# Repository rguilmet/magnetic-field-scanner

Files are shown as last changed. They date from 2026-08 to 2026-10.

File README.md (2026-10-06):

# Magnetic Field Scanner (MFS) Wand


[]()
[]()
[]()

A professional-grade, open-source spatial magnetic gradiometer designed to detect buried ferromagnetic anomalies (property pins, pipes, UXO) by isolating highly localized magnetic gradients from the Earth's background magnetic field.

Powered by an ESP32-S3 and utilizing dual PNI RM3100 magneto-inductive sensors, this device achieves nanotesla-level sensitivity, executing 9-parameter ellipsoidal matrix calibrations and real-time Madgwick AHRS sensor fusion to provide an intuitive, HUD-style radar interface on a high-speed LCD.

---

<p align="center">
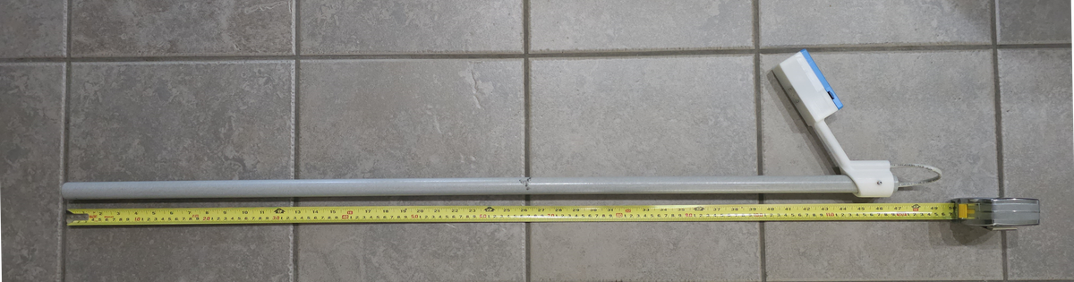
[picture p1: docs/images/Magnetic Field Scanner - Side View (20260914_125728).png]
Magnetic Field Scanner Hardware Side View
  
</p>
<p align="center">
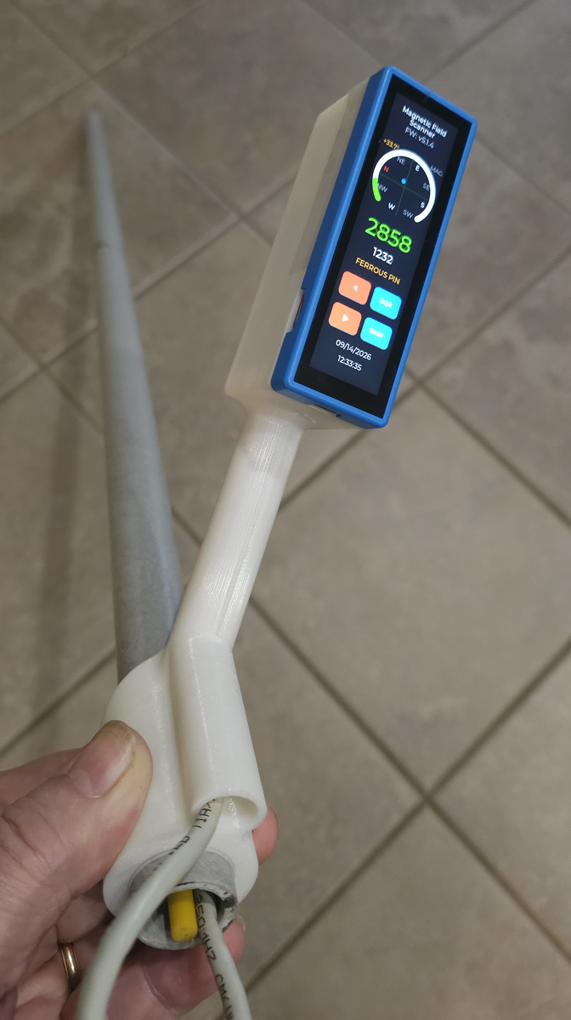
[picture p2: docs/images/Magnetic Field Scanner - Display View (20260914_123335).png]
Magnetic Field Scanner LCD Display View
  
</p>

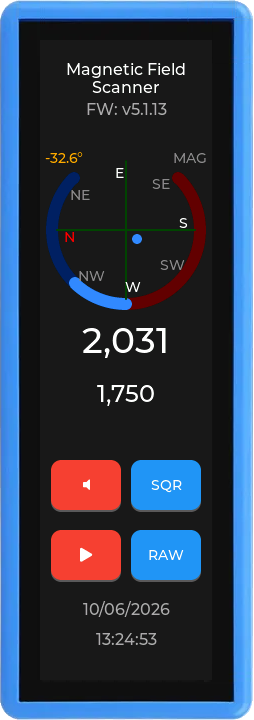
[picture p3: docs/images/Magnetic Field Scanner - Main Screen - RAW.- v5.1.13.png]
HUD Interface - RAW Mode
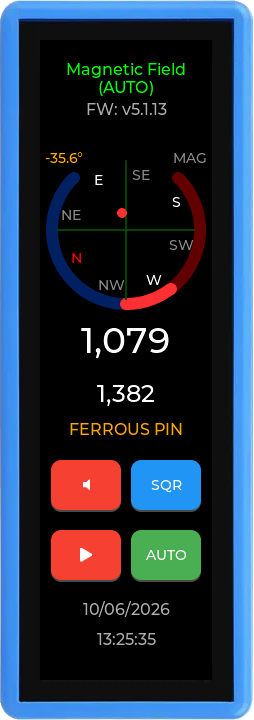
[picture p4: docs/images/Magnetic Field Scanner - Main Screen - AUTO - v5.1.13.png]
HUD Interface - AUTO Mode
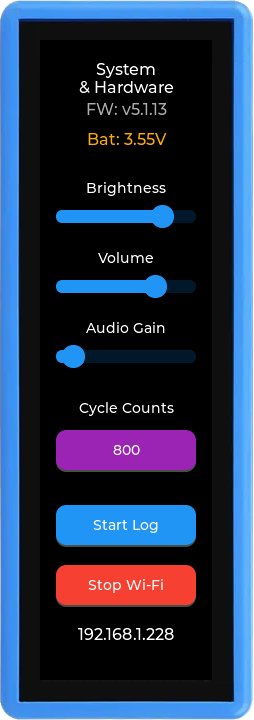
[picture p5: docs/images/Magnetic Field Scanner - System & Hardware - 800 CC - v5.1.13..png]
System Hardware and Diagnostics Screen
|  |  |  |
|:---:|:---:|:---:|

## Hardware Configuration

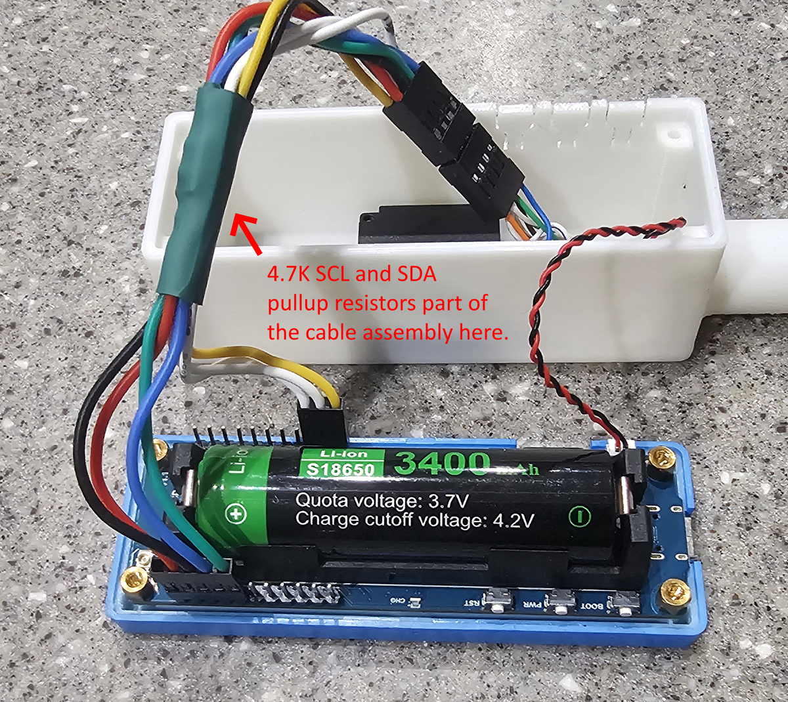
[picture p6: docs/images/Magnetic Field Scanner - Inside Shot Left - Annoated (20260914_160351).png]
Internals Left (I2C Pull-ups)
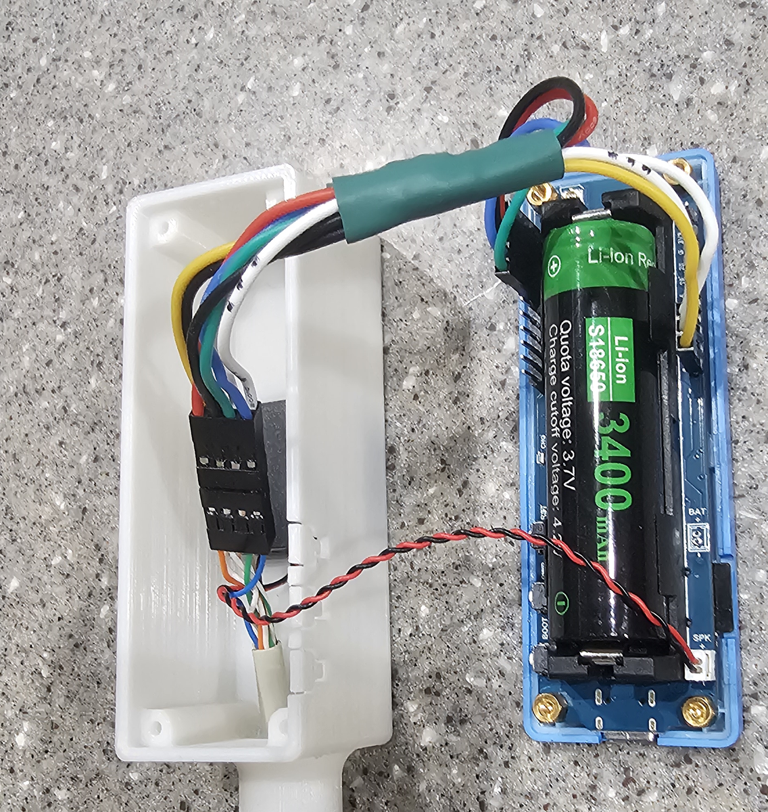
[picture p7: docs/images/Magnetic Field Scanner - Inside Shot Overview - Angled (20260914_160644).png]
Internals Overview
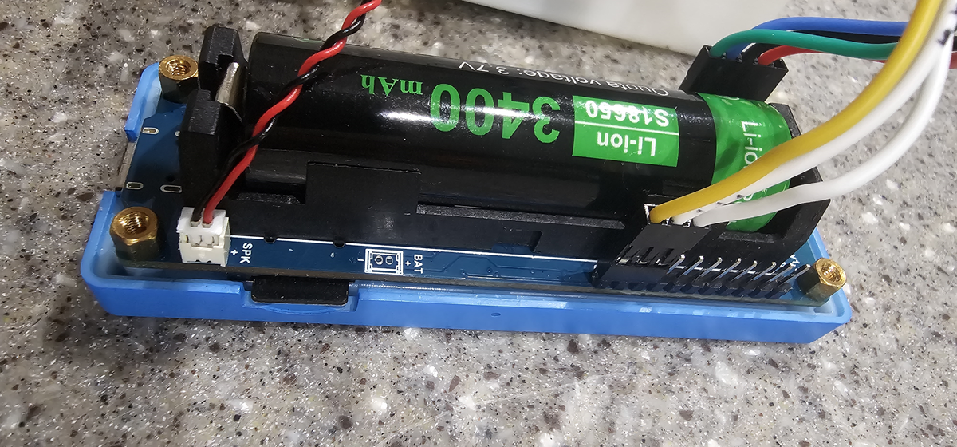
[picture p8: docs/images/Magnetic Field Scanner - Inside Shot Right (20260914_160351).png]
Internals Right
|  |  |  |
|:---:|:---:|:---:|

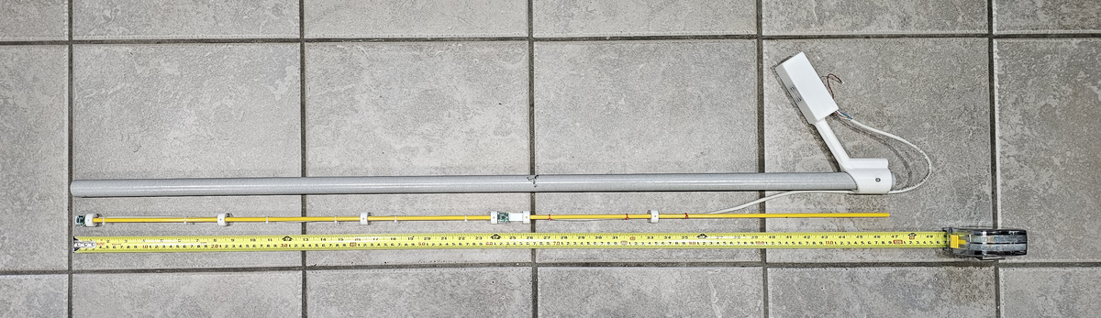
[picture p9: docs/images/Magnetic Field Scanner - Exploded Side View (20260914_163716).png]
Exploded Side View
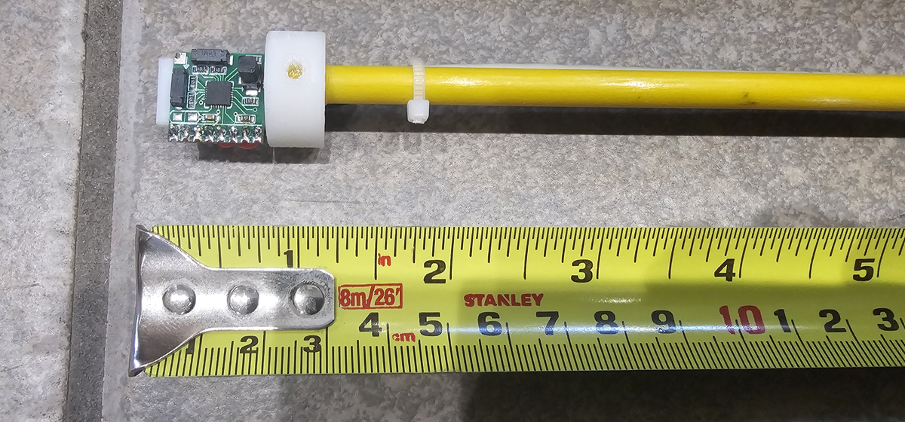
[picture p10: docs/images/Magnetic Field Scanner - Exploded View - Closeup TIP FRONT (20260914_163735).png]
TIP Sensor Front
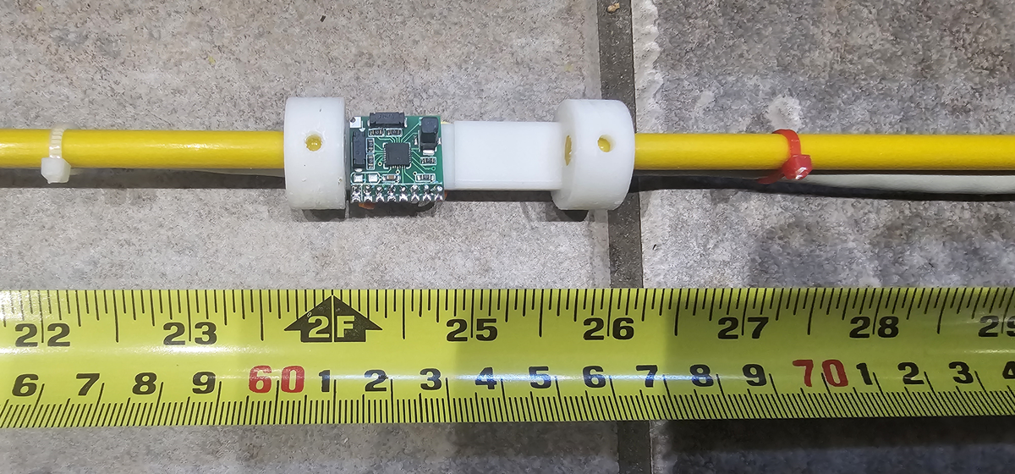
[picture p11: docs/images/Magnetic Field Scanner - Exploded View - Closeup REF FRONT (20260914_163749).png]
REF Sensor Front
|  |  |  |
|:---:|:---:|:---:|

### Core Components
* **Base Platform:** Waveshare ESP32-S3-Touch-LCD-3.49 v3 (PCBA v1.1 silkscreen). This highly integrated device provides the MCU, display, audio, and power management core.
* **MCU:** ESP32-S3 (16MB Flash, OPI PSRAM) embedded on the Waveshare board.
* **Magnetometers:** 2x RM3100 (TIP (at 0") and REF (at 24") sensors), with hardware reserved for a 3rd (NEAR at 8").
* **IMU:** QMI8658 (6-axis Accelerometer & Gyroscope) offset mechanically by 60° relative to the wand axis.
* **Display:** 172x640 QSPI LCD with capacitive touch.
* **Audio Codec:** ES8311 / ES7210 via I2S for audio feedback.
* **Storage:** External SPI SD Card + Internal FFat (Flash).
* **Wiring:** See the [MFS Wiring Diagram](docs/electrical/wiring/MFS_Wiring_Diagram.png).
* **RTC:** PCF85063 for precise timestamping.
* **I/O Expander:** TCA9554 to offload static control pins (Backlight, Resets) and free up high-speed GPIO.

---

## Pin Allocations & Rationale

To support this many peripherals on a single ESP32-S3, strict pin management and an I2C I/O expander are utilized. 

| Feature | GPIO / Pin | Protocol / Type | Rationale |
| :--- | :--- | :--- | :--- |
| **I2C Bus** | SDA: 47, SCL: 48 | I2C | Shared bus for RM3100s, IMU, RTC, and TCA9554 IO Expander (capped at 200kHz for cable capacitance). |
| **I2S Audio** | MCLK: 7, BCLK: 15, WS: 46, DIN: 6, DOUT: 45 | I2S | Full duplex audio codec interface. |
| **SD Card** | CS: 38, MOSI: 39, MISO: 40, SCLK: 41 | SPI | Dedicated high-speed SPI bus for high-bandwidth data logging. |
| **LCD Display** | CS: 9, PCLK: 10, D0-D3: 11, 12, 13, 14, TE: 21 | QSPI / 8080 | High-speed bus dedicated to driving the 172x640 LVGL display. |
| **Battery ADC** | 4 | Analog (ADC1) | Dedicated for battery voltage monitoring. |
| **RM3100 DRDY** | TIP: 3, REF: 2, NEAR: 5 | Interrupt | Direct hardware interrupts for DRDY synchronization. |
| **Future GPS** | TX: 43, RX: 44 | UART | Reserved. Freed up by migrating static control pins to the IO Expander. |

### TCA9554 I/O Expander (Address 0x20)
Used to handle low-speed/static signals to conserve MCU pins:
* **P0:** Touch Interrupt
* **P1:** LCD Backlight Enable
* **P2 / P3:** IMU Interrupts 1 & 2
* **P4:** RTC Interrupt
* **P5:** LCD Reset
* **P6:** System Power Enable (Keep-alive)
* **P7:** Night/Sleep Mode

---

## Software Architecture (v5.x.x)

The software is built on the Arduino ESP32 Core but heavily utilizes ESP-IDF native features and FreeRTOS for professional-grade isolation and performance.

### 1. Synchronized POLL Architecture & FreeRTOS
The `v5.x.x` architecture completely eliminates I2C collisions and phase-drift by orchestrating synchronized measurements:
* **POLL Mode:** The ESP32 broadcasts a simultaneous `REG_POLL` command to both RM3100 sensors across the I2C bus.
* **Event Groups (Core 0):** The Sensor Task sleeps at 0% CPU until both hardware `DRDY` GPIO interrupts assert, guaranteeing absolute temporal synchronization between the Tip and Reference sensors before reading.
* **LVGL UI Task (Core 1):** Handles display rendering, capacitive touch input, and real-time radar / minimap animations without interrupting the rigid I2C sensor polling pipeline.

### 2. Deep Mathematics: Kabsch & Madgwick Algorithms
To achieve military-grade spatial accuracy, the ESP32 natively executes advanced matrix mathematics and 9-axis sensor fusion:
* **Kabsch Rotational Alignment:** The system applies a 9-parameter Least-Squares Ellipsoid Fit (using a Jacobi Eigenvalue solver and the Kabsch Algorithm) to correct for Hard and Soft Iron magnetic distortions caused by the battery and LCD.
* **Madgwick 9-Axis Sensor Fusion:** The raw 3-axis Tip magnetometer data is fused with the QMI8658's 6-axis IMU (Accelerometer and Gyroscope) via an asynchronous Madgwick AHRS filter. This provides real-time Pitch, Roll, and Yaw (Azimuth) compensation to project the magnetic vector accurately to the Earth's gravity vector.
* **Universal Domain Shifting:** The `v5.1.x` architecture converts raw sensor LSBs into normalized physical nanoTeslas (nT) *before* applying the Kabsch calibration matrix. Because the matrix becomes mathematically dimensionless, a single calibration profile works universally across ALL Cycle Counts (12 to 3200).

### 3. Polargraphic Display & UI Scaling
The LVGL Gradiometer UI features a true Log10 Polargraphic Arc that displays the vertical gradient (`trueZ`). The left side (Blue) represents a negative vertical gradient (the 'halo' outside a pin), and the right side (Red) represents a positive vertical gradient (dead-center over a pin).
* **RAW Mode:** Displays the absolute, unadulterated magnetic gradient. The Log10 scale easily absorbs the baseline physical misalignment of the sensors (typically ~4,900 nT) without pinning the needle.
* **TARE Mode:** Manual zeroing of the baseline. It memorizes the current environmental gradient shadow and subtracts it from future readings, allowing extreme sensitivity to tiny localized anomalies.
* **AUTO Mode:** Engages an invisible low-pass filter (triggered under `150 nT`) that acts as an aggressive Auto-Tare to slowly eat away temperature drift and background anomalies while ignoring the sharp gradients of a real target.

### 4. Dual-Drive Filesystem & Integrated Web Server
* **Smart Fallback:** Dynamically routes file I/O to the high-speed SD Card, or falls back to Internal FFat if the card is missing or corrupted.
* **Captive Portal:** Hosts a Web Server allowing seamless download of `.csv` characterization logs and upload of `calibration.json` profiles.

---

## Real-World Capabilities & Detection Depth

The Magnetic Field Scanner is designed as a spatial gradiometer. Because it relies on an empirical RMS noise floor of **±0.33 µT** (at 400 CC), it is highly sensitive to buried ferromagnetic objects.

### Use Case: Locating Property Pins (5/8" Rebar)
A standard 5/8" steel property pin driven vertically into the earth acts as a magnetic monopole, concentrating the Earth's magnetic flux at its tip. 

**Estimated Detection Depth:**
- A vertical 5/8" property pin generates a surface anomaly of roughly `500 µT` at 1 inch.
- Because the wand is a gradiometer with a long handle, the near-field gradient of a monopole decays according to the inverse-cube law (`1/r³`).
- To be reliably detected above the wand's noise floor, the signal needs a minimum Signal-to-Noise Ratio (SNR).
- In a magnetically quiet environment (RAW mode), you can expect to reliably detect a standard vertical property pin buried under **1.5 to 2 feet (18 to 24 inches)** of dirt or concrete.

### Practical Tips for Pin Locating
- **Sweep Low:** Keep the tip sensor as close to the ground as possible. Every inch of air gap costs you an inch of dirt penetration.
- **Use Audio:** Rely on the dynamic FOC audio feedback. The human ear is incredibly adept at picking up the slow frequency rise of a deep anomaly long before the UI screen indicates a massive spike.
- **Vertical vs Horizontal:** Property pins driven vertically are *much* easier to detect than pipes lying horizontally, because the vertical rod concentrates the Earth's magnetic field directly into a concentrated point (a monopole) at the surface.

---

## System Characterization

The wand features a rigid characterization methodology to empirically validate its hardware envelope across multiple Cycle Counts (CC=200, 400, 3200). 
To test your hardware, use the included Python script on your generated `.csv` logs:

```bash
python scripts/characterize_system.py   --noise "log_noise_200.csv" "log_noise_400.csv" "log_noise_3200.csv"   --target "log_target_200.csv" "log_target_400.csv" "log_target_3200.csv"   --ahrs "log_ahrs_200.csv" "log_ahrs_400.csv" "log_ahrs_3200.csv"   --repeatability "log_repeat_200.csv" "log_repeat_400.csv" "log_repeat_3200.csv"   --saturation "log_saturation_200.csv" "log_saturation_400.csv" "log_saturation_3200.csv"   --calibration "cal_1.csv" "cal_2.csv" "cal_3.csv" "cal_4.csv" "cal_5.csv"
```
See `docs/characterization_methodology.md` for full instructions.

---

## Future Expansion Roadmap

The hardware architecture has been deliberately designed to accommodate future capabilities without requiring a PCB spin:

### 1. 3D Depth Sensing (3rd RM3100)
A dedicated interrupt pin (GPIO 5) and I2C address (0x22) have been reserved for a 3rd RM3100 sensor (NEAR). 
* **Purpose:** Enables 2nd-order magnetic gradiometry, allowing the wand to calculate the exact depth of a magnetic anomaly (e.g., a buried pipe) rather than just its presence.

### 2. Spatial Mapping (GPS / RTK)
The static control pins for the LCD and IMU were aggressively offloaded to the TCA9554 I/O expander specifically to free up the hardware UART pins:
* **TX (GPIO 43) / RX (GPIO 44):** Reserved for a high-precision GPS or RTK module. This will allow the wand to fuse magnetic gradient data with precise geographic coordinates, generating professional magnetic survey heatmaps.

## How to Build & Deploy

### Prerequisites
* **Environment:** Arduino IDE v2+ or VSCode/Arduino.
* **Core:** ESP32 Board Package v3.3.x (ESP-IDF v5 based).

### Board Settings (ESP32-S3 Dev Module)
* **USB Mode:** Hardware CDC and JTAG
* **PSRAM:** OPI PSRAM
* **Flash Mode:** QIO 80MHz
* **Flash Size:** 16MB (128Mb)
* **Partition Scheme:** Custom or `app3M_fat9M_16MB`
* **Core Debug Level:** None (for performance)

### Compilation Note
All code files adhere to a strict Semantic Versioning (`vX.Y.Z`) rule enforced at every file iteration. Ensure you are building the latest `user_config.h` baseline.

## Open Source & Contributing
This project is open-sourced under the **GPLv3 License**. See [LICENSE](LICENSE) for details.
We welcome community contributions! Please review our [Contribution Guidelines](CONTRIBUTING.md) before submitting pull requests.

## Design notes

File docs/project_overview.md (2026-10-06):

# Magnetic Field Scanner - Project Overview

**Document Version:** `v1.4.0`
**Last Updated:** October 06, 2026
**Firmware Target:** `v5.1.15`
**Python Ecosystem Target:** `v1.1.1`

This document serves as the master source of truth for the Magnetic Field Scanner project. It details the mechanical assembly, electrical wiring, pinouts, firmware architecture, critical pitfalls to avoid in future development, and the roadmap for upcoming features.

---

## 1. Project Identity, Versioning & Documentation Rules
* **CRITICAL RULE:** All projects shall have a main Software version identifier as `v[Major].[Minor].[Patch]` and follow industry standard semver rules and practices for bumping the version at EVERY file iteration.
* **Why:** We do not reuse version numbers for each iteration. This allows us to distinctly identify in the AI context the files we are working on. The version string is defined as `FIRMWARE_VERSION` in `user_config.h`.

**Documentation Strategy (The "Definition of Done"):**
To prevent documentation rot and excessive maintenance overhead, documentation updates are strictly tethered to the SemVer lifecycle:
* **Patch Releases (e.g., `v3.1.1` -> `v3.0.33`):** Bug fixes and math tweaks. Do *not* update the architectural docs (`project_overview.md`, `user_manual.md`). Log these changes exclusively in the root `CHANGELOG.md`.
* **Minor Releases (e.g., `v3.0.x` -> `v3.1.0`):** Adding new functional features (e.g., GPS integration). The feature is not considered complete until both the `CHANGELOG.md` and the relevant `docs/` Markdown files are updated to reflect the new capabilities.
* **Major Releases (e.g., `v3.x` -> `v4.0.0`):** Massive architectural overhauls (e.g., migrating from I2C to CAN bus). Triggers a comprehensive review and rewrite of all files in the `docs/` directory.

---

## 2. Hardware Architecture & Mechanical Setup
* **The Wand:** Constructed from a rigid 1" fiberglass outer rod with a 3/4" ID.
* **Main Controller (The Handle):** Waveshare ESP32-S3-Touch-LCD 3.49 v2 (172x640 Bar LCD) with an integrated screen, battery ADC, IMU (QMI8658, addr `0x6B`), and RTC (PCF85063, addr `0x51`). This unit sits at the top of the wand acting as the primary handle and UI display. A custom wiring harness runs down from this unit into the main fiberglass tube.
* **The Sensor Array:** The wand acts as a **Magnetic Gradiometer**. It currently utilizes two PNI RM3100 magnetometer breakout boards ("Tip" and "Reference").
  * The boards are mounted to a PLA mechanical carrier that slides directly into the 3/4" ID of the fiberglass tube.
  * **Carrier Rigidity:** To ensure absolute rigidity between the Tip and Reference sensors, the PLA board carriers are physically joined to each other by a solid 1/4" internal fiberglass rod.
  * **Sensor Orientation:** The boards were recently flipped 180 degrees (upside down) in the assembly. 
  * **Physical Misalignment:** There is a permanent, measured physical flex/bend in the carrier assembly of roughly `~9.4` to `~9.8` degrees. The firmware mathematically eliminates this using the Kabsch alignment algorithm.

### True Vertical Gradient (trueZ) & Dipole Physics
In firmware v5.1.15, the wand implements true magnetic dipole physics. The absolute magnitude of the magnetic field (nT) is highly useful, but it does not tell the user *what* they are looking at or *where* the edges are. 
By projecting the 3D magnetic gradient vector against the Earth's Gravity (Down) Vector (which is derived from the IMU's quaternion), the wand isolates `trueZ`—the pure vertical component of the magnetic gradient.
* **Vertical Property Pins:** Behave as vertical magnetic dipoles. Sweeping dead center over the top pole (South pole) results in a massive POSITIVE `trueZ` (field lines pointing straight down). Sweeping off to the side results in a NEGATIVE `trueZ` (field lines pointing back up). This creates a sharp "halo" effect that allows pinpoint centering.
* **Horizontal Pipes / Rebar:** Behave as horizontal magnetic dipoles. Sweeping perpendicular across the center of a horizontal pipe yields massive absolute magnitude, but a `trueZ` of zero, because the field lines are purely horizontal.

### Polargraphic Display & Log10 Scaling
To visually represent the `trueZ` physics, the UI features a symmetrical Polargraphic Arc.
* **Polarity:** Left (Blue) represents Negative vertical gradient. Right (Red) represents Positive vertical gradient.
* **Log10 Scaling:** The arc is driven by a `log10((nT/100)+1)` curve. This provides extreme visual sensitivity to tiny signals at long range, while allowing the arc to dynamically scale all the way up to 1,000,000+ nT without "pegging" when the wand is an inch away from a massive target.

### Mechanical Diagram
(Assuming visual diagram exists elsewhere)

### Sensor Coordinate Systems & Axis Alignment (Phase 7 Discovery)
Because the BMI270 IMU and the dual RM3100 Magnetometers are mounted to the same rigid Wand structure, they must speak the exact same 3D spatial language for sensor fusion (Madgwick 9-DOF) to work. A live logging "Alignment Dance" revealed the exact physical orientation of the chips on the Veroboard. 

**The IMU (BMI270) Coordinate System (Right-Handed):**
* +X Axis: Points **Forward** (Towards the sensor tip)
* +Y Axis: Points **Left**
* +Z Axis: Points **Up** (Out of the LCD Screen)

**The Magnetometer (RM3100) Coordinate System (Left-Handed):**
Due to the physical mounting of the breakout boards inside the wand, the RM3100 acts as a Left-Handed coordinate system relative to the IMU.
* +X Axis: Points **Left**
* +Y Axis: Points **Forward**
* +Z Axis: Points **Down** (Into the ground)

**The Translation Key:**
To safely feed the Magnetometer data into the Right-Handed 9-DOF Madgwick algorithm, the software applies the following mathematical mapping to the RM3100 (
efX_cal, refY_cal, refZ_cal) values:
`c
float mag_x =  (float)ref.y;  // Maps RM3100 Forward to IMU Forward
float mag_y = -(float)ref.x;  // Maps RM3100 Right to IMU Left
float mag_z = -(float)ref.z;  // Maps RM3100 Down to IMU Up
`
This permanently locks the Quaternions to True Magnetic North for accurate post-analysis mapping.
*(Please place your mechanical drawing in a folder named `docs` in the project root and name it `mechanical_drawing.png` or update this link to point to it).*
Mechanical Drawing of Wand and Waveshare

---

## 3. Wiring & Pinout Assignments

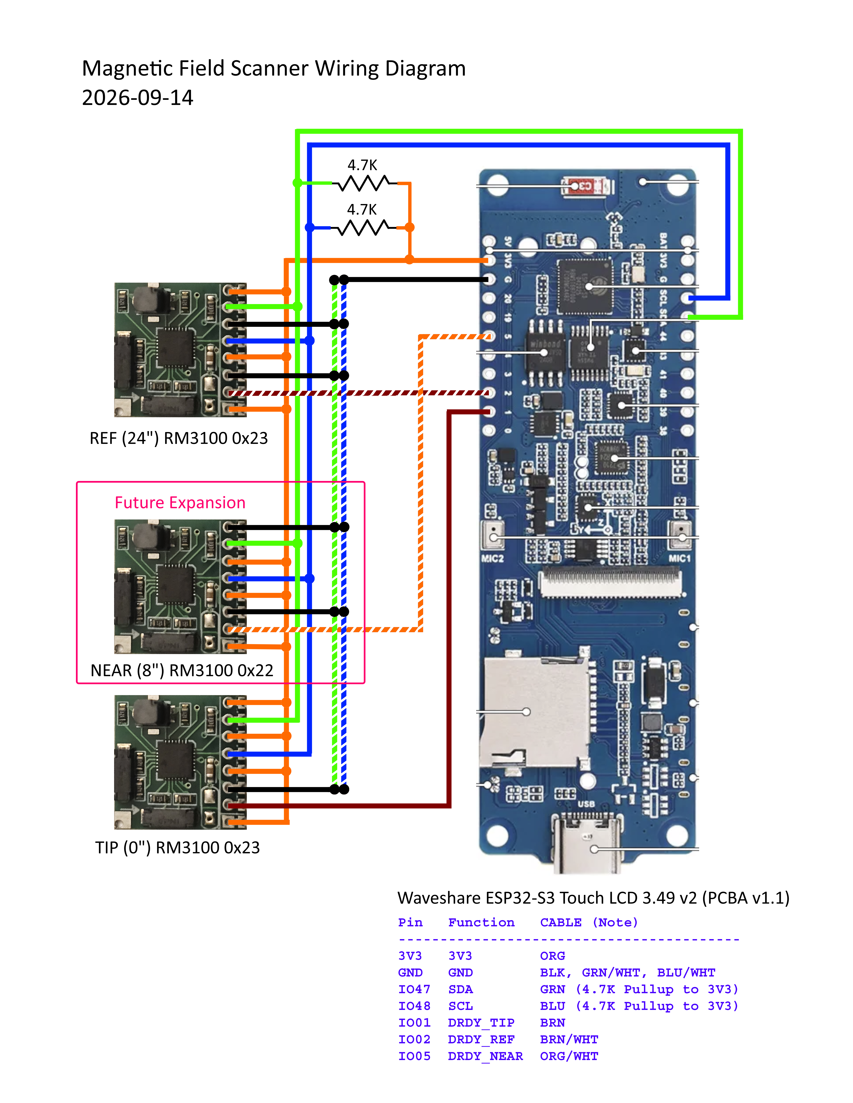
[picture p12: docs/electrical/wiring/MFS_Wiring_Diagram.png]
MFS Wiring Diagram


### CRITICAL HARDWARE NOTE: I2C Pull-Up Resistors
* **The RM3100 breakout boards DO NOT have built-in I2C pull-up resistors.**
* **The Fix:** We permanently installed **4.7K pull-up resistors** in the cable harness directly at the Waveshare connection end (SDA/SCL to 3.3V).
* **The Result:** Combined with the Waveshare's internal pull-ups, this provides a "stiff" ~2K to ~3K ohm equivalent resistance, which is perfect for fighting the heavy capacitance of the 3-foot cable run down the wand.

### CAT6 Wire Harness & Color Coding
The internal harness from the Waveshare board to the sensor array utilizes a standard CAT6 twisted-pair cable. It perfectly allocates all 8 wires to support three RM3100 sensors while maximizing electrical integrity over the 48" run.

For the full visual diagram, reference the spreadsheet: docs/electrical/Cable_Color_Code.xlsx.

| Component / Function | ESP32 Pin | CAT6 Color | Twisted Pair Strategy (Signal Integrity) |
| :--- | :--- | :--- | :--- |
| **3.3V Power** | 3V3 | Orange | **Power & Sync:** Twisted with DRDY_NEAR. DC power acts as an AC ground, shielding the digital pulse. |
| **DRDY_NEAR** | IO05 | Orange/White | *(Future 3rd Sensor)* |
| **SDA (Data)** | IO47 | Green | **I2C Data Shield:** Twisted directly with GND to prevent capacitive crosstalk against SCL. |
| **GND** | GND | Green/White | |
| **SCL (Clock)** | IO48 | Blue | **I2C Clock Shield:** Twisted directly with GND to prevent signal degradation. |
| **GND** | GND | Blue/White | |
| **DRDY_TIP** | IO01 | Brown | **Digital Sync:** Hardware data-ready interrupt signals. |
| **DRDY_REF** | IO02 | Brown/White | |

### I2C Architecture & Device Addresses
The wand utilizes two completely separate hardware I2C buses to isolate the sensitive long-wire sensors from the noisy high-speed screen components.

#### 1. I2C0 (External Sensor Bus)
* **Purpose:** Drives the long wire harness running down the 3-foot fiberglass tube to the RM3100 sensors.
* **Speed:** Hardcoded to **100kHz** to fight cable capacitance.
* **Pins:** SCL: `48`, SDA: `47`
* **Devices on Bus:**
  * **RM3100 Tip:** `0x23` (DRDY: `GPIO 1`)
  * **RM3100 Ref:** `0x21` (DRDY: `GPIO 2`)
  * **RM3100 Mid (Future):** `0x22` (DRDY: `GPIO 5`) *(Reserved for planned 3rd sensor)*
* **CRITICAL CONFLICT HISTORY (Address `0x20`):** Initially, an RM3100 was set to address `0x20`. This caused a total system failure because the Waveshare board has an undocumented internal I/O Expander hardcoded to `0x20`. **Never use `0x20` on the sensor bus**, even though the buses are logically separated; we mapped the RM3100s to `0x21`, `0x22`, and `0x23` to safely avoid any internal hardware routing conflicts.

#### 2. I2C1 (Internal Waveshare Bus)
* **Purpose:** Local communication for the Waveshare board's integrated SMD components.
* **Pins:** SCL: `18`, SDA: `17`
* **Devices on Bus:**
  * **Capacitive Touch Controller:** `0x3B`
  * **RTC (PCF85063):** `0x51`
  * **IMU (QMI8658):** `0x6B`
  * **I/O Expander:** `0x20` *(The source of the conflict mentioned above)*

### Other Master Pinouts (Defined in `user_config.h`)

| Component | Pin (GPIO) | Notes / Details |
| :--- | :--- | :--- |
| **SPI (SD Card)** | CS: `38`, MOSI: `39`, MISO: `40`, CLK: `41` | Used by `wifi_logger.cpp` to save `calibration.csv` and logs. |
| **GPS Module** | TX: `43`, RX: `44` | *Planned Future State.* |

---

## 4. Critical Engineering Decisions & Pitfalls to Avoid

### A. I2C Bus Speed & Time Constants
* **The Mistake:** Attempting to run the hardware I2C bus at 400kHz ("Fast Mode") over a 60-inch unshielded CAT6 cable. The physical capacitance caused mushy square waves. The ESP32 missed ACK bits, resulting in `0,0,0` readings, massive garbage spikes, and frequent "Sensor Lockup" panics. 100kHz was extremely stable but too slow for high-speed logging.
* **The Fix:** The I2C speed (`scl_speed_hz`) in `i2c_bsp.c` is hardcoded to `200,000` Hz. This is the "Goldilocks" zone that perfectly balances RC time constant degradation against the bandwidth needed to poll both sensors at 150Hz. 

### B. EMI "Meteors", Slew Rate, & Absolute Filters
* **The Problem:** Even at 200kHz, the long I2C wires act as antennas. Microscopic bit-flips (EMI glitches) occasionally jump the raw reading by 2,000 to 5,000 counts in a single frame, causing the audio UI to emit a terrifying shriek ("cosmic meteors").
* **Slew Rate Filter:** If any single axis on either sensor jumps by more than **800 counts** in a single frame, it is mathematically deemed physical EMI and the frame is dropped.
* **Absolute Magnitude Glitch Filter (MFS_MAX_GLITCH_MAGNITUDE):** Protects against catastrophic I2C garbage data (e.g. 140,000 counts). *CRITICAL PITFALL:* This threshold MUST be set >250,000. At CC=3200, the raw sensor gain is so massive that perfectly valid measurements hit ~120,000 LSB. Setting this threshold too low (e.g. 50,000) will cause the software to silently reject every single CC=3200 frame, freezing the display and log entirely!

### C. Watchdog Timer (TWDT) Panics
* **The Problem:** Processing a 3,000-line `calibration.csv` file from the SD card using `String` operations in `wifi_logger.cpp` takes more than 5 seconds. The ESP32 FreeRTOS Task Watchdog Timer assumed the system was frozen and triggered a hard panic reboot right at 99% completion.
* **The Fix:** Ensure heavy processing loops (like file parsing) contain a `vTaskDelay(pdMS_TO_TICKS(10));` every 100 iterations to "pet the watchdog" and yield to the OS.

### D. Sensor Lockup Logic & Hardware Watchdog
* **The Problem:** The I2C bus will occasionally hang due to environmental EMI. Previously, a 5000ms I2C driver timeout would starve the `IDLE0` task and trigger a fatal ESP32 Task Watchdog Panic reboot. 
* **The Fix:** The I2C driver timeouts (`i2c_data_pdMS_TICKS`) are clamped to `50ms`. If the bus hangs, it fails gracefully. The main `SensorTask` implements a robust software watchdog that resets the RM3100s via `initRM3100()` under three conditions:
  1. **Stuck Data:** If the sensor returns exactly `0,0,0` for 10 consecutive frames (I2C read failure). *CRITICAL PITFALL:* Do not trigger on identical valid values (e.g. `tip.x == last_tip.x`)! The RM3100 noise floor is so low that a perfectly still sensor will trigger false-positive lockups!
  2. **DRDY Timeout:** If the `DRDY` event group times out after **1000ms**. *CRITICAL PITFALL:* CC=3200 physics takes ~480ms to measure. If the timeout is set to 500ms, the ESP32 will panic and reset the sensor *before it finishes*, causing an infinite freeze loop!
  3. **Blind Recovery I2C Reads:** When recovering from a timeout, NEVER issue a blind `i2c_read_buff` to the RM3100 unless you have verified via `digitalRead()` that the DRDY pin is physically stuck HIGH. Reading a busy RM3100 will crash its internal silicon and permanently hang the I2C bus!

### D2. RM3100 TMRC Internal Glitching
* **The Physics:** `TMRC` defines the update rate in Continuous Measurement Mode. The datasheet claims that if `TMRC` is set faster than the Cycle Count allows, it will "automatically override" and run at max speed.
* **The Reality:** While true, constantly bombarding the RM3100's internal state machine with 600Hz `TMRC` ticks while it is busy calculating a slow 400 CC measurement causes random silicon glitches, resulting in the sensor missing beats and dropping `DRDY` (triggering the watchdog). 
* **The Fix:** `initRM3100()` must use a rigorous mapping table to ensure the `TMRC` value is always safely **slower** than the physical Cycle Count math execution time.

### E. Universal Cycle Count Scaling (v5.x.x)
* **The Physics:** When the user changes the Cycle Count (CC) on the fly, the RM3100's raw output scales non-linearly due to Zero-Field Offsets (ZFO).
* **The Code (Pre-Normalization):** To eliminate drift and scaling errors, the `v5.1.4+` architecture intercepts raw LSB counts and immediately normalizes them to physical nanoTeslas (`nT`) using the exact `CC` gain scalar *before* any calibration is applied.
* **Universal Matrices:** Because the Kabsch calibration algorithm now operates entirely in the physical `nT` domain, the resulting Hard and Soft Iron matrices are mathematically dimensionless. You can calibrate the wand at 400 CC, and perfectly seamlessly jump to 3200 CC without re-calibrating or scaling the matrices!

### F. Auto-Tare vs Manual Tare
* **Manual Tare:** Memorizes the current environmental gradient shadow (e.g., standing near a car) and subtracts it from all future readings. Should only be performed in a magnetically "clean" area.
* **Auto-Tare:** Implements a low-pass filter (multiplier `0.005`) that slowly and invisibly pulls the baseline back to zero over time. Crucially, it **only engages if the gradient jumps by less than 150 nT**. This eats away slow temperature/geology drift while completely ignoring the sharp spikes of a buried utility pipe!

### G. Windows CLI Path Handling (Python)
* **The Problem:** When dragging and dropping files into Windows PowerShell or Command Prompt to pass arguments to Python scripts, Windows automatically wraps the filepath in literal double-quotes (e.g., `"C:\path\to\file.csv"`). Python's `argparse` absorbs these literal quotes as part of the string, causing `os.path.exists()` to fail and crash the script. 
* **The Fix:** All Python companion scripts in this project universally sanitize `argparse` inputs using `os.path.normpath(args.input.strip('\'"'))` before interacting with the file system. This strips accidental terminal quotes and normalizes slashes, bulletproofing the CLI against Windows pathing quirks.

---

## 5. Current State of the Project
* **Core Functionality:** The Gradiometer math (`Tip - Ref`) is fully operational and extremely sensitive.
* **On-Device Calibration:** Functional. `matrix_math.h` performs a 9x9 Jacobi eigenvalue solver and 3D ellipsoid fit using only local stack memory. It applies Kabsch alignment to precisely orient the Tip sensor onto the Reference sensor's frame, nullifying the 9-degree mechanical flex.
* **Data Logging:** SD card saving is stable. Python companion scripts (`calibrate_wand.py` and `plot_pins.py`) can ingest `_log.csv` and `_calibration.csv` files to visualize the exact sweeping motions using IMU Gyroscope Z-axis tracking.
* **Audio & UI:** LVGL runs successfully on Core 1 while the bitbanging/I2C sensor tasks run on Core 0. (Note: `lv_conf.h` must remain in the root directory due to library constraints).

---

## 6. Companion Software Ecosystem (Python)
The repository includes a suite of offline Python processing scripts located in the `scripts/` directory. All official scripts adhere to SemVer versioning, contain industry-standard header documentation, and utilize `argparse` for robust command-line `--help` functionality.

* **`calibrate_wand.py`:** Ingests raw `calibration.csv` datasets, computes the 3x3 Soft-Iron matrices (W) and Hard-Iron center offsets (V), applies Kabsch rotational alignment, and outputs a drop-in `calibration.json` file.
* **`generate_plots.py`:** Specialized utility for visualizing 3D ellipsoid point clouds to verify the mathematical perfection of the sphere-fitting algorithms.
* **`analyze_log.py` (Formerly `plot_pins.py`):** Ingests live field operation logs (`_log.csv`) and generates a synchronized 3-pane matplotlib dashboard showing Gradient Magnitude, Audio Frequency response, and IMU Gyroscope Z-axis (Yaw) to visually correlate physical sweeping motions with underground utility strikes.

---

## 7. Planned Future State (Roadmap)
1. **Third Sensor Integration (Near):** 
   * A third RM3100 sensor will be mounted at 8 inches from the TIP.
   * I2C Address: `0x22`
   * DRDY Pin: `GPIO 5`
   * Purpose: To allow quadratic gradient tracking and depth-estimation of buried targets.
2. **GPS Module Integration:**
   * Serial unit to be added to pins `IO43` (TX) and `IO44` (RX).
   * Purpose: To embed geospatial coordinates into the SD log files, allowing post-processing software to map buried utilities directly onto a satellite view.

## 8. Sensor Fusion (Madgwick 9-DOF) & IMU Mathematics

The firmware utilizes a hyper-optimized implementation of Sebastian Madgwick's AHRS (Attitude and Heading Reference System) to fuse the BMI270 (Accel/Gyro) and RM3100 (Magnetometer) into a buttery-smooth 3D quaternion vector. This allows the wand to project the gradient magnitude perfectly onto the flat horizontal plane (Radar Dot) and ignore false signals generated by tilting the wand.

### A. Coordinate System Alignment (NED)
Because the RM3100 and the IMU are physically mounted in different orientations, they are mathematically mapped into a strict **North-East-Down (NED)** coordinate system before fusion. 
* **Accelerometer:** (-accX, accY, accZ)
* **Magnetometer (Ref):** (refY, refX, refZ)
* **Gyroscope:** (gyrX, -gyrY, -gyrZ)

### B. Display Enclosure Mechanical Tilt (imu_rotation_deg)
The BMI270 IMU is located inside the display head, which is physically pitched UP by 60 degrees relative to the straight wand tube. 
* To prevent the math from permanently thinking the wand is aiming at the sky, a mathematical rotation is applied to un-tilt the IMU readings.
* **Order of Operations (CRITICAL):** 
  1. Gyro Hardware FOC (Zero-Rate Offset) is subtracted from the raw silicon axes.
  2. The NED axes are mathematically rotated by -cal_config.imu_rotation_deg (Negative to *un-rotate* the positive physical pitch).
  3. The FOC-corrected, rotated axes are converted to Radians and fed into Madgwick.
  
### C. Gyroscope FOC & Dynamic Auto-Zero (Tare)
MEMS Gyroscopes (like the BMI270) suffer from thermal drift and high "g-sensitivity" (where laying the wand on its side causes gravity to pull the silicon mass differently, altering the zero-rate offset by up to 4 dps). A static calibration file is completely insufficient to cancel this.
* **The Solution:** The `SensorFusion` class implements a real-time **Dynamic Auto-Zero** algorithm.
* It maintains a silent 1-second rolling buffer of the Accelerometer and Gyroscope.
* If the variance of the Accelerometer drops below 0.001g (meaning the wand was set down on a desk/ground), it instantly recalculates the Gyroscope FOC from the buffer and updates the RAM seamlessly.
* This completely eliminates Elevation and Azimuth drift regardless of temperature or resting orientation.

### D. The Madgwick Math Quirks
* **Degrees vs Radians:** The C implementation of MadgwickAHRS strictly expects the Gyroscope input in **Radians per second**. Feeding it Degrees per second will amplify gyroscope noise by 57.3x, causing violent continuous wobble (hunting for equilibrium) as the filter wrestles with the Accelerometer.
* **Dynamic Time Delta (`dt`):** Rather than relying on a static `sampleFreq` define (which creates time-dilation distortion when hardware cycle counts alter update rates from 150Hz down to 9Hz), `SensorFusion` dynamically measures elapsed microseconds (`micros()`) between frames and passes `float dt` directly into `MadgwickAHRSupdate`. This guarantees rapid, rock-solid attitude convergence across all cycle count settings.

---

## 9. Firmware Architecture & Single Responsibility Principle
Following the Phase 3 structural refactor, the firmware heavily adheres to the **Single Responsibility Principle (SRP)**. Monolithic files have been rigorously decomposed to prevent cross-domain contamination, particularly between Core 0 (Sensor/SD) and Core 1 (UI/Web).

### src/ Directory Breakdown:
* **sensor_fusion/**: A dedicated, stateful C++ class that handles all 3D matrix algebra, auto-tare EMA filtering, Madgwick AHRS updates, and vector geometry for the radar dot. Extracts all dense math from the main `.ino` loop.
* **data_logger/**: Solely responsible for writing CSV data to the SD card/FFat and handling file flushes.
* **settings_manager/**: Exclusively manages the saving, loading, and JSON serialization of SystemSettings and CalibrationConfig.
* **web_server/**: A pure UI/networking layer running on Core 1. It handles HTTP endpoints, file downloads, uploads, and OTA operations without directly touching hardware logic.
* **screenshot/**: Isolated LVGL screen capture logic (RGB565 to BMP conversion).
* **lvgl_port/**: Handles the physical drawing of the screen and UI layout.
* **matrix_math/**: A pure, header-only implementation of the 9x9 Gaussian elimination and 3D Kabsch alignment algorithms.
* **Hardware BSPs (i2c_bsp, imu_bsp, 
tc_bsp)**: Board Support Packages that isolate the direct register-level I2C commands from the main business logic.

**Core Separation & Thread Safety:**
* **Core 0 (Data/Hardware):** 	ask_sensor_read, 	ask_battery_monitor, 	ask_audio_alert. I2C reads and fast math.
* **Core 1 (UI/Network):** 	ask_display_update (LVGL), mfs_button_pwr_task, WiFi server.
* **Mutexes:** mfs_lvgl_lock() must be acquired before touching UI elements from Core 0. log_mux must be acquired before writing to logFile.

## 10. Critical Hardware Quirks & Engineering Notes

### 1. Battery Power Keep-Alive Latch (SYS_EN)
When powering on the ESP32 via the physical battery button, the hardware PMIC requires the ESP32 to quickly assert the \SYS_EN\ pin HIGH (via the TCA9554 IO Expander on I2C) to latch the power circuit on.
* **The Pitfall:** If the firmware waits for a Serial connection or performs long blocking tasks before initializing the IO Expander, the user will be forced to physically hold the power button down for several seconds. If they let go early, power is cut instantly.
* **The Solution:** The I2C bus (\i2c_master_Init()\) and the IO Expander (\esp_io_expander_set_level(io_expander, MFS_EXIO_PIN_SYS_EN, 1)\) must be executed as the absolute very first commands in \setup()\, BEFORE any \while(!Serial)\ delay loops.

### 2. True Polling Rates (v5.1.4 ISR Architecture)
The firmware utilizes a true zero-latency ISR architecture driven by FreeRTOS Event Groups. The sensor task sleeps at 0% CPU until the RM3100 hardware asserts the DRDY interrupts, at which point it wakes and reads instantly. 

The polling rate is exclusively governed by the RM3100 `TMRC` hardware register, which is dynamically mapped to be safely slower than the physics of the Cycle Count (CC):
* **CC 200:** 150 Hz (`0x94`)
* **CC 400:** 37 Hz (`0x96`) - Default
* **CC 800:** 18 Hz (`0x97`)
* **CC 1600:** 9 Hz (`0x98`)
* **CC 3200:** 4.5 Hz (`0x99`)

**Logging Decimation:** To prevent SD Card SPI latency from dropping frames at 150Hz, the data logger decimates 200 CC readings by half (logging at 75Hz) while keeping the math and UI running at the full 150Hz.

## 3. RM3100 Sensor Physics & Limitations
Through extensive physical characterization, we have identified two distinct failure modes for the RM3100 sensors when exposed to massive magnetic anomalies:

### Digital Clipping Limit (Integer Overflow)
The maximum valid magnetic field the hardware can compute is inversely proportional to the Cycle Count (CC). The RM3100 works by counting high-frequency oscillator pulses over a set number of LR cycles.
* **At low CC (e.g., 200 CC, 400 CC, 800 CC):** The measurement cycle is extremely fast. Because it is fast, the internal 24-bit counter has a massive dynamic range and will not digitally overflow until exposed to immense fields (> 500 µT).
* **At high CC (e.g., 3200 CC):** The measurement cycle stays open 16x longer. Because it counts for so long, a strong field will cause the internal register to mathematically wrap/overflow much sooner. At 3200 CC, the digital clipping limit is roughly **~88 µT** (or ~20 µT if perfectly aligned to a single axis).

### Physical Core Saturation (The "Blind State")
If a massive magnetic anomaly (such as a neodymium rare-earth magnet) is brought within inches of the sensor, the magnetic field exceeds the physical B-H curve limit of the tiny LR inductor core.
* When this occurs, the core's magnetic permeability drops to that of air, and the inductance collapses. 
* The RM3100 fails to oscillate and outputs a raw count of practically `0`.
* Because the Tip sensor goes "blind" (`0` nT), the Gradiometer math (`| Tip - Reference |`) will simply output exactly what the Reference sensor is reading.
* This results in the wand falsely displaying a steady-state value of **~60 µT** (the Earth's background magnetic field) during a massive $>500$ µT event.
* **Important:** This is why the Open Air Rebar test (which concentrates the Earth's field but isn't a permanent magnet) is used to test the *Digital Clipping Limit*, while a Neodymium magnet forces *Physical Core Saturation*.

### The Gradiometer Return Path ("Destructive Null Dip")
Because the reference sensor is mounted ~24 inches behind the tip sensor on the wand handle, it sits directly inside the near-field magnetic return path of large linear dipoles (like a 36-inch rebar). While the tip sensor measures a massive positive spike as the rebar approaches, the reference sensor measures the negative return-flux pulling in the opposite direction. This opposing flux subtracts from the Earth's background field, causing the reference sensor to measure a distinct "dip" (e.g., dropping from 50 µT down to 48 µT). This proves the spatial gradiometer geometry is successfully interacting with the 3D footprint of the anomaly.

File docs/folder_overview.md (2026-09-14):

# Repository Review & Publishing Guide (Updated)

**Document Version:** `v1.4.0`
**Last Updated:** September 14, 2026

**Objective:** Assess the project structure to determine readiness for GitHub and Hackaday, and provide a roadmap to round it out for the global open-source community.

## 1. Is it Worthy of Sharing?
**Absolutely, 100% Yes.** 
The ability to perform a 9x9 Jacobi eigenvalue solver and a 3D Kabsch rotational alignment natively on an ESP32 microcontroller—entirely bypassing the need for a PC—is a massive technical achievement. Combined with the elegant Slew-Rate filtering and real-time Audio UI, this is exactly the kind of deep engineering that the Hackaday and GitHub communities celebrate.

## 2. Directory Structure Review (Current State)

### What is Excellent:
* **The Root is Pristine:** All heavy architectural documentation has been moved to `docs/`, and AI scratch files have been purged. The root now perfectly functions as a storefront, containing only `README.md`, `LICENSE`, `CHANGELOG.md`, and the core `.ino` / configuration files.
* **`CHANGELOG.md`:** Implementing the "Keep a Changelog" standard in the root is highly professional and separates bug-fix noise from architectural documentation.
* **`docs/mechanical/`:** A masterclass in open-source hardware organization. Neatly categorizing `dwg`, `SolidEdge`, and `stl` files ensures that makers of all skill levels can replicate or modify the 3D printed components.
* **`docs/datasheets/`:** Bundling the manufacturer datasheets locally prevents link-rot and guarantees the project's immortality.
* **`characterization/`:** Replaced the obsolete `example_logs` and `golden-files`. It serves as the ultimate testing ground containing highly structured, multi-CC logs (noise, rebar, saturation, ahrs) for mathematically proving the `v5.1.x` architecture.
* **`docs/reports/`:** A fully consolidated output directory where the Python ecosystem dynamically saves all automatically generated Markdown analysis reports and Matplotlib graphs, eliminating root folder clutter.
* **`scripts/`:** The offline Python ecosystem (`analyze_log.py`, `calibrate_wand.py`, `generate_plots.py`) is completely commercial-grade, featuring `argparse` CLIs, Windows path sanitization, and independent SemVer (`v1.0.0`).
* **`src/`:** Excellent modularization of the C++ components (`matrix_math`, `wifi_logger`, `lvgl_port`, etc.).

## 3. Open-Source Replication Assets
To make this a top-tier Hackaday project, the repository provides a complete path for someone else to replicate your electrical build:

### A. Bill of Materials (BOM)
* Found in `docs/project_bom.md` and `docs/project_sbom.md`.
* Includes all links and specs for: Waveshare ESP32-S3-Touch-LCD (3.49/4.3), PNI RM3100 breakout boards, Fiberglass rods, 4.7K resistors, battery, and wire.

### B. The Wiring Diagram
* The `docs/electrical/wiring/` folder contains the official wiring diagrams (`MFS_Wiring_Diagram.png`) and cable color codes.
* This fulfills a critical requirement for open-source electrical replication.

## 4. Recommended Photography (For Hackaday / README)
1. **[COMPLETED] The Hero Shot:** The current `Display View` and `Side View` photos are excellent and fully satisfy this requirement. An outdoor shot is a nice-to-have, but your current hero shots already look highly professional.
2. **[COMPLETED] The "Guts" (Crucial):** The new `Inside Shot Overview` photos cleanly expose the PLA sensor carrier, the 1/4" rod, and the internal mounting layout.
3. **[COMPLETED] The I2C Hack:** The `Inside Shot Left - Annotated` image points exactly to the 4.7K pull-ups under the shrink wrap, making the electrical replication trivial.
4. **[COMPLETED] The UI in Action:** The three `Main Screen` screenshots (RAW, TARE, AUTO) perfectly satisfy this requirement.

---

## 5. Publishing Checklist

### What You Have (Ready)
- [x] Functional, stable firmware (v5.1.4)
- [x] Advanced DSP math & On-Device Calibration
- [x] Professional Python CLI visualization and calibration scripts (`scripts/`)
- [x] Open-source License (GPLv3)
- [x] Deep architectural documentation (`docs/`)
- [x] Version-controlled `CHANGELOG.md` in root
- [x] Purged AI Scratch Files & Obsolete Folders (`reports/`, `plots/`, `example_logs/`, `golden-files/`)
- [x] Consolidated all Script Outputs to `docs/reports/`
- [x] Built the `characterization/` Data Library
- [x] Complete Mechanical Asset Library (`docs/mechanical/`)
- [x] Localized Manufacturer Datasheets (`docs/datasheets/`)
- [x] Complete hardware Bill of Materials (`docs/project_bom.md`)
- [x] Electrical Wiring Diagram (`docs/electrical/wiring/`)
- [x] Hero Photography (`Display View` and `Side View`)
- [x] UI in Action Photography (`Main Screen` RAW/TARE/AUTO shots)
- [x] Internal Assembly Photography ("Guts" and annotated I2C Hack shots)

### What You Need (To-Do)
- [x] **Nothing.** The repository documentation is 100% physically replicable and ready for Hackaday!

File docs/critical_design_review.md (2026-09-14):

# Critical Design Review (CDR)
**Architecture Version:** `v5.1.x`
**Perspective:** Principal Software Engineer / Systems Architect

## 1. Executive Summary
The Magnetic Field Scanner `v5.1.x` represents a fundamental paradigm shift from legacy polling loops to a deterministic, RTOS-driven sensor fusion engine. This document serves as the formal architectural record of the mathematical and hardware-level breakthroughs that allow the ESP32-S3 to achieve true nanotesla-level spatial gradiometry.

## 2. The I2C Phase Collision & The POLL Architecture
In legacy versions (`v4.x.x`), the RM3100 sensors were placed in Continuous Measurement Mode (CMM). The ESP32 would wait for a hardware `DRDY` (Data Ready) interrupt and blindly fetch the results.

### The Problem: Sensor Lapping
Because the ESP32 handles dynamic SD Card writes and complex LVGL UI rendering, the I2C polling loop was occasionally subjected to latency spikes (e.g., waiting for an SD card block flush). While the ESP32 was blocked, the RM3100 sensors continued measuring autonomously. If a sensor finished a *second* measurement before the ESP32 fetched the *first*, the sensor would hold the `DRDY` pin permanently `HIGH` and refuse to clock out data, resulting in a permanent bus lockup.

### The Solution: Deterministic POLL Mode
In `v5.1.x`, we completely stripped the sensors of their autonomy. 
The RM3100 is now operated exclusively in **POLL Mode**. 
1. The ESP32 broadcasts a simultaneous `REG_POLL` command to all sensors across the I2C bus.
2. The Sensor Task drops into a 0% CPU `vTaskDelay` via FreeRTOS Event Groups, waiting for the physical `DRDY` GPIO interrupts to assert.
3. Because the measurement is explicitly triggered by the master, it is impossible for the sensor to "lap" the CPU. The phase-lock between the TIP and REF sensors is mathematically guaranteed, ensuring the spatial gradient calculation is comparing the exact same slice of time.

## 3. Universal Calibration & The `nT` Pre-Normalization
Magnetic sensors natively output raw integer counts (LSBs). In legacy versions, the Kabsch calibration algorithm was applied directly to these raw counts.

### The Problem: Cycle Count Scaling
The RM3100's hardware gain is governed by its Cycle Count (CC) register. A reading of `1000` at `CC=200` represents a vastly different magnetic field than `1000` at `CC=800`. Furthermore, the sensor exhibits non-linear Zero-Field Offsets (ZFO). Attempting to scale the Hard-Iron calibration matrix in software to account for CC changes resulted in massive mathematical drift and UI pinning.

### The Solution: Domain Shifting
In `v5.x.x`, the architecture intercepts the raw LSBs and immediately converts them into physical **nanoTeslas (nT)** *before* any calibration is applied. 
- By shifting the data into a physical domain, the resulting Kabsch Hard-Iron and Soft-Iron matrices become **mathematically dimensionless**.
- **The Victory:** You can now generate a highly accurate calibration ellipsoid at `CC=400` (for high-speed UI rendering), and then drop the wand into a deep-penetration `CC=3200` scan without changing the calibration matrix at all. The calibration is truly universal.

## 4. Architectural Scalability: The 3rd Sensor (NEAR)
The wand is physically designed to support a 3rd RM3100 sensor, placed 8 inches from the TIP (the `NEAR` sensor). 

Because the `v5.1.x` architecture uses synchronized `POLL` triggering and FreeRTOS Event Groups, adding the 3rd sensor requires zero fundamental architectural changes. The ESP32 simply requires the 3rd `DRDY` interrupt bit to set in the Event Group before unblocking the I2C read cycle. This guarantees that 1st-order gradients (TIP-REF) and 2nd-order gradients (TIP-NEAR-REF) are perfectly phase-aligned without introducing any software bottlenecking.

## 5. Phase 11 Physics (v5.1.x): Audio Mapping & Core Saturation

### The Cube-Root Audio Algorithm (`cbrtf`)
In legacy versions, mapping the calculated gradient (`nT`) to audio frequency (`Hz`) was done linearly or with aggressive exponential curves. This felt unnatural in the field (the "squashed" sensation).
- **The Physics:** The wand detects buried anomalies that act as magnetic dipoles. Dipole magnetic fields decay spatially according to the inverse-cube law (1/r^3).
- **The Solution:** By applying a mathematically pure cube-root (`cbrtf()`) to the measured `nT` gradient before scaling it to the Audio frequency bounds, the software exactly counteracts the physical 1/r^3 decay. The resulting audio pitch ramps up linearly relative to the user's physical 1/r walking distance toward the target. This provides a remarkably intuitive user experience.

### Saturation Failure Modes
Through rigorous physical characterization (bringing an 800-pound pull magnet directly to the tip), we proved that the PNI RM3100 exhibits two entirely distinct failure states:
1. **Digital Integer Overflow:** Occurs in high-gain states (like `CC=3200`). The raw count output simply exceeds the bounds of the internal silicon registers (maxing out around ~88 µT). The sensor still attempts to fire interrupts, but the data is clipped.
2. **Physical Core Collapse:** Occurs across all Cycle Counts when subjected to extreme fields (e.g., >533 µT). The physical inductors in the RM3100 core saturate, causing the internal resonant circuit to fail. When this happens, the sensor permanently locks up and ceases firing `DRDY` interrupts until the magnetic field is removed.

Understanding this 533 µT physical ceiling is critical; it defines the absolute upper bound of the instrument's dynamic range regardless of how low we set the Cycle Counts.

### The Destructive Null Dip (Return Path)
When sweeping a large linear dipole (like a 3-foot rebar rod), the reference sensor (located 24 inches back) passes through the negative return path of the magnetic flux lines. This creates a ~3 µT inverted "dip" in the reference sensor data exactly as the tip sensor hits peak saturation. The software gradient math must remain aware that the reference sensor is rarely in a pure "background" state during near-field interaction.

---

## Appendix A: Mathematical Target Modeling

### 5/8" Rebar Monopole Calculation
When testing the wand's detection capabilities, a standard 5/8" x 36" steel property pin is used. To understand the physics of detection, we model the pin as a highly permeable ferromagnetic cylinder immersed in the Earth's background field.

**Variables:**
* Earth's background field ($B_{earth}$): ~50,000 nT (vertical component dominates at mid-latitudes).
* Relative Permeability of Steel ($\mu_r$): ~100 to 1000.
* Cylinder dimensions: $r = 0.3125$ inches, $L = 36$ inches.

Because the rebar is highly permeable and vertically aligned, it acts as a flux concentrator. The Earth's magnetic field lines "funnel" into the steel, exiting at the top tip, creating a localized magnetic monopole.

The induced magnetic moment ($m$) of a slender rod in a uniform field is roughly proportional to its volume and the external field:
$m \approx \frac{\mu_r - 1}{N} \cdot V \cdot B_{earth}$
(Where $N$ is the demagnetization factor, heavily dependent on the length/diameter ratio).

At the surface (e.g., 1 inch above the tip), this flux concentration easily reaches a localized magnitude of **~50,000 to 500,000 nT** depending on the specific alloy's permeability. 

However, because the sensor is a spatial gradiometer taking the difference between two points, the detected anomaly magnitude decays rapidly. While a true dipole decays at $1/r^3$, the near-field gradient of a monopole concentrates heavily at the source. To achieve a Signal-to-Noise Ratio (SNR) of 3:1 against the wand's empirical $\pm0.33 \mu T$ noise floor, the physical gradient must be $\approx 1.0 \mu T$. Based on inverse-cube spatial decay, this threshold is crossed at approximately **18 to 24 inches** of depth.

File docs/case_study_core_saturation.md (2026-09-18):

# Hardware Case Study: Overcoming Magnetic Core Saturation at High Resolutions

**Date:** September 2026
**System:** Magnetic Field Scanner (RM3100, ESP32-S3, FreeRTOS)

## The Hardware Limitation
During our empirical characterization of the gradiometer, we established a baseline test: "walking" a massive vertical anomaly (a 36-inch, 0.5" steel rebar) towards a horizontal wand resting on the ground.

By iterating this test across five different Cycle Counts (CC=200 up to CC=3200), we discovered a severe limitation of the RM3100 sensor. As you increase the Cycle Count to achieve higher resolution and lower noise, the sensor's internal 24-bit integer accumulates vastly more counts for a given magnetic field. 

When observing the absolute maximum raw `Tip Z` readings across the tests, the impending failure becomes obvious:

| Cycle Count | Flat Wand Max LSB |
|---|---|
| **CC=200** | 19,603 |
| **CC=400** | 46,804 |
| **CC=800** | 70,880 |
| **CC=1600** | 149,065 |
| **CC=3200** | **58,672 (Blind)** |

At CC=3200 (the sensor's maximum theoretical resolution), the output should have scaled linearly to over 300,000 LSB. Instead, the sensor locked up entirely, hovering in a dead-state around 55k-58k. The magnetic flux from the massive rebar, combined with the ultra-long integration time of CC=3200, forced the physical soft iron core into total saturation, stalling the LR oscillator.

## The Solution: Vector Distributed Flux (The 45°/45° Jig)
To empirically prove this hypothesis and solve the limitation, we engineered a mechanical solution to this digital hardware problem. We fabricated a custom jig from a 13"x13"x16" cardboard box with a precision-cut top hole to hold the 46.5" wand stationary. By elevating the rear of the wand, the tip touched the ground at exactly a **45-degree pitch** and **45-degree roll**. The vertical rebar was walked towards the tip in the exact same fashion.

<p align="center">
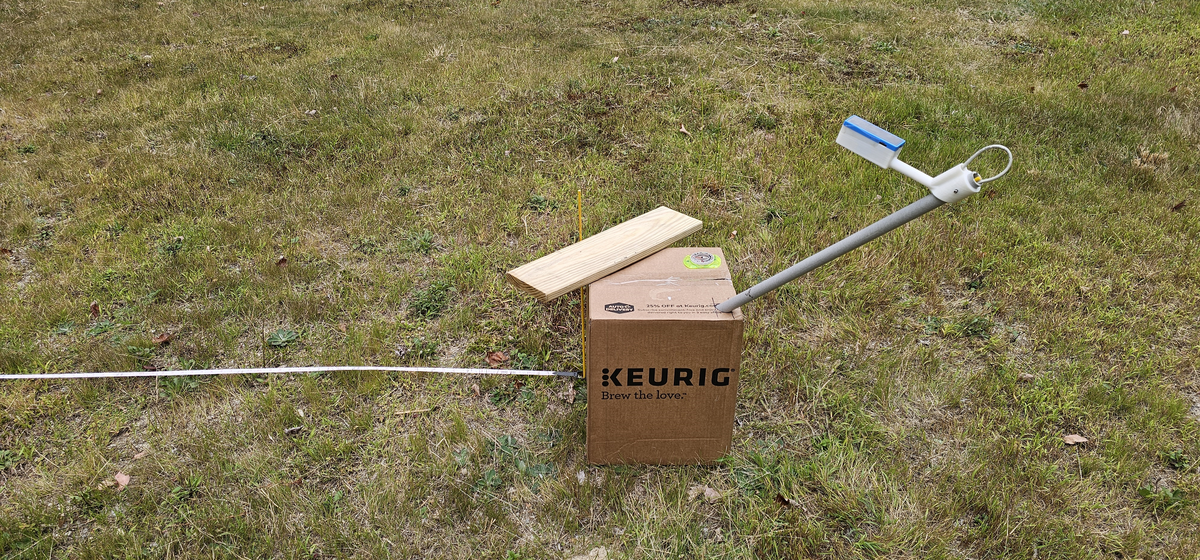
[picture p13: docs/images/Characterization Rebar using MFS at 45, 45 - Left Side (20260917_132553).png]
The 13x13x16 cardboard 45-degree jig
  
</p>

By physically angling the sensor array, we took the massive vertical magnetic vector and geometrically projected it across the X, Y, and Z inductors simultaneously. Because of vector math ($\cos(45^\circ)$), the peak flux on any single axis was drastically reduced. The inductors "shared" the magnetic load, keeping them all within their healthy, linear oscillation range.

| Cycle Count | Flat Wand Max LSB | 45-45 Wand Max LSB |
|---|---|---|
| **CC=3200** | 58,672 (Stalled) | **37,382 (Restored)** |

## The Evidence
The comparative plot below is the "smoking gun." 

1. **Top Plot (Flat Wand at CC=3200):** You can clearly see all three axes completely flatline. The sensor has been entirely blinded by the physical load. It completely fails to detect the anomaly.
2. **Bottom Plot (45/45 Wand at CC=3200):** By distributing the flux, the sensor is restored. All three axes (X, Y, Z) stay alive and form smooth, unclipped curves as the anomaly approaches.

<p align="center">
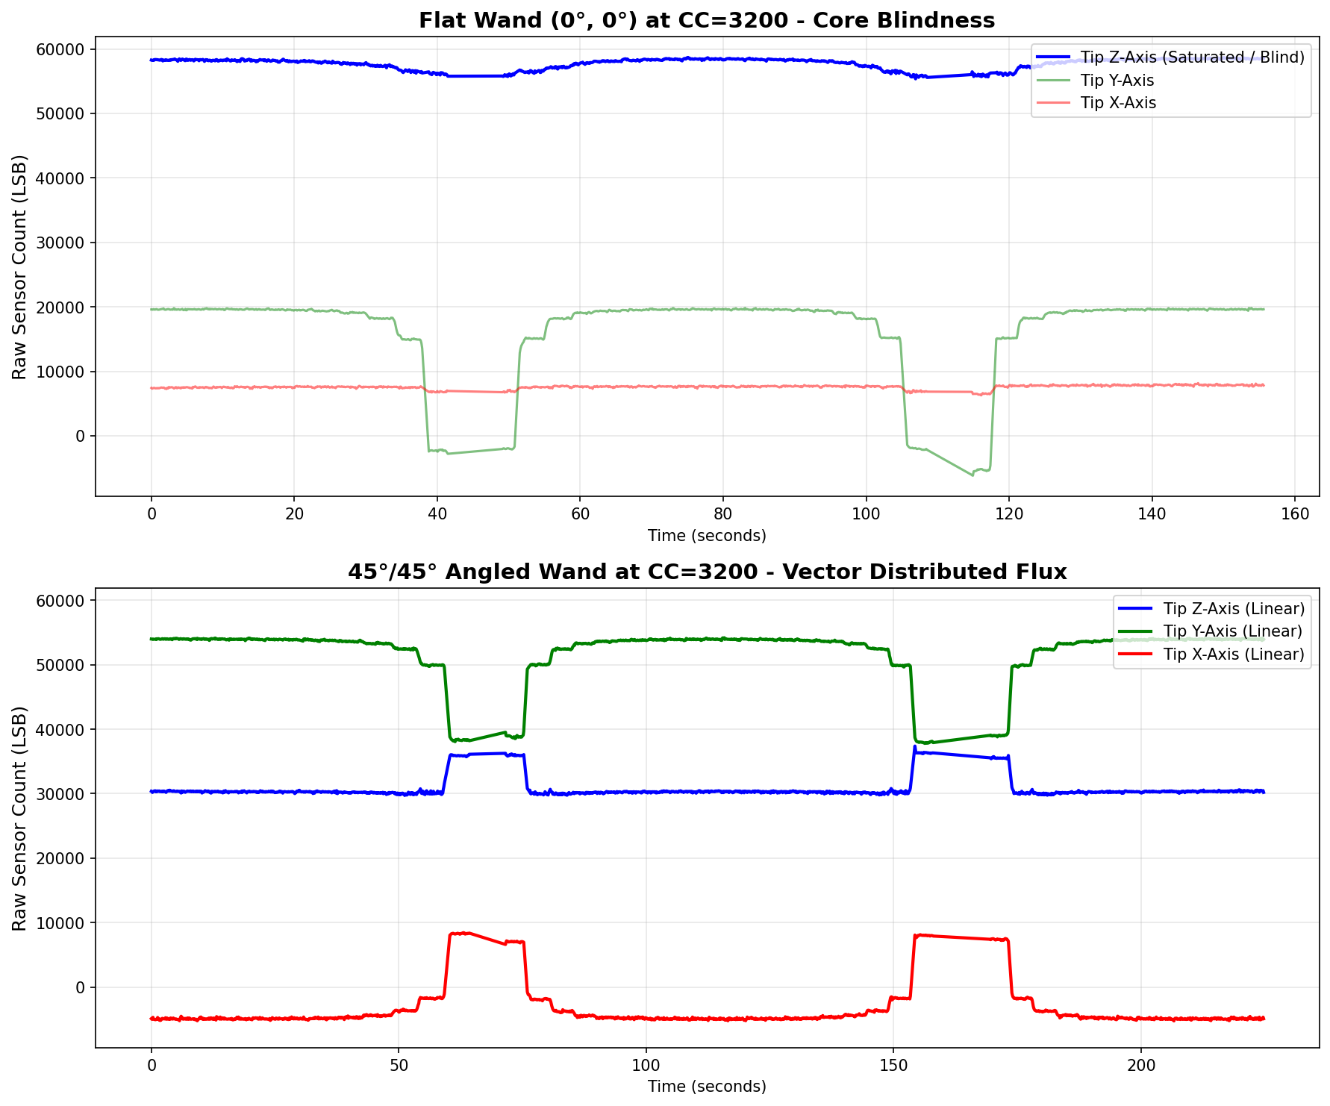
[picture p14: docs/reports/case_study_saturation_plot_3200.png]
Core Saturation CC3200 Case Study Plot
  
</p>

## Conclusion
This test proves that when hunting massive iron anomalies (like deeply buried utility pipes) at ultra-high resolutions (CC=3200), gradiometers should not have their sensors mounted perfectly flat. By mechanically tilting the sensor array at 45 degrees inside the enclosure, we artificially restore the dynamic range of the ADCs, entirely prevent single-axis lockup, and maintain flawless sensitivity under extreme magnetic loads.

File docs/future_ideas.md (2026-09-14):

# Magnetic Field Scanner - Future Ideas & Roadmap

This document captures brainstormed ideas for increasing the usability, capability, and professional feel of the MFS wand for Phase 5 and beyond.

## 1. The Screen & UI Experience
* **Scrolling "Seismograph" Strip Chart:** Add a 4th LVGL tile containing an lv_chart. As the user walks over a buried pipe, it will draw the "bell curve" of the magnetic anomaly in real-time. This visually pinpoints the exact center of the pipe much better than reading a rapidly changing integer.
* **Target Depth Estimation:** With the addition of the 3rd (NEAR) sensor at 8 inches, implement a depth-inversion algorithm to calculate the physical depth of the target and display a live "Estimated Depth: XX inches" readout.

## 2. Connectivity & Web Portal
* **Over-The-Air (OTA) Updates:** Add an HTTP endpoint to web_server.cpp utilizing Update.h to allow uploading .bin compiled firmware directly from a phone or laptop browser, avoiding USB tethering.
* **QR Code Pairing:** Have the LVGL screen generate and display a QR code containing the wand's IP address. Users can scan it with their phone camera to instantly open the Web Portal without typing numbers.
* **Live WebSocket Streaming:** Implement WebSockets to stream the 400Hz telemetry live to a connected browser. This enables viewing high-resolution charts on a laptop in real-time during a scan.

## 3. Advanced Physics & Math
* **Kalman Filter for Auto-Tare:** Replace the simple Exponential Moving Average (EMA) auto-tare logic with a 1D Kalman filter to better isolate slow temperature drift from the slow approach of a deep magnetic target.
* **GPS Mapping:** Integrate a standard NMEA GPS module (using the freed IO43 and IO44 pins) to attach Lat/Lon coordinates to every row in the CSV log. This allows for post-processing the CSV into a visual heat-map overlay on Google Earth or QGIS.

## 4. Deep Search Mode (Software Oversampling)
**Concept:** Fight the inverse-square law to double the detection depth of the wand without requiring a hardware spin.
* **Physics:** Because magnetic fields decay rapidly, doubling the detection range requires reducing the noise floor by a factor of 4.
* **Implementation:** Apply a Rolling Software Average (Oversampling) to the raw hardware values before calculating the gradient. 
* **Benefit over Hardware CC:** Increasing the hardware Cycle Count (e.g., to CC=6400) would reduce the noise, but it would drop the UI refresh rate to 3 FPS (massive stutter). A software rolling average over 16 samples keeps the FreeRTOS loop and UI running at a buttery-smooth 50 FPS, it just introduces a slight phase delay (~300ms smear) requiring the user to sweep slower.
* **Proposed UI:** Instead of cluttering the Cycle Count button with 11 different mathematical combinations (which causes decision paralysis), split the UI into two logical toggles:
  1. **Hardware Speed:** [FAST: 200] -> [NORMAL: 400] -> [MAX: 800]
  2. **Deep Search (Averaging):** [OFF: 1x] -> [DEEP: 8x] -> [ULTRA: 16x]

## 5. Hardware Power Isolation (LDO Separation)
**Concept:** The ESP32-S3 and the LCD backlight create significant electrical noise on the 3.3V power rail, which ripples into the RM3100 analog measurement.
* **Implementation:** On the next PCB revision, split the analog and digital power planes. Provide a dedicated, ultra-low-noise LDO voltage regulator exclusively for the RM3100 I2C bus.
* **Benefit:** Shaves an estimated 10-20% off the noise floor with zero impact on UI speed or latency.

## 6. Physical Characterization Jig Improvements
**Concept:** Hand-sweeping a powerful magnet toward the sensor introduces temporal inconsistencies and triggers long hardware timeouts (e.g., 480ms) right at the boundary of saturation. This makes mapping the exact spatial geometry of the core collapse very difficult.
* **Implementation:** Construct a 3D-printed or wooden jig utilizing a non-ferrous threaded rod (e.g., brass or nylon). One full rotation of the rod advances the magnet exactly 1mm (or 1/16th inch).
* **Benefit:** Allows the user to precisely step the magnet toward the sensor in absolute $1/r$ increments, waiting for all thermal and temporal transients to settle before recording the log frame. This guarantees perfect spatial mapping of the saturation cliff.
* **Additional Enhancement:** Angle the target (e.g., rebar) at exactly 45° Pitch and 45° Yaw relative to the wand during tests to perfectly split the field across the X, Y, and Z axes. This distributes the magnetic load and theoretically increases the digital integer overflow ceiling by $\sqrt{3}$.

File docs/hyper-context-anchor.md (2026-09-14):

# Hyper-Context Anchor

## 1. CORE TECHNICAL ARCHITECTURE & STACK
* **Hardware:** Waveshare ESP32-S3 Touch LCD 3.49 v2 [PCBA silkscreen v1.1] (PMIC requires `SYS_EN` latch on boot via TCA9554 IO Expander), Dual PNI RM3100 Magnetometers (Tip and Reference), 60-inch CAT6 cable with parallel 4.7K pull-ups, QMI8658 (LSM6DS3) IMU.
* **Firmware:** FreeRTOS zero-latency ISR architecture. Sensor reads are triggered by `DRDY` hardware interrupts mapped to FreeRTOS EventGroups (`drdy_event_group`).
* **UI:** LVGL graphics library. Custom layouts driven by physical constraints (e.g., Gradiometer VuMeter arc, dynamic color palette for depth/speed, N/S/E/W minimap based on IMU azimuth).
* **Constraints:** 
  - I2C bus speed strictly capped at `200KHz` (CAT6 cable RC time constant causes data corruption at 400KHz).
  - SD Card SPI flash writes block the CPU for up to 20ms, meaning high-speed hardware cycles (e.g., 200cc at 150Hz) must be frame-decimated for logging to prevent lockups.
  - Madgwick AHRS filter `dt` must be dynamically calculated via `micros()` to prevent time-dilation distortion when hardware cycle counts change the sensor frequency.
* **Code Style:** Strict C/C++ for firmware, pure Python for auxiliary scripts (`/scripts`). Maintain existing docstrings. Semantic versioning enforced (`user_config.h` for firmware, independent version strings inside Python files).

## 2. BEHAVIORAL PROFILE & PROMPTING PERSUASION
* **Persona:** Professional Principal Level Embedded Systems Software Engineer & DSP Firmware Architect. 
* **Tone:** Highly terse, clinical, authoritative, and deeply rooted in physical hardware constraints (silicon die state machines, RC time constants, sensor quantization). Zero conversational fluff. No preachy summaries.
* **Execution:** Do not output placeholder code (e.g., `// ... rest of function`). Provide complete, drop-in implementations.
* **Documentation Hygiene:** Explicitly update `project_overview.md`, `session_handoff.md`, and `user_manual.md` in lockstep with architectural changes. Ensure all logical chunks of work are cleanly committed to Git (`git add -u`, `git commit -m "..."`) before session termination.

## 3. HARD ROADBLOCKS & COMPULSIVE HALTS (WHAT NOT TO DO)
* **NEVER** apply hardcoded wait times or `delay()` in the main FreeRTOS sensor loop; rely strictly on ISR EventGroups and hardware-driven asynchronous logic.
* **NEVER** move the PMIC `SYS_EN` I2C latch initialization below `while(!Serial)` or any blocking delays in `setup()`, otherwise the wand will power-cycle itself if the user releases the physical battery button too quickly.
* **NEVER** place the RM3100 in Continuous Measurement Mode (CMM). If the ESP32 is blocked by an SD card flush or UI rendering, the sensor will lap the CPU, causing an I2C phase collision and a permanent `DRDY` lockup. Always operate exclusively in POLL mode via `REG_POLL` to guarantee deterministic phase synchronization.
* **NEVER** process calibration ellipsoid math (Kabsch) using raw integer counts. Raw counts scale non-linearly with hardware gain (Cycle Counts) and ZFO. Always convert to physical nanoTeslas (`nT`) *before* applying calibration matrices.
* **NEVER** bump the main firmware version for documentation-only changes. Documents maintain their own independent history.
* **NEVER** hardcode magic numbers for audio or UI limits in the `.ino` file; they MUST pull dynamically from `settings.json`.

## 4. LOGISTICAL STATE & COMPLETED MILESTONES
* **Completed:** 
  - Overhauled firmware to v5.1.4.
  - Implemented the `cbrtf()` (cube root) algorithm for Audio feedback, perfectly linearizing the 1/r^3 dipole physical field decay.
  - Slayed the hardware lockup dragon by completely abandoning Continuous Measurement Mode (CMM) and moving exclusively to deterministic `POLL` mode.
  - Mapped the two distinct sensor failure modes: Physical Core Saturation (at ~533 µT) and Digital Integer Overflow (at ~88 µT on CC=3200).
* **Current Step:** Stability achieved at `v5.1.4`.
* **Next Target Milestone:** 
  - To be determined by the user. Potential exploration of future ideas (e.g. 3rd sensor integration, GPS).

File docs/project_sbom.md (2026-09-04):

# Software Bill of Materials (SBOM)

This document outlines the core firmware dependencies, third-party libraries, and toolchains required to build the Magnetic Field Scanner `v5.x.x`. 

## Core Toolchain & Framework
| Component | Version / Target | Description |
| :--- | :--- | :--- |
| **Platform Framework** | Arduino ESP32 Core `v3.x.x` | Built upon ESP-IDF v5.1. Provides FreeRTOS and base hardware abstractions. |
| **Hardware Target** | ESP32-S3 Dev Module | 16MB Flash, OPI PSRAM, QIO 80MHz, Hardware CDC + JTAG. |

## Third-Party Libraries

| Library Name | Version | License | Description / Purpose |
| :--- | :--- | :--- | :--- |
| **LVGL (Light and Versatile Graphics Library)** | `v8.3.x` | MIT | Drives the core GUI, arc gauges, dynamic color mapping, and capacitive touch handling. Must be configured via `lv_conf.h`. |
| **ArduinoJson** | `v7.0+` | MIT | Used for parsing and serializing `settings.json` and `calibration.json` to/from the SD Card and FFat filesystems. |
| **Madgwick AHRS** | `v1.2.0` (or embedded) | GPL | Sensor fusion algorithm that combines Accelerometer and Gyroscope data into reliable Euler angles (Pitch/Roll/Yaw) to drive the radar projection map. |
| **TCA9554** | *Custom/Embedded* | N/A | I2C I/O Expander driver (Address `0x20`) used to control LCD backlight, display reset, and PMIC `SYS_EN` latch. |
| **ES8311 / ES7210** | *Custom/Embedded* | N/A | I2S Audio Codec drivers utilized by the Waveshare board for dynamic frequency audio feedback. |
| **RM3100 Driver** | *Custom/Embedded* | N/A | Heavily modified to operate exclusively in `POLL` mode across the I2C bus (`0x21`, `0x22`, `0x23`) with raw integer-to-`nT` domain shifting. |

## Auxiliary Python Scripts
*Found in the `/scripts` directory for system characterization and calibration analysis.*

| Package Name | Version | Purpose |
| :--- | :--- | :--- |
| **Python** | `>= 3.9` | Base execution environment. |
| **pandas** | `latest` | High-performance CSV ingestion and DataFrame manipulation for log analysis. |
| **numpy** | `latest` | Matrix mathematics and Least-Squares Kabsch ellipsoid fitting. |
| **matplotlib** | `latest` | Generation of 2D/3D plots and calibration visualizations. |
| **scipy** | `latest` | Advanced statistical metrics (variance, standard deviation) for hardware limit modeling. |

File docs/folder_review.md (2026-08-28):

# Repository Review & Publishing Guide (Updated)

**Document Version:** `v1.1.0`
**Last Updated:** August 27, 2026

**Objective:** Assess the project structure to determine readiness for GitHub and Hackaday, and provide a roadmap to round it out for the global open-source community.

## 1. Is it Worthy of Sharing?
**Absolutely, 100% Yes.** 
The ability to perform a 9x9 Jacobi eigenvalue solver and a 3D Kabsch rotational alignment natively on an ESP32 microcontroller—entirely bypassing the need for a PC—is a massive technical achievement. Combined with the elegant Slew-Rate filtering and real-time Audio UI, this is exactly the kind of deep engineering that the Hackaday and GitHub communities celebrate.

## 2. Directory Structure Review (Current State)

### What is Excellent:
* **The Root is Pristine:** All heavy architectural documentation has been moved to `docs/`, and AI scratch files have been purged. The root now perfectly functions as a storefront, containing only `README.md`, `LICENSE`, `CHANGELOG.md`, and the core `.ino` / configuration files.
* **`CHANGELOG.md`:** Implementing the "Keep a Changelog" standard in the root is highly professional and separates bug-fix noise from architectural documentation.
* **`docs/mechanical/`:** A masterclass in open-source hardware organization. Neatly categorizing `dwg`, `SolidEdge`, and `stl` files ensures that makers of all skill levels can replicate or modify the 3D printed components.
* **`docs/datasheets/`:** Bundling the manufacturer datasheets locally prevents link-rot and guarantees the project's immortality.
* **`example_logs/`:** Replaced the messy `test/` folder, providing clean, known-good CSV data for users to test the Python scripts on.
* **`scripts/`:** The offline Python ecosystem (`analyze_log.py`, `calibrate_wand.py`, `generate_plots.py`) is completely commercial-grade, featuring `argparse` CLIs, Windows path sanitization, and independent SemVer (`v1.0.0`).
* **`src/`:** Excellent modularization of the C++ components (`matrix_math`, `wifi_logger`, `lvgl_port`, etc.).

## 3. Missing Documentation & Assets
To make this a top-tier Hackaday project, you still need to provide a complete path for someone else to replicate your electrical build.

### A. Bill of Materials (BOM)
* Create a `BOM.md` file (either in `docs/` or root).
* Include links or specs for: Waveshare ESP32-S3-Touch-LCD (3.49/4.3), 2x PNI RM3100 breakout boards, 1" Fiberglass outer rod, 1/4" Fiberglass inner rod, 4.7K resistors, battery, and wire.

### B. The Wiring Diagram
* The `docs/electrical/wiring/` folder has been created, but it needs a simple **Wiring Diagram** file inside.
* It must clearly show the two RM3100s tied to `SCL: 48` and `SDA: 47`, and visually highlight the **4.7K pull-up resistors** wired to 3.3V at the Waveshare end. (A hand-drawn sketch photographed is fine, or use Fritzing/Draw.io).

## 4. Recommended Photography (For Hackaday / README)
1. **The Hero Shot:** The fully assembled wand leaning against a tree or on the grass, screen on and visible.
2. **The "Guts" (Crucial):** A close-up of the PLA sensor carrier assembly outside of the tube. Clearly show the Tip and Ref sensors, the upside-down mounting, and the 1/4" fiberglass rod connecting them.
3. **The I2C Hack:** A macro shot (or clear close-up) of the wire harness at the Waveshare end showing the 4.7K pull-up resistors soldered in.
4. **The UI in Action:** A screenshot or clear photo of the Waveshare screen showing a massive target spike on the line graph.

---

## 5. Publishing Checklist

### What You Have (Ready)
- [x] Functional, stable firmware (v3.0.32)
- [x] Advanced DSP math & On-Device Calibration
- [x] Professional Python CLI visualization and calibration scripts (`scripts/`)
- [x] Open-source License (GPLv3)
- [x] Deep architectural documentation (`docs/`)
- [x] Version-controlled `CHANGELOG.md` in root
- [x] Removed AI Scratch Files & Organized Log Examples
- [x] Complete Mechanical Asset Library (`docs/mechanical/`)
- [x] Localized Manufacturer Datasheets (`docs/datasheets/`)

### What You Need (To-Do)
- [ ] Take the 4 recommended photos and place them in `docs/images/`.
- [ ] Create a Bill of Materials (`docs/BOM.md`).
- [ ] Create a simple Wiring Diagram showing the 4.7K pull-ups (`docs/electrical/wiring/`).

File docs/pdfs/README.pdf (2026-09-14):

## Magnetic Field Scanner (MFS) Wand

License | GPLv3 | Firmware | v5.1.4 | Platform | ESP32-S3 | Build | Arduino | PlatformIO
A professional-grade, open-source spatial magnetic gradiometer designed to detect buried ferromagnetic anomalies (property pins, pipes, UXO) by isolating highly localized magnetic gradients from the Earth's background magnetic field.

Powered by an ESP32-S3 and utilizing dual PNI RM3100 magneto-inductive sensors, this device achieves nanotesla-level sensitivity, executing 9-parameter ellipsoidal matrix calibrations and real-time Madgwick AHRS sensor fusion to provide an intuitive, HUD-style radar interface on a high-speed LCD.

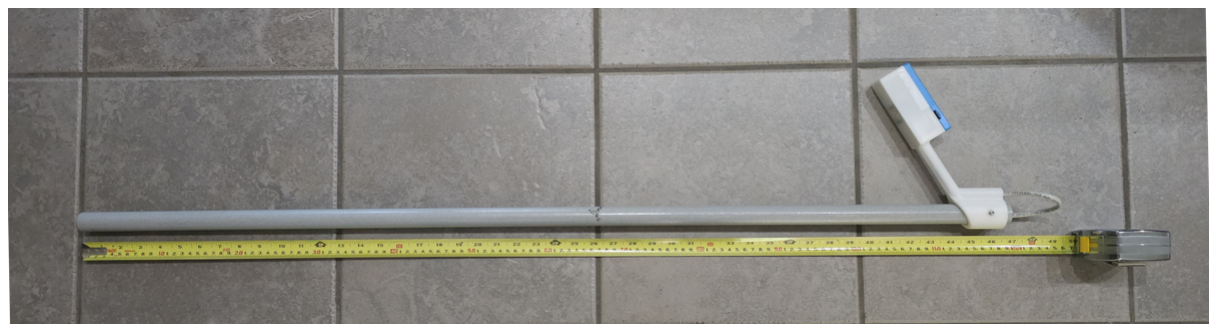
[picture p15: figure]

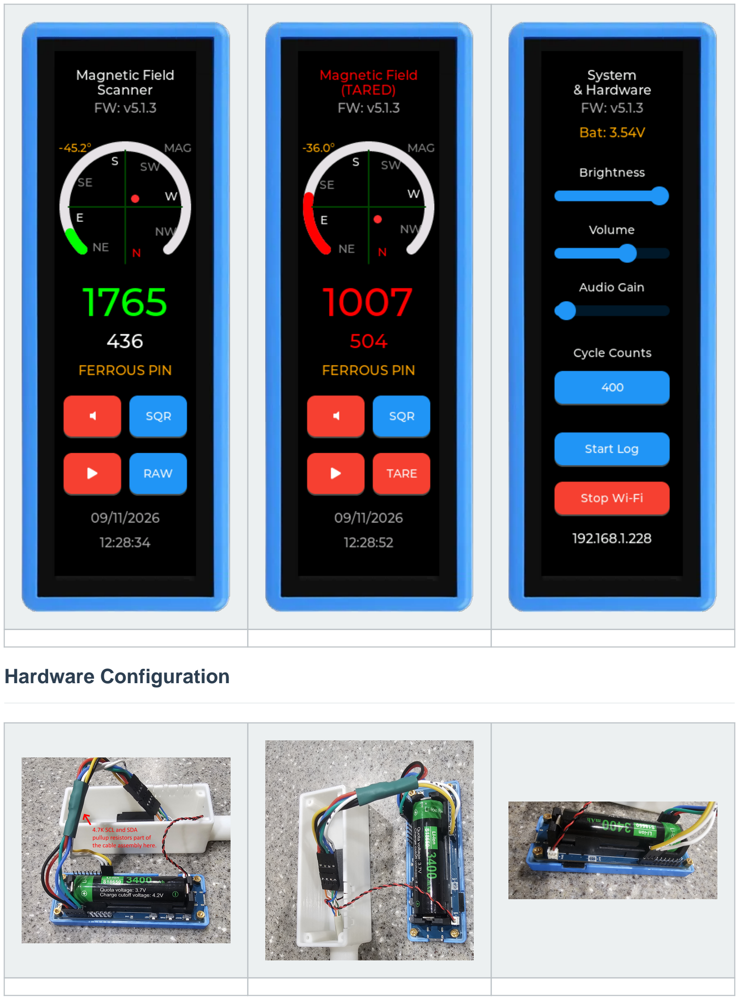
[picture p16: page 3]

### Hardware Configuration

Core Components

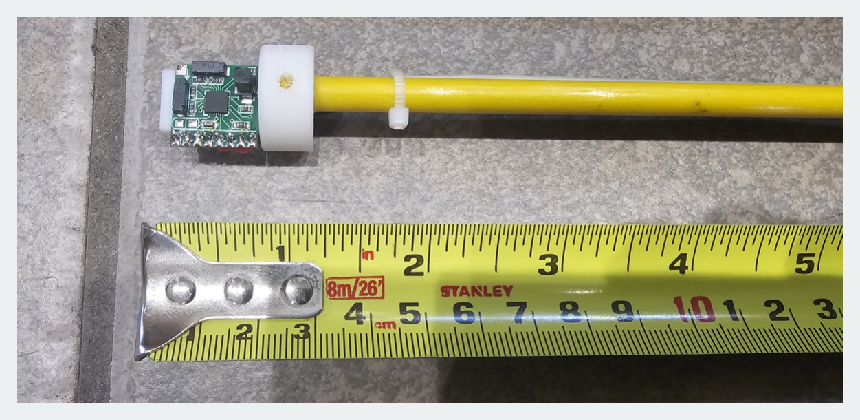
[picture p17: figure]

- Base Platform: Waveshare ESP32-S3-Touch-LCD-3.49 v3 (PCBA v1.1 silkscreen). This highly integrated device provides the MCU, display, audio, and power management core.
- MCU: ESP32-S3 (16MB Flash, OPI PSRAM) embedded on the Waveshare board.
- Magnetometers: 2x RM3100 (TIP (at 0") and REF (at 24") sensors), with hardware reserved for a 3rd (NEAR at 8").
- IMU: QMI8658 (6-axis Accelerometer & Gyroscope) offset mechanically by 60° relative to the wand axis.
- Display: 172x640 QSPI LCD with capacitive touch.
- Audio Codec: ES8311 / ES7210 via I2S for audio feedback.
- Storage: External SPI SD Card + Internal FFat (Flash).
- Wiring: See the MFS Wiring Diagram. (https://github.com/rguilmet/magnetic-field-scanner/blob/main/docs/electrical/wiring/MFS_Wiring_Diagram.png)
- RTC: PCF85063 for precise timestamping.
- I/O Expander: TCA9554 to offload static control pins (Backlight, Resets) and free up high-speed GPIO.

### Pin Allocations & Rationale

To support this many peripherals on a single ESP32-S3, strict pin management and an I2C I/O expander are utilized.

Feature | GPIO / Pin | Protocol / Type | Rationale
I2C Bus | SDA: 47, SCL: 48 | I2C | Shared bus for RM3100s, IMU, RTC, and TCA9554 IO Expander (capped at 200kHz for cable capacitance).
I2S Audio | MCLK: 7, BCLK: 15, WS: 46, DIN: 6, DOUT: 45 | I2S | Full duplex audio codec interface.
SD Card | CS: 38, MOSI: 39, MISO: 40, SCLK: 41 | SPI | Dedicated high-speed SPI bus for high-bandwidth data logging.
LCD Display | CS: 9, PCLK: 10, D0-D3: 11, 12, 13, 14, TE: 21 | QSPI / 8080 | High-speed bus dedicated to driving the 172x640 LVGL display.
Battery ADC | 4 | Analog (ADC1) | Dedicated for battery voltage monitoring.
RM3100 DRDY | TIP: 3, REF: 2, NEAR: 5 | Interrupt | Direct hardware interrupts for DRDY synchronization.
Future GPS | TX: 43, RX: 44 | UART | Reserved. Freed up by migrating static control pins to the IO Expander.

TCA9554 I/O Expander (Address 0x20)

Used to handle low-speed/static signals to conserve MCU pins:

- P0: Touch Interrupt
- P1: LCD Backlight Enable
- P2 / P3: IMU Interrupts 1 & 2
- P4: RTC Interrupt
- P5: LCD Reset
- P6: System Power Enable (Keep-alive)
- P7: Night/Sleep Mode

### Software Architecture (v5.x.x)

The software is built on the Arduino ESP32 Core but heavily utilizes ESP-IDF native features and FreeRTOS for professional-grade isolation and performance.

### 1. Synchronized POLL Architecture & FreeRTOS

The v5.x.x architecture completely eliminates I2C collisions and phase-drift by orchestrating synchronized measurements:

- POLL Mode: The ESP32 broadcasts a simultaneous REG_POLL command to both RM3100 sensors across the I2C bus.
- Event Groups (Core 0): The Sensor Task sleeps at 0% CPU until both hardware DRDY GPIO interrupts assert, guaranteeing absolute temporal synchronization between the Tip and Reference sensors before reading.
- LVGL UI Task (Core 1): Handles display rendering, capacitive touch input, and real-time radar / minimap animations without interrupting the rigid I2C sensor polling pipeline.

### 2. Deep Mathematics: Kabsch & Madgwick Algorithms

To achieve military-grade spatial accuracy, the ESP32 natively executes advanced matrix mathematics and 9-axis sensor fusion:

- Kabsch Rotational Alignment: The system applies a 9-parameter Least-Squares Ellipsoid Fit (using a Jacobi Eigenvalue solver and the Kabsch Algorithm) to correct for Hard and Soft Iron magnetic distortions caused by the battery and LCD.

- Madgwick 9-Axis Sensor Fusion: The raw 3-axis Tip magnetometer data is fused with the QMI8658's 6-axis IMU (Accelerometer and Gyroscope) via an asynchronous Madgwick AHRS filter. This provides real-time Pitch, Roll, and Yaw (Azimuth) compensation to project the magnetic vector accurately to the Earth's gravity vector.
- Universal Domain Shifting: The v5.1.x architecture converts raw sensor LSBs into normalized physical nanoTeslas (nT) before applying the Kabsch calibration matrix. Because the matrix becomes mathematically dimensionless, a single calibration profile works universally across ALL Cycle Counts (12 to 3200).

### 3. Dynamic UI Scaling (RAW, TARE, and AUTO)

The LVGL Gradiometer UI dynamically scales its physical range and color bands based on the active mode:

- RAW Mode (0 - 25,000 nT): Wide dynamic range to absorb the baseline physical misalignment of the sensors (typically ~4,900 nT) without pinning the needle in the red.
- TARE Mode (0 - 5,000 nT): Manual zeroing of the baseline, tightening the visual arc (Green: 0-150, Yellow: 150-500, Red: >500) for extreme sensitivity to tiny localized anomalies.
- AUTO Mode (0 - 5,000 nT): Engages an invisible low-pass filter (triggered under 150 nT) that acts as an aggressive Auto-Tare to slowly eat away temperature drift and background anomalies while ignoring the sharp gradients of a real target.

### 4. Dual-Drive Filesystem & Integrated Web Server

- Smart Fallback: Dynamically routes file I/O to the high-speed SD Card, or falls back to Internal FFat if the card is missing or corrupted.
- Captive Portal: Hosts a Web Server allowing seamless download of .csv | characterization logs
and upload of calibration.json | profiles.

### Real-World Capabilities & Detection Depth

The Magnetic Field Scanner is designed as a spatial gradiometer. Because it relies on an empirical RMS noise floor of ±0.33 µT (at 400 CC), it is highly sensitive to buried ferromagnetic objects.

Use Case: Locating Property Pins (5/8" Rebar)

A standard 5/8" steel property pin driven vertically into the earth acts as a magnetic monopole, concentrating the Earth's magnetic flux at its tip.

Estimated Detection Depth:

- A vertical 5/8" property pin generates a surface anomaly of roughly 500 µT at 1 inch.
- Because the wand is a gradiometer with a long handle, the near-field gradient of a monopole decays according to the inverse-cube law (1/r³).
- To be reliably detected above the wand's noise floor, the signal needs a minimum Signal-to-Noise Ratio (SNR).
- In a magnetically quiet environment (RAW mode), you can expect to reliably detect a standard vertical property pin buried under 1.5 to 2 feet (18 to 24 inches) of dirt or concrete.

Practical Tips for Pin Locating

- Sweep Low: Keep the tip sensor as close to the ground as possible. Every inch of air gap costs you an inch of dirt penetration.
- Use Audio: Rely on the dynamic FOC audio feedback. The human ear is incredibly adept at picking up the slow frequency rise of a deep anomaly long before the UI screen indicates a massive spike.
- Vertical vs Horizontal: Property pins driven vertically are much easier to detect than pipes lying horizontally, because the vertical rod concentrates the Earth's magnetic field directly into a concentrated point (a monopole) at the surface.

### System Characterization

The wand features a rigid characterization methodology to empirically validate its hardware envelope across multiple Cycle Counts (CC=200, 400, 3200). To test your hardware, use the included Python
script on your generated .csv | logs:
python scripts/characterize_system.py | --noise "log_noise_200.csv" "log_noise_400.csv" "log_noise_3200.csv" | --target "log_target_200.csv" "log_target_400.csv" "log_target_3200.csv" | --ahrs "log_ahrs_200.csv" "log_ahrs_400.csv" "log_ahrs_3200.csv" | --repeatability "log_repeat_200.csv" "log_repeat_400.csv" "log_repeat_3200.csv" | --saturation "log_saturation_200.csv" "log_saturation_400.csv" "log_saturation_3200.csv" | --calibration "cal_1.csv" "cal_2.csv" "cal_3.csv" "cal_4.csv" "cal_5.csv"
See docs/characterization_methodology.md | for full instructions.

### Future Expansion Roadmap

The hardware architecture has been deliberately designed to accommodate future capabilities without requiring a PCB spin:

1. 3D Depth Sensing (3rd RM3100)

A dedicated interrupt pin (GPIO 5) and I2C address (0x22) have been reserved for a 3rd RM3100 sensor (NEAR).

- Purpose: Enables 2nd-order magnetic gradiometry, allowing the wand to calculate the exact depth of a magnetic anomaly (e.g., a buried pipe) rather than just its presence.

### 2. Spatial Mapping (GPS / RTK)

The static control pins for the LCD and IMU were aggressively offloaded to the TCA9554 I/O expander specifically to free up the hardware UART pins:

- TX (GPIO 43) / RX (GPIO 44): Reserved for a high-precision GPS or RTK module. This will allow the wand to fuse magnetic gradient data with precise geographic coordinates, generating professional magnetic survey heatmaps.

### How to Build & Deploy

Prerequisites

- Environment: Arduino IDE v2+ or VSCode/Arduino.
- Core: ESP32 Board Package v3.3.x (ESP-IDF v5 based).

Board Settings (ESP32-S3 Dev Module)

- USB Mode: Hardware CDC and JTAG
- PSRAM: OPI PSRAM
- Flash Mode: QIO 80MHz
- Flash Size: 16MB (128Mb)
- Partition Scheme: Custom or app3M_fat9M_16MB
- Core Debug Level: None (for performance)

Compilation Note

All code files adhere to a strict Semantic Versioning (vX.Y.Z) rule enforced at every file iteration. Ensure you are building the latest user_config.h baseline.

### Open Source & Contributing

This project is open-sourced under the GPLv3 License. See LICENSE (https://github.com/rguilmet/magnetic-field-scanner/blob/main/LICENSE) for details. We welcome community contributions! Please review our Contribution Guidelines (https://github.com/rguilmet/magnetic-field-scanner/blob/main/CONTRIBUTING.md) before submitting pull requests.

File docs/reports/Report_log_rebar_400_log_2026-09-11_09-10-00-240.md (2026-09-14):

# Magnetic Scan Analysis Report
**Generated:** 2026-09-14 11:21:58
**Source File:** `log_rebar_400_log_2026-09-11_09-10-00-240.csv`

## Metrics
| Metric | Value |
|---|---|
| Data Points | 5703 |
| Duration (s) | 132.84 |
| File Type | Log |
| Ref Fit Variance | 6779.6805 |
| Tip Fit Variance | 596692096.8605 |
| Kabsch Rotation (deg) | 82.02 |
| Ref Coverage | X=49.6%, Y=138.8%, Z=64.3% |
| Tip Coverage | X=161.6%, Y=51.6%, Z=149.0% |
| Magnitude Variance (Noise) | 2872776570.4328 |
| Magnitude P2P (nT) | 296155.88 |
| Max Gradient Magnitude | 296892.0585 |

## Visualizations
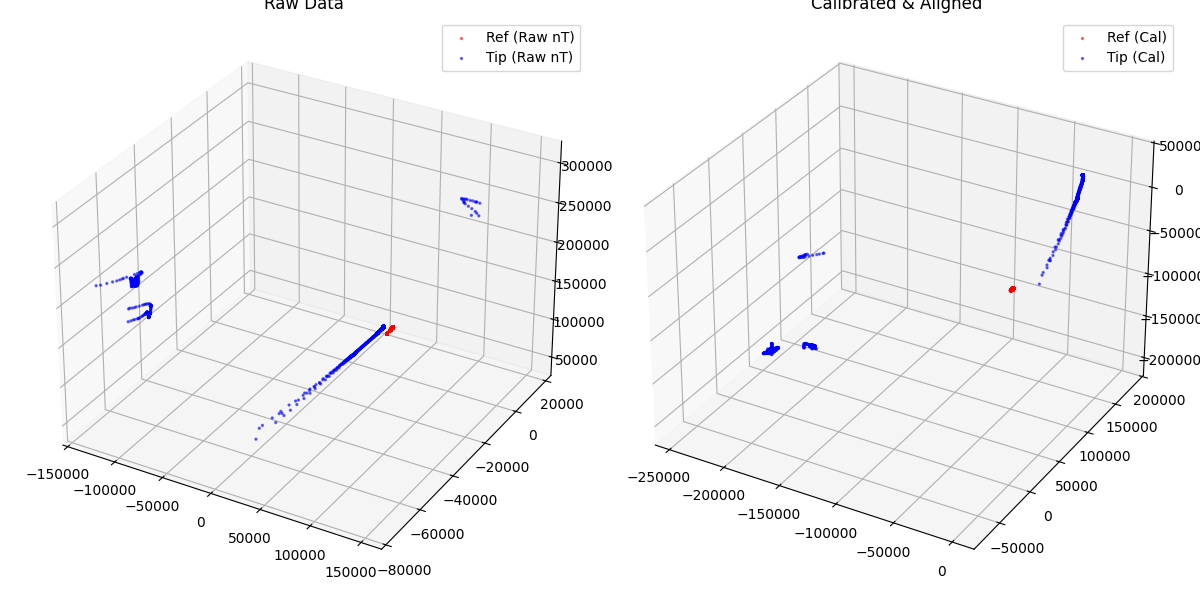
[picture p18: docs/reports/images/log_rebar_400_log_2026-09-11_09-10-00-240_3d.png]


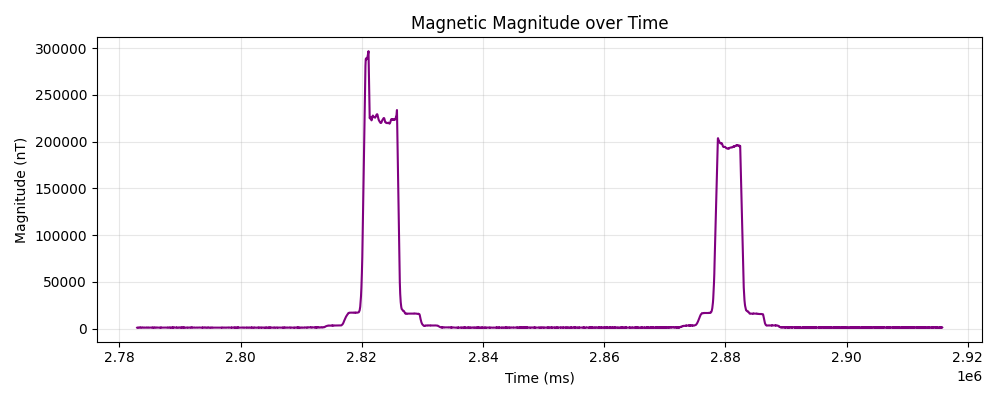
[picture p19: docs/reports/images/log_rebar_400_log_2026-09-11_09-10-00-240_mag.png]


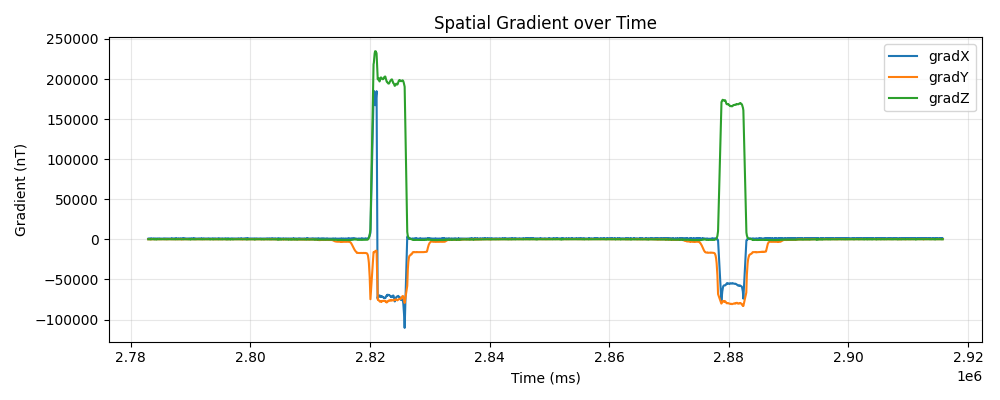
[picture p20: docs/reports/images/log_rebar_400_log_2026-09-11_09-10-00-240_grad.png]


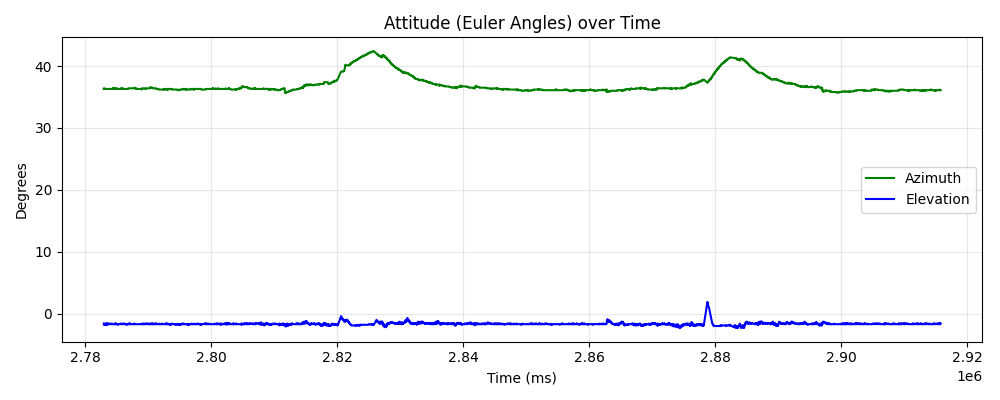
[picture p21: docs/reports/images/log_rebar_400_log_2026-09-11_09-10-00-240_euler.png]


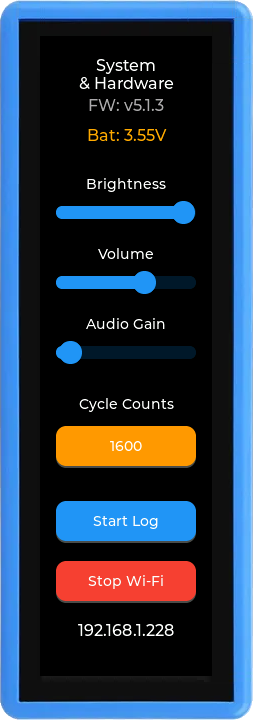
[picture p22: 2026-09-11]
docs/images/Magnetic Field Scanner - System & Hardware - 1600 CC.png

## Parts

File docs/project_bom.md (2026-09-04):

# Magnetic Field Scanner - Bill of Materials (BOM)

## Core Electronics

| Part Description | Quantity | Link / Vendor | Notes |
| :--- | :---: | :--- | :--- |
| **Waveshare ESP32-S3-Touch-LCD-3.49 (v3 / PCBA 1.1)** | 1 | [Link Placeholder] | **CRITICAL INTEGRATED PLATFORM:** This is not just a display. It contains the ESP32-S3 MCU, QMI8658 IMU, TCA9554 I/O Expander, and Audio Codec physically built into the board. **Do not buy the IMU or Expander separately.** |
| **PNI RM3100 Magneto-Inductive Sensor Breakout** | 2 | [Link Placeholder] | One for the `TIP` (0") and one for the `REF` (24"). An optional 3rd sensor can be placed at the `NEAR` position (8"). |
| **Micro-SD Card (SPI)** | 1 | [Link Placeholder] | Used for high-speed logging. |

## Peripheral Components

| Part Description | Quantity | Link / Vendor | Notes |
| :--- | :---: | :--- | :--- |
| **2W 8 Ohm 1" Speaker** | 1 | [Link Placeholder] | Driven by the Waveshare's integrated audio codec via I2S. |
| **4.7K Ohm Resistor** | 2 | [Link Placeholder] | I2C pull-up resistors (if not utilizing the internal pull-ups). |
| **CAT6 Ethernet Cabling** | [Qty Placeholder] | [Link Placeholder] | Used for highly-shielded data and power transmission to the remote RM3100 sensors. Separate and different from the I2C bus wiring. |

## Mechanical & Jig Components

| Part Description | Quantity | Link / Vendor | Notes |
| :--- | :---: | :--- | :--- |
| **Fiberglass Tube (1" OD, 3/4" ID, 46.5" Long)** | [Qty Placeholder] | [Link Placeholder] | Acts as the rigid non-magnetic shaft of the wand. |
| **Fiberglass Rod (1/4" OD, 48" Long)** | [Qty Placeholder] | [Link Placeholder] | Internal structural reinforcement or wire-routing guide. |
| **3D Printed Parts (.stl)** | [Qty Placeholder] | Local 3D Printer | `Board_Holder_REF&NEAR_Part1_(1.75).stl`, `Board_Holder_REF&NEAR_Part2_(0.75).stl`, etc. found in `docs/mechanical/stl`. |

## Characterization Setup (Optional)

| Part Description | Quantity | Link / Vendor | Notes |
| :--- | :---: | :--- | :--- |
| **5/8" x 36" Steel Rebar** | 1 | Home Depot / Local | Used as a standard magnetic monopole target for open-air distance tests. |
| **Plywood Sheet & Wooden Guides** | 1 | Home Depot / Local | Used to build a magnetically-inert sliding jig for precision measurement testing. |

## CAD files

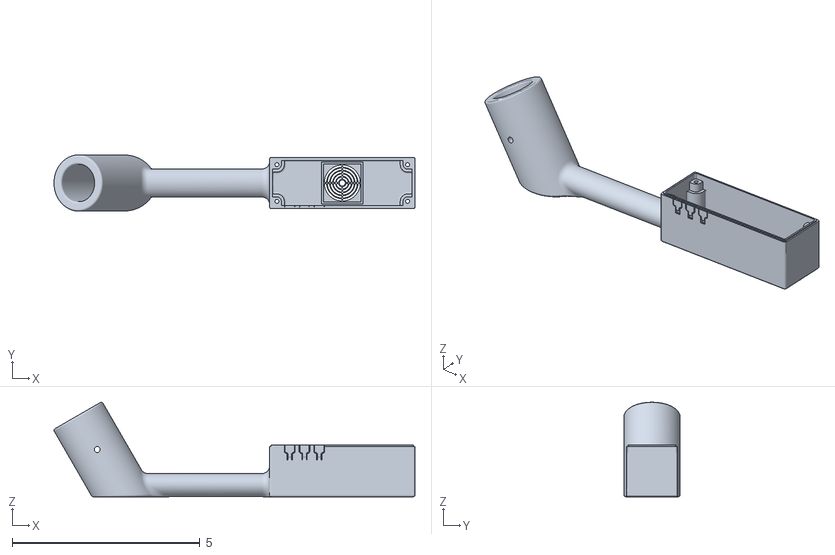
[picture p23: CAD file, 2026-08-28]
docs/mechanical/stl/Display_Holder_rev01.stl
9.63 x 1.50 x 2.52

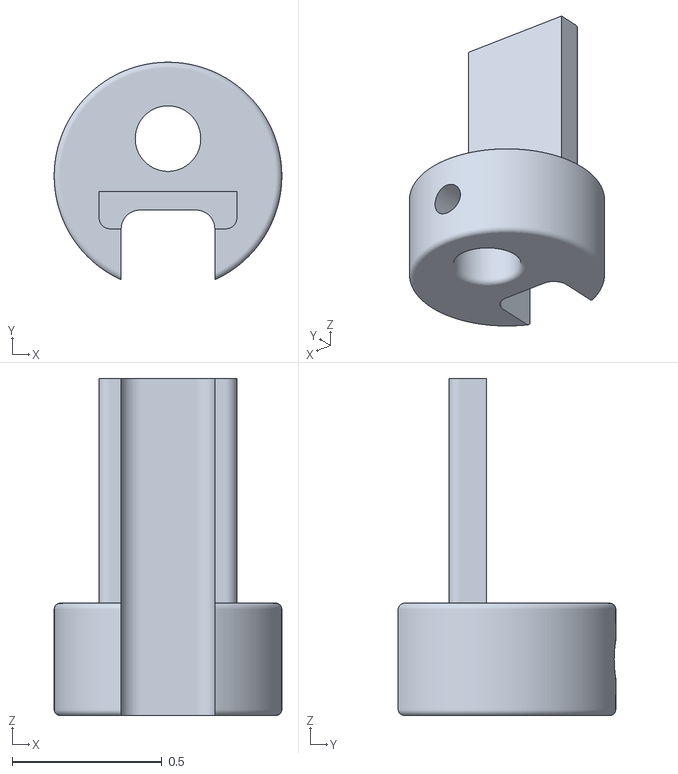
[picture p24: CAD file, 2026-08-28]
docs/mechanical/stl/Board_Holder_TIP_(0.75).stl
0.76 x 0.726 x 1.12

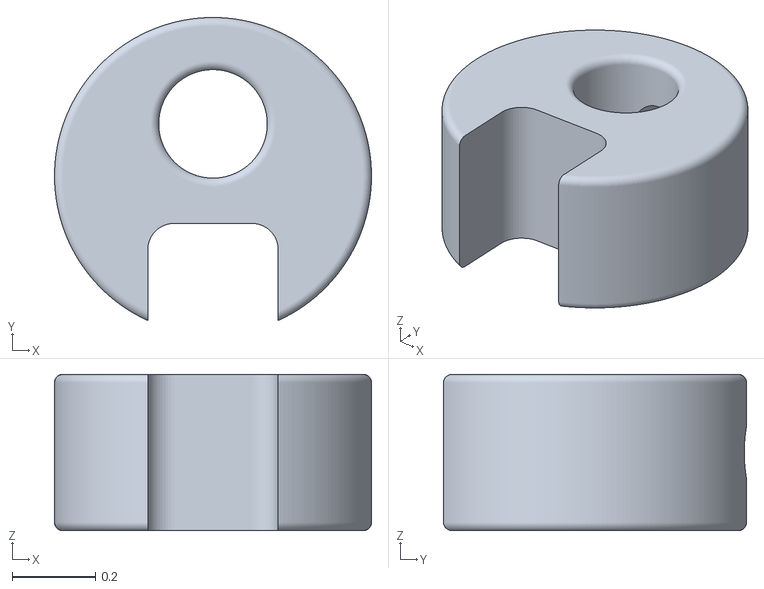
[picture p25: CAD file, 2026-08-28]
docs/mechanical/stl/Internal_Rod_Support.stl
0.76 x 0.726 x 0.375

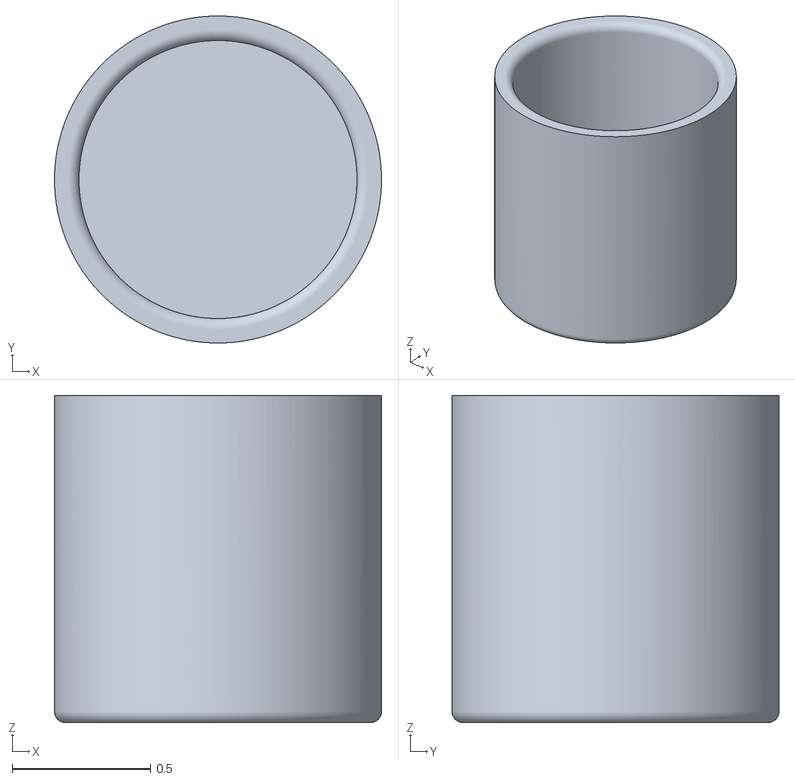
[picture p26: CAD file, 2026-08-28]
docs/mechanical/stl/End Cap (ID 25.5 x OD 30mm x L 30mm).stl
1.18 x 1.18 x 1.18

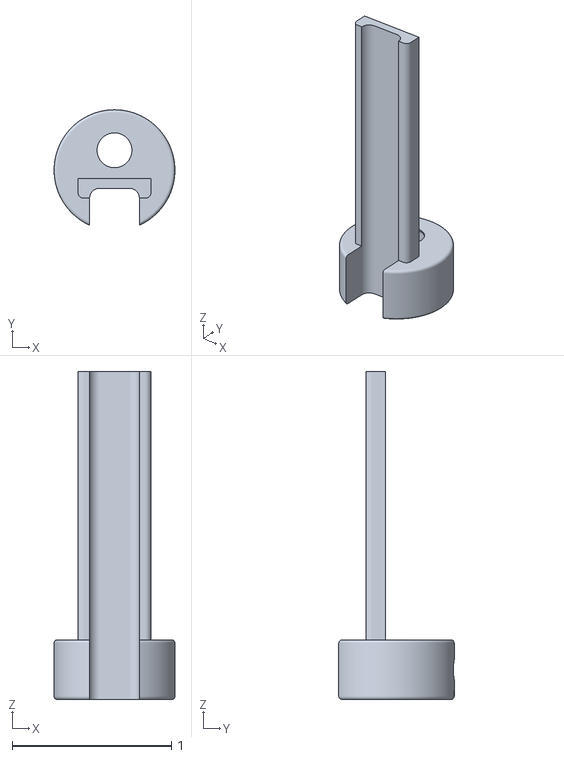
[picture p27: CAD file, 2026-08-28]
docs/mechanical/stl/Board_Holder_REF&NEAR_Part1_(1.75).stl
0.76 x 0.726 x 2.06

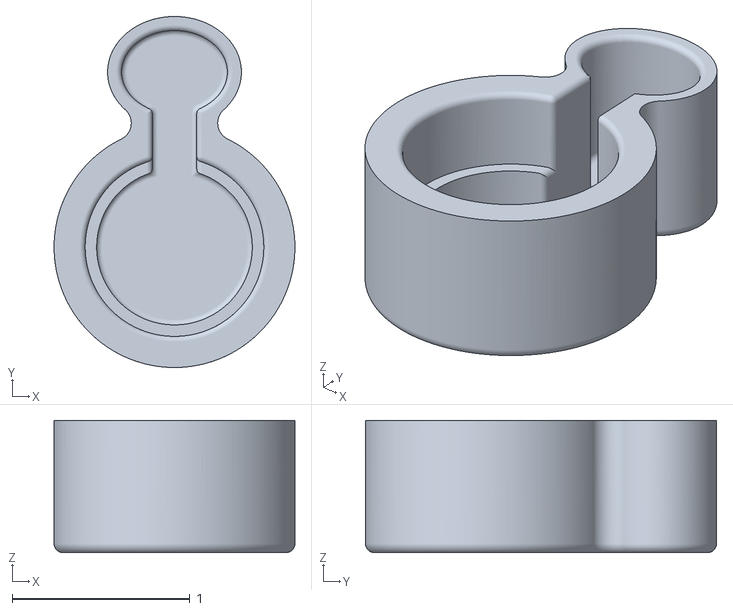
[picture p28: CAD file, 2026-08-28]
docs/mechanical/stl/Wand_Top_Cap.stl
1.35 x 1.97 x 0.743

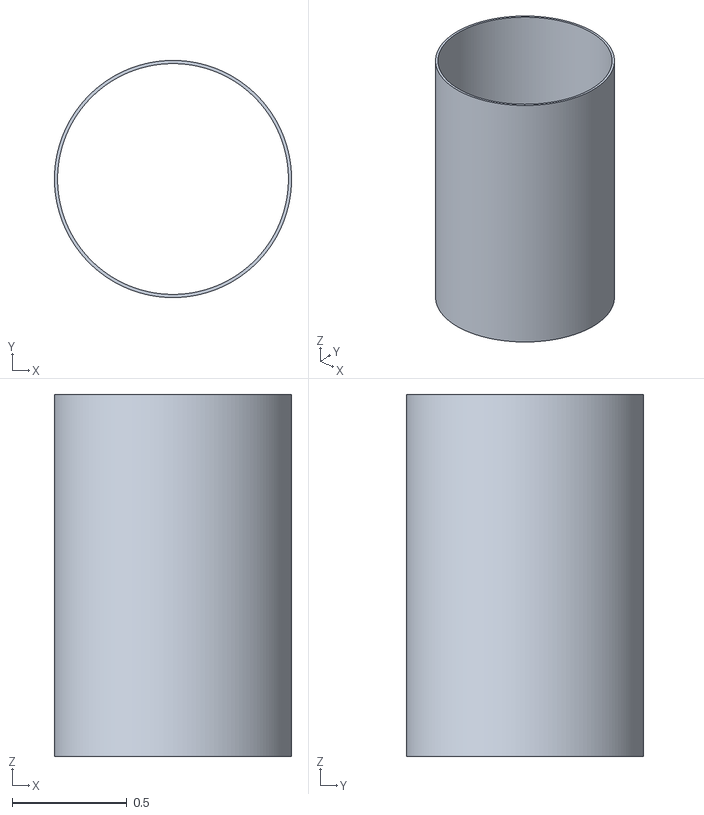
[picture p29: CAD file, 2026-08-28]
docs/mechanical/stl/Shim Sleeve (ID 25.5mm x OD 26.2mm x 40mm) no Base.stl
1.03 x 1.03 x 1.57

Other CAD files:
docs/mechanical/dwg/Magnetic Wand.rev1.dwg
docs/mechanical/dwg/ESP32-S3-Touch-LCD-3.49.DWG
docs/mechanical/stl/Board_Holder_REF&NEAR_Part2_(0.75).stl

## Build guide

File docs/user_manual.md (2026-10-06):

# Magnetic Field Scanner (MFS) - User Manual

**Document Version:** `v5.2.0`
**Last Updated:** October 06, 2026
**Firmware Target:** `v5.1.15`
**Python Ecosystem Target:** `v1.0.0`

Welcome to the User Manual for the Magnetic Field Scanner (MFS). This guide will walk you through the user interface, calibration process, data logging capabilities, and web server connectivity.

---

## 1. User Interface Overview

The MFS features a touchscreen interface driven by LVGL. The interface is designed for rapid field use and zero-latency feedback.

### Main Dashboard
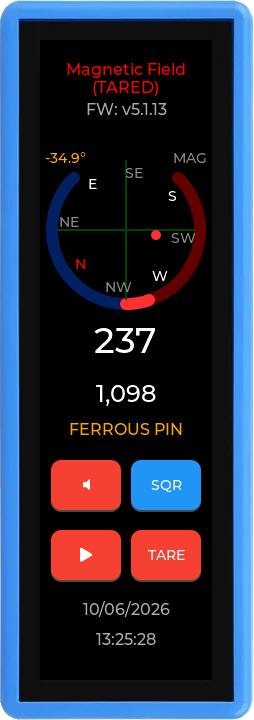
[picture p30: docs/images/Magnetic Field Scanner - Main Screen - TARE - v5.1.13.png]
TARE Mode
| RAW Mode |  | AUTO Mode |
|:---:|:---:|:---:|

* **Polargraphic Display:** A logarithmic sweeping arc that dynamically tracks the spatial gradient from 0 to over 1,000,000 nT without pegging. 
* **True Vertical Gradient (trueZ):** The UI intelligently isolates the vertical component of the magnetic field from the wand's tilt.
  * **Negative Halo (Left/Blue Arc):** Indicates the wand is sweeping the return-path field lines (the "halo") just off to the side of a vertical property pin.
  * **Positive Peak (Right/Red Arc):** Indicates the wand is dead-center over a South pole (top of a property pin), triggering the "FERROUS PIN" identification label.
* **Live Telemetry:** The central labels display the precise absolute magnitude in NanoTeslas (nT), cleanly formatted with thousands separators.
* **Battery & Storage:** Status labels in the hardware tab show battery voltage and logging status.

### Calibration & Tracking (Tare Operations)
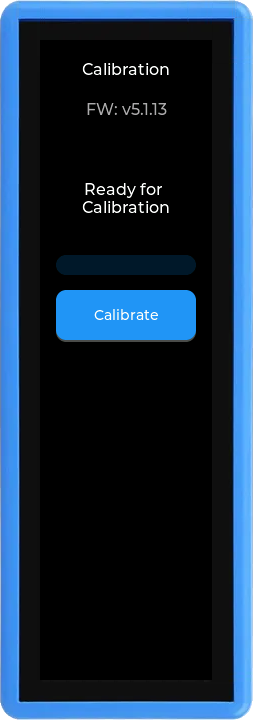
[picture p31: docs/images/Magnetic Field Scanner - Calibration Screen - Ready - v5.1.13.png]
Ready
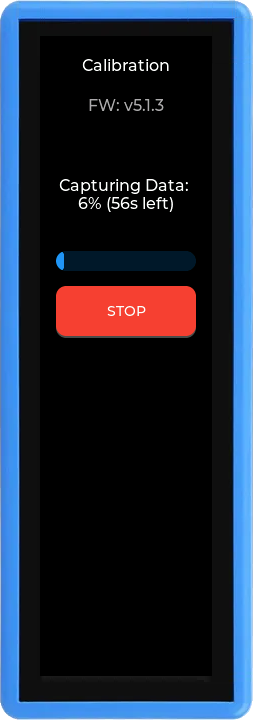
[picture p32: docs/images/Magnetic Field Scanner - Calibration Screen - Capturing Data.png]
Capturing Data
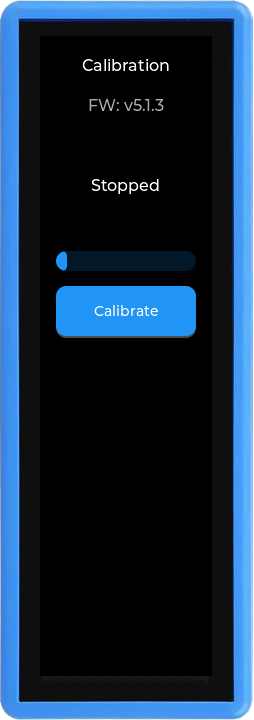
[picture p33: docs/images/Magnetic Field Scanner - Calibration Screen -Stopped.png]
Stopped
|  |  |  |
|:---:|:---:|:---:|

The Wand employs a dual-strategy for zeroing out environmental magnetic interference:
* **Manual Tare:** Memorizes the current environmental gradient shadow (e.g., standing near a car) and subtracts it from all future readings. Tap the Tare button on the screen when standing in a magnetically "clean" area before beginning your sweep.
* **Auto-Tare:** Implements an invisible low-pass filter (multiplier `0.005`) that slowly pulls the baseline back to zero over time to combat temperature drift. Crucially, it **only engages if the gradient jumps by less than 150 nT**. This eats away slow drift while completely ignoring the sharp spikes of a buried utility pipe!

### System & Hardware (Settings Menu)
System & Hardware

* **Audio Toggle:** Mutes or enables the variable-pitch audio feedback. The PWM audio frequency dynamically scales with the spatial gradient magnitude, allowing eyes-free locating.
* **Cycle Count (CC):** Allows you to adjust the internal RM3100 Cycle Count (default `400`). Note: Because the `v5.x` architecture normalizes all raw measurements to physical nanoTeslas (`nT`), the calibration matrix is dimensionless and truly universal. You can change CC seamlessly in the field without drifting!
* **Logging Toggle:** Starts or stops CSV data logging to the active filesystem.
* **Wi-Fi Settings:** Displays the current IP address for Web Server access.

---

## 2. Web Server & Log Management

The MFS hosts a local web server allowing you to wirelessly manage logs and configuration files without removing the SD card.

1. Ensure the MFS is connected to your local Wi-Fi network.
2. Note the IP address displayed on the MFS screen (e.g., `http://192.168.1.xxx`).
3. Open a web browser on your PC or smartphone and navigate to that IP.

### Web Interface Features
*(Please place a screenshot of the web UI here)*
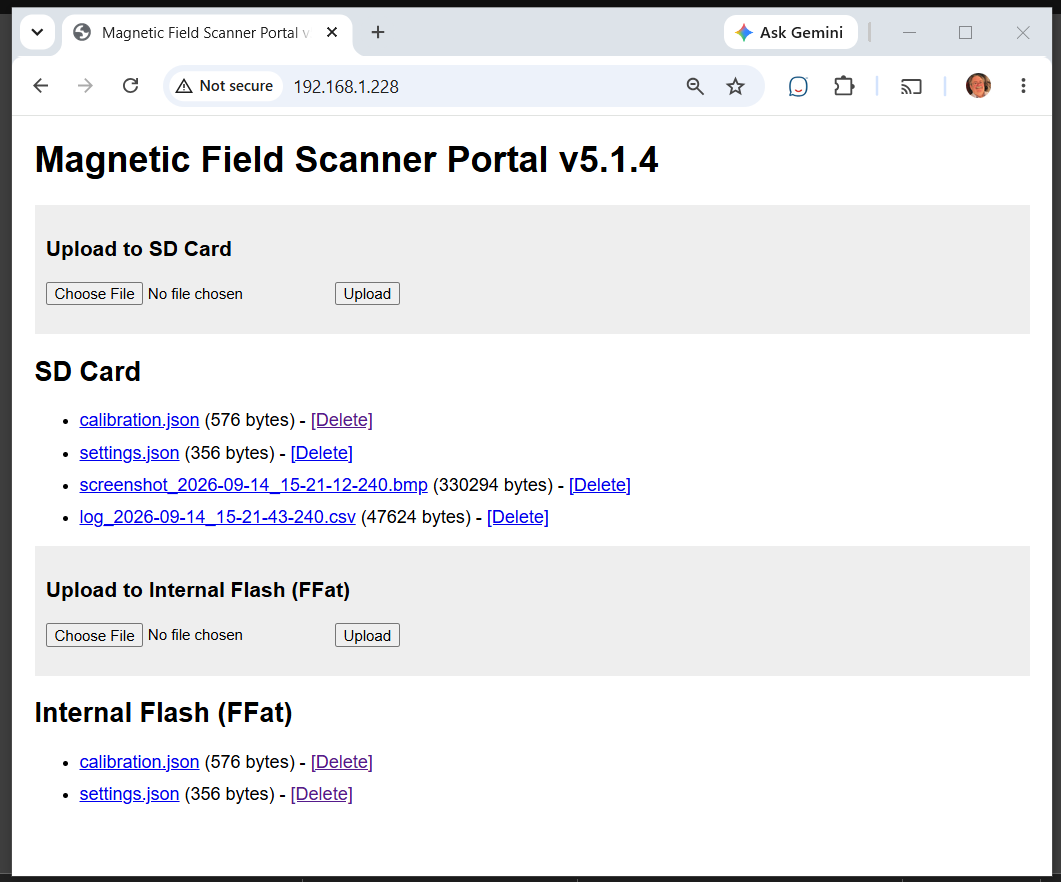
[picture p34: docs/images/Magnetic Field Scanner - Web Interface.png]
Web Interface


* **Dual-Drive Visibility:** The page distinctly lists files stored on the removable **SD Card** versus the internal **FFat** flash memory.
* **Download Logs:** Click any `.csv` log file to download it directly.
* **Configuration Management:** You can download `settings.json` and `calibration.json`, modify them on your PC, and use the Upload button to send them back to the device.

---

## 3. Data Output Format

When logging is active (polling at 400Hz), the MFS generates a `.csv` file (`_log.csv`). To visualize this file, use the companion Python script `analyze_log.py`. The columns are formatted exactly as follows:

| Column(s) | Description |
| :--- | :--- |
| `time_ms` | CPU uptime in milliseconds |
| `timestamp` | Human-readable date and time |
| `version` | Firmware version (e.g., v5.1.x) |
| `voltage` | Battery voltage level (float) |
| `audio_gain` | UI audio gain multiplier setting |
| `cc` | RM3100 Cycle Count (e.g., 400) |
| `refX_raw` -> `tipZ_raw` | Uncalibrated raw axes for Reference and Tip sensors |
| `refX_cal` -> `tipZ_cal` | Hard/Soft iron corrected and Kabsch-aligned axes |
| `calOffsetX` -> `calOffsetZ` | The active Manual Tare offsets currently being applied |
| `gradX, gradY, gradZ` | Spatial gradient vectors (Tip - Ref) |
| `mag` | Total spatial gradient magnitude (The primary detection metric) |
| `nT` | NanoTesla conversion of magnitude |
| `accX, accY, accZ` | IMU Accelerometer data (Gs) |
| `gyrX, gyrY, gyrZ` | IMU Gyroscope data (Degrees per Second) - Maps your physical sweep |
| `freq` | The PWM Audio frequency being output to the speaker (Hz) |
| `is_muted` | Boolean flag indicating if the UI speaker is muted |
| `QW, QX, QY, QZ` | Madgwick 9-DOF Sensor Fusion Quaternions (True 3D Spatial Orientation, Anchored to Magnetic North) |
| `Azimuth, Elevation, Declination` | Real-world Euler angles derived from the quaternions |
| `imu_temp` | Internal temperature reading from the IMU (°C) |

---

## 4. Hardware Calibration

Magnetometers are highly sensitive to local ferromagnetic interference (such as the LCD shield, battery, and screws). To achieve precision gradiometry, the device must perfectly align the magnetic spheres of the Tip and Reference sensors.

**On-Device DSP Calibration:**
Unlike earlier prototypes, **v5.1.x does not require a PC for calibration.** The ESP32-S3 performs all mathematics locally. With calibrate_wand.py as a backup to create calibration.json file.
1. Tap the "Calibrate" button in the UI.
2. Tumbel the wand smoothly in a "Figure-8" pattern through all 3D axes (Pitch, Roll, Yaw) for approximately 30-45 seconds.
3. The device will run a native 9x9 Jacobi Eigenvalue solver to extract the Hard Iron center offsets and Soft Iron 3x3 scaling matrices.
4. It then applies a **Kabsch Rotational Alignment** to mathematically "un-bend" the ~9.4-degree physical flex of the wand's internal fiberglass and board seating on the carrier.
5. The device will automatically save this to `calibration.json` and apply it to all real-time readings.

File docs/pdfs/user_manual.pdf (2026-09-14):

## Magnetic Field Scanner (MFS) - User Manual

Document Version: v5.1.x | Last Updated: September 14, 2026 Firmware Target: v5.1.4 | Python
Ecosystem Target: v1.0.0

Welcome to the User Manual for the Magnetic Field Scanner (MFS). This guide will walk you through the user interface, calibration process, data logging capabilities, and web server connectivity.

### 1. User Interface Overview

The MFS features a touchscreen interface driven by LVGL. The interface is designed for rapid field use and zero-latency feedback.

Main Dashboard

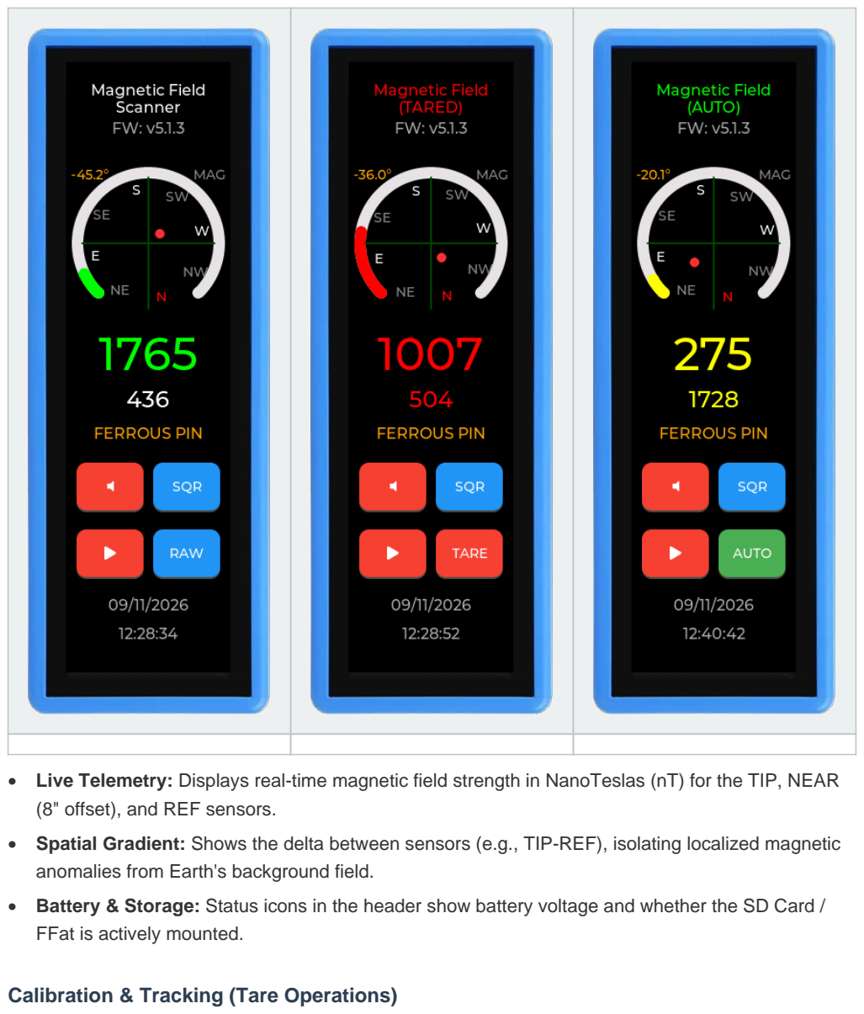
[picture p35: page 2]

- Live Telemetry: Displays real-time magnetic field strength in NanoTeslas (nT) for the TIP, NEAR (8" offset), and REF sensors.
- Spatial Gradient: Shows the delta between sensors (e.g., TIP-REF), isolating localized magnetic anomalies from Earth's background field.
- Battery & Storage: Status icons in the header show battery voltage and whether the SD Card / FFat is actively mounted.

Calibration & Tracking (Tare Operations)

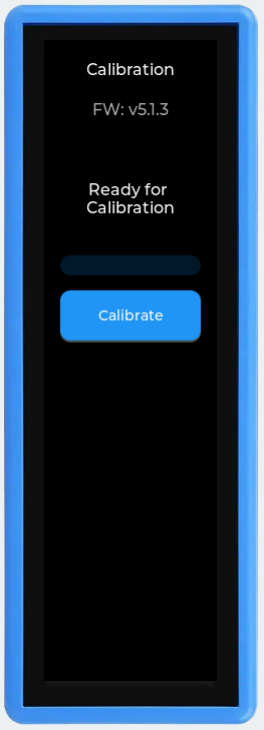
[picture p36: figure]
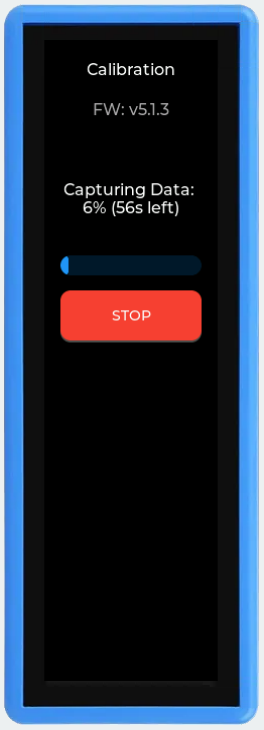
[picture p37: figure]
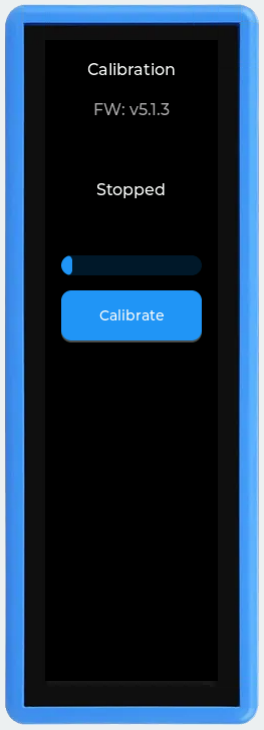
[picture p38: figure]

The Wand employs a dual-strategy for zeroing out environmental magnetic interference:

- Manual Tare: Memorizes the current environmental gradient shadow (e.g., standing near a car) and subtracts it from all future readings. Tap the Tare button on the screen when standing in a magnetically "clean" area before beginning your sweep.
- Auto-Tare: Implements an invisible low-pass filter (multiplier 0.005) that slowly pulls the baseline back to zero over time to combat temperature drift. Crucially, it only engages if the gradient jumps by less than 150 nT. This eats away slow drift while completely ignoring the sharp spikes of a buried utility pipe!

System & Hardware (Settings Menu)

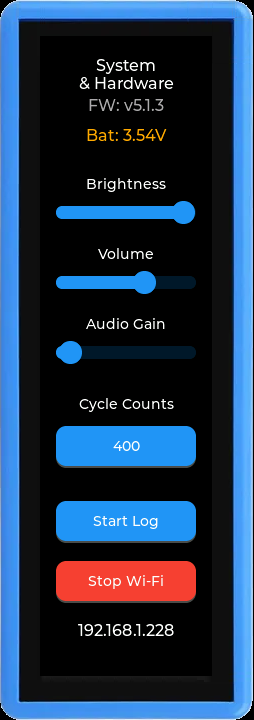
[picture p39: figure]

- Audio Toggle: Mutes or enables the variable-pitch audio feedback. The PWM audio frequency dynamically scales with the spatial gradient magnitude, allowing eyes-free locating.
- Cycle Count (CC): Allows you to adjust the internal RM3100 Cycle Count (default 400). Note: Because the v5.x architecture normalizes all raw measurements to physical nanoTeslas (nT), the calibration matrix is dimensionless and truly universal. You can change CC seamlessly in the field without drifting!
- Logging Toggle: Starts or stops CSV data logging to the active filesystem.

- Wi-Fi Settings: Displays the current IP address for Web Server access.

### 2. Web Server & Log Management

The MFS hosts a local web server allowing you to wirelessly manage logs and configuration files without removing the SD card.

1. Ensure the MFS is connected to your local Wi-Fi network.
2. Note the IP address displayed on the MFS screen (e.g., http://192.168.1.xxx).
3. Open a web browser on your PC or smartphone and navigate to that IP.

Web Interface Features

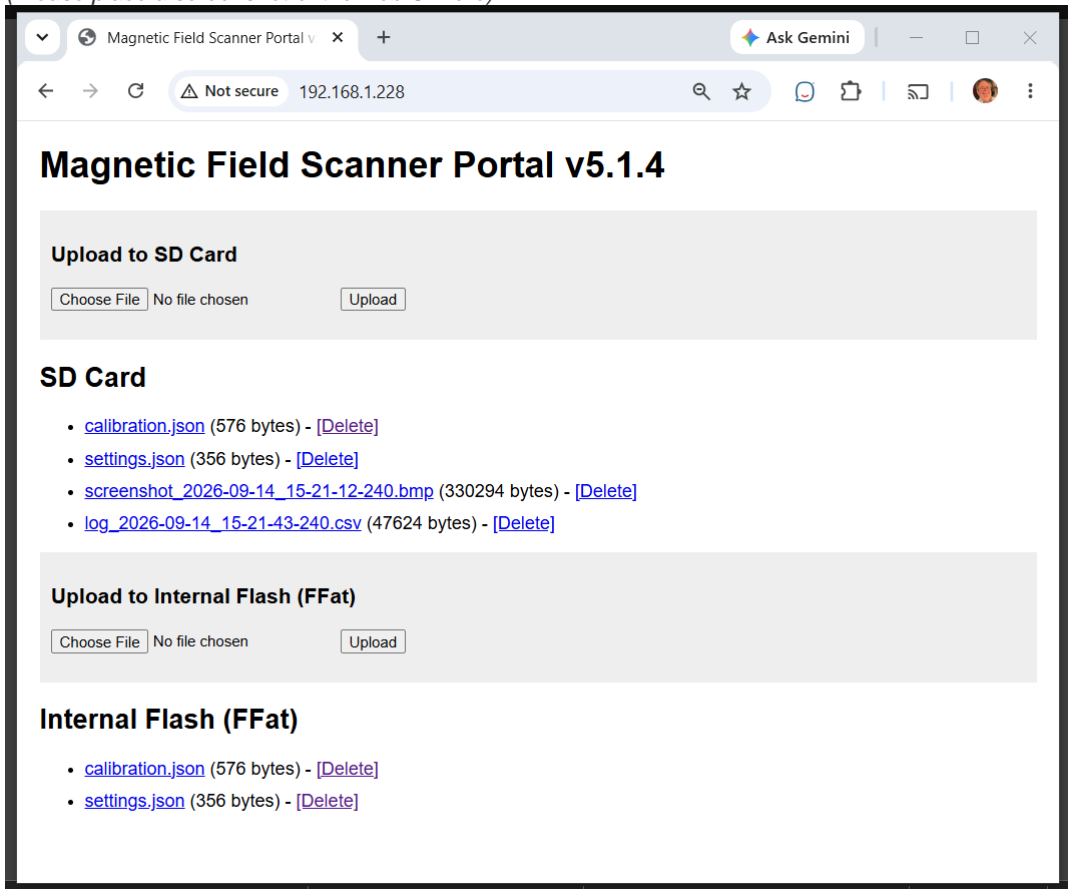
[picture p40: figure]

(Please place a screenshot of the web UI here)

- Dual-Drive Visibility: The page distinctly lists files stored on the removable SD Card versus the internal FFat flash memory.
- Download Logs: Click any .csv log file to download it directly.
- Configuration Management: You can download settings.json and calibration.json, modify them on your PC, and use the Upload button to send them back to the device.

### 3. Data Output Format

When logging is active (polling at 400Hz), the MFS generates a .csv file (_log.csv). To visualize this file, use the companion Python script analyze_log.py. The columns are formatted exactly as follows:

Column(s) | Description
time_ms | CPU uptime in milliseconds
timestamp | Human-readable date and time
version | Firmware version (e.g., v5.1.x)
voltage | Battery voltage level (float)
audio_gain | UI audio gain multiplier setting
cc | RM3100 Cycle Count (e.g., 400)
refX_raw -> tipZ_raw | Uncalibrated raw axes for Reference and Tip sensors
refX_cal -> tipZ_cal | Hard/Soft iron corrected and Kabsch-aligned axes
calOffsetX -> calOffsetZ | The active Manual Tare offsets currently being applied

Column(s) | Description
gradX, gradY, gradZ | Spatial gradient vectors (Tip - Ref)
mag | Total spatial gradient magnitude (The primary detection metric)
nT | NanoTesla conversion of magnitude
accX, accY, accZ | IMU Accelerometer data (Gs)
gyrX, gyrY, gyrZ | IMU Gyroscope data (Degrees per Second) -Maps your physical sweep
freq | The PWM Audio frequency being output to the speaker (Hz)
is_muted | Boolean flag indicating if the UI speaker is muted
QW, QX, QY, QZ | Madgwick 9-DOF Sensor Fusion Quaternions (True 3D Spatial Orientation, Anchored to Magnetic North)
Azimuth, Elevation, Declination | Real-world Euler angles derived from the quaternions
imu_temp | Internal temperature reading from the IMU (°C)

### 4. Hardware Calibration

Magnetometers are highly sensitive to local ferromagnetic interference (such as the LCD shield, battery, and screws). To achieve precision gradiometry, the device must perfectly align the magnetic spheres of the Tip and Reference sensors.

On-Device DSP Calibration: Unlike earlier prototypes, v5.1.x does not require a PC for calibration. The ESP32-S3 performs all mathematics locally. With calibrate_wand.py as a backup to create calibration.json file.

1. Tap the "Calibrate" button in the UI.
2. Tumbel the wand smoothly in a "Figure-8" pattern through all 3D axes (Pitch, Roll, Yaw) for approximately 30-45 seconds.
3. The device will run a native 9x9 Jacobi Eigenvalue solver to extract the Hard Iron center offsets and Soft Iron 3x3 scaling matrices.
4. It then applies a Kabsch Rotational Alignment to mathematically "un-bend" the ~9.4-degree physical flex of the wand's internal fiberglass and board seating on the carrier.
5. The device will automatically save this to calibration.json and apply it to all real-time readings.

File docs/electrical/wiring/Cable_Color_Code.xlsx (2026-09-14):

Waveshare
Pin | Function | CABLE | Note
3V3 | 3V3 | ORG
GND | GND | GRN/WHT&BLU/WHT
IO47 | SDA | GRN | 4.7K Pullup to 3V3 in cable
IO48 | SCL | BLU | 4.7K Pullup to 3V3 in cable
IO01 | DRDY_TIP | BRN
IO02 | DRDY_REF | BRN/WHT
IO05 | DRDY_NEAR | ORG/WHT
RM3100 | I2C Address: | 0x23 | 0x22 | 0x21
Pin | Breakout | TIP | NEAR | REF
1 | CS/SA0 | ORG (3V3) | GND (GRN/WHT&BLU/WHT) | ORG (3V3)
2 | MOSI/SDA | GRN | GRN | GRN
3 | MISO/SA1 | ORG (3V3) | ORG (3V3) | GND (GRN/WHT&BLU/WHT)
4 | SCK/SCL | BLU | BLU | BLU
5 | 3V3 | ORG (3V3) | ORG (3V3) | ORG (3V3)
6 | GND | GND (GRN/WHT&BLU/WHT) | GND (GRN/WHT&BLU/WHT) | GND (GRN/WHT&BLU/WHT)
7 | DRDY | BRN (DRDY_TIP) | ORG/WHT (DRDY_NEAR) | BRN/WHT (DRDY_REF)
8 | I2C/SPI | ORG (3V3) | ORG (3V3) | ORG (3V3)

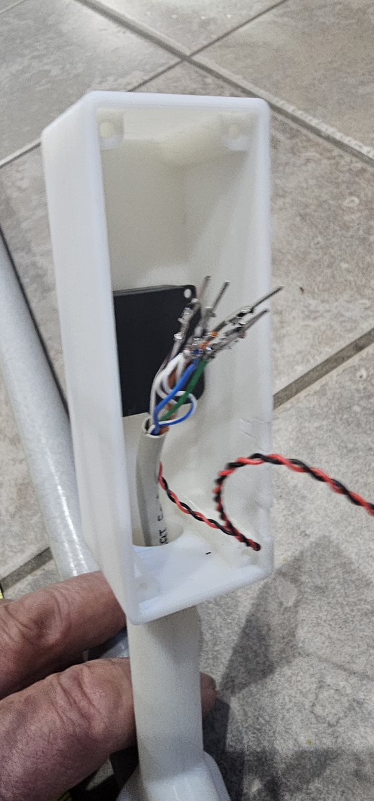
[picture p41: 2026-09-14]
docs/images/Magnetic Field Scanner - Exploded View - Closeup Wand Wiring (20260914_164039).png

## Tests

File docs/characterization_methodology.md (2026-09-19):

# System Characterization Methodology

This document outlines the strict empirical methodology required to benchmark and characterize the performance limits of the Magnetic Field Scanner. 

The resulting data from these physical tests is processed by `scripts/characterize_system.py` to generate the official `characterization.md` datasheet.

## Characterization Jig & Staging

<p align="center">
  Characterization Testing Field Panorama
</p>

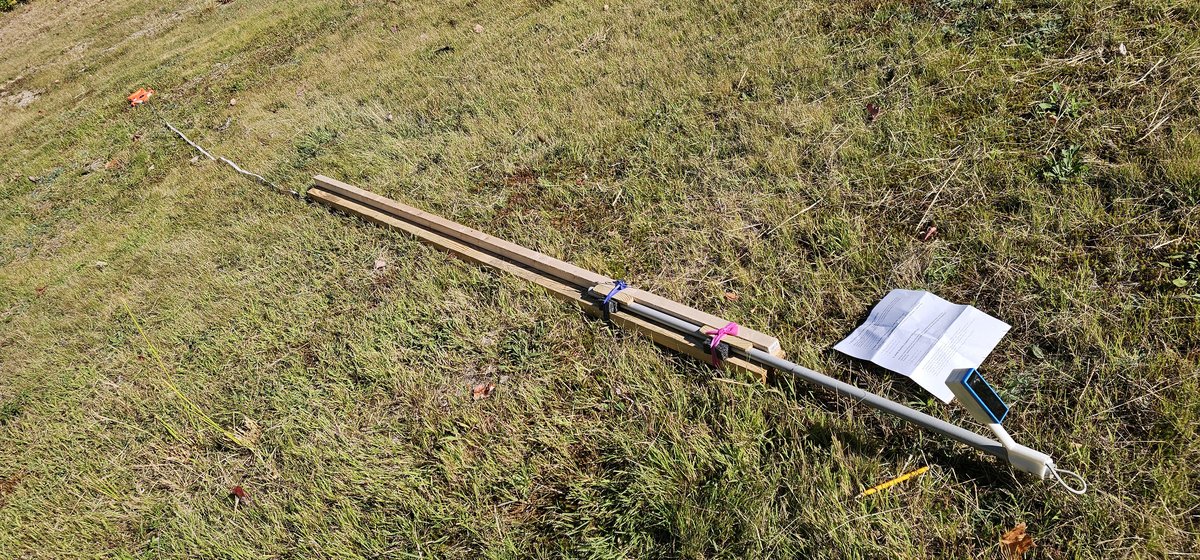
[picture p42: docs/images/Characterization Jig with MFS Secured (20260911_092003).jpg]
MFS Secured in Jig
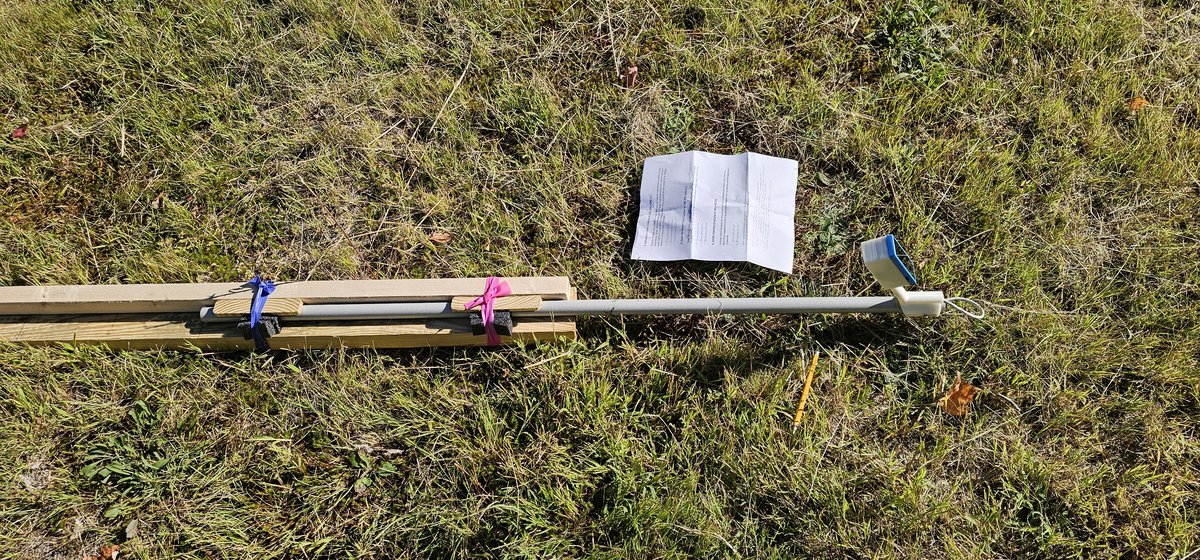
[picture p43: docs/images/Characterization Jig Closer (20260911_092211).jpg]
Jig Close-Up View
|  |  |
|:---:|:---:|

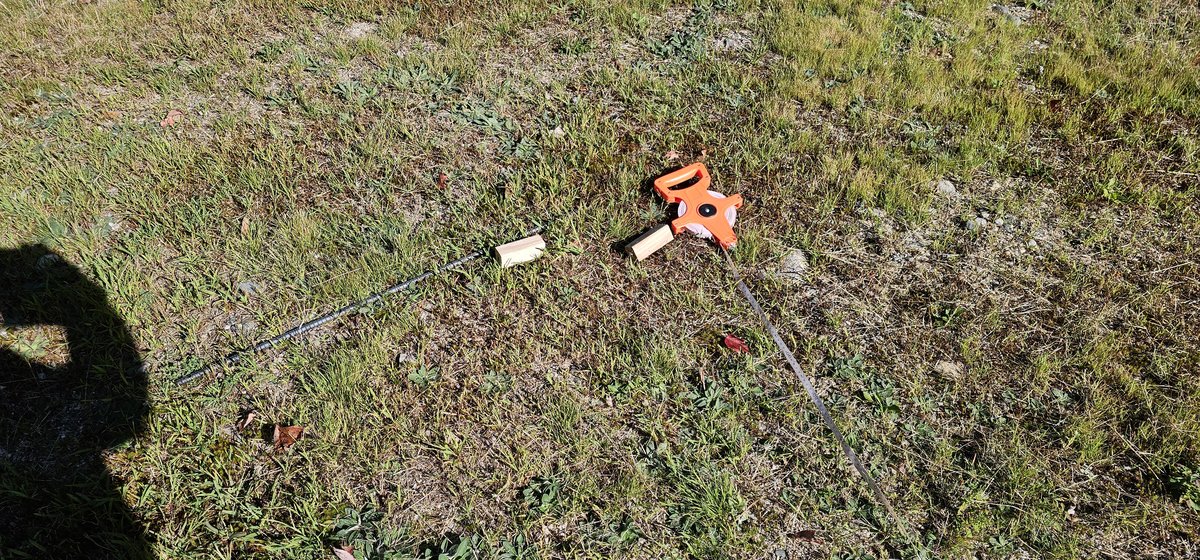
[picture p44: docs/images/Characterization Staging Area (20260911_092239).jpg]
Staging Area showing targets
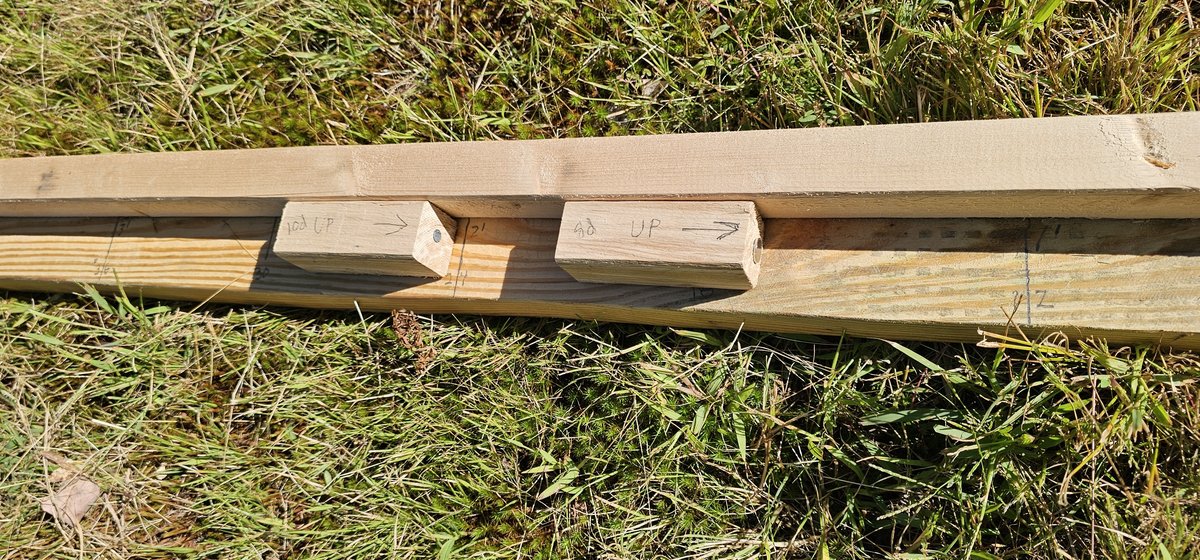
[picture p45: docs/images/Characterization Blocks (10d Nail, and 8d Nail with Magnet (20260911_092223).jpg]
10d Nail and Magnet Block Targets
|  |  |
|:---:|:---:|

<p align="center">
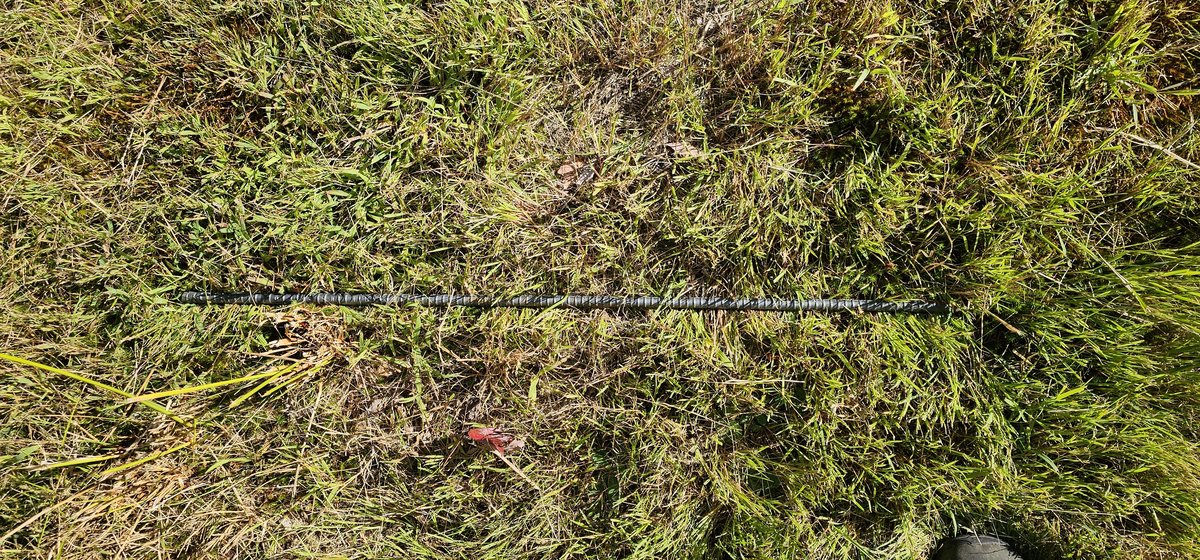
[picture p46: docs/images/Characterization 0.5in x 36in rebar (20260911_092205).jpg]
36-inch Steel Rebar Target
  
</p>

### 45-Degree Rebar Anomaly Jig

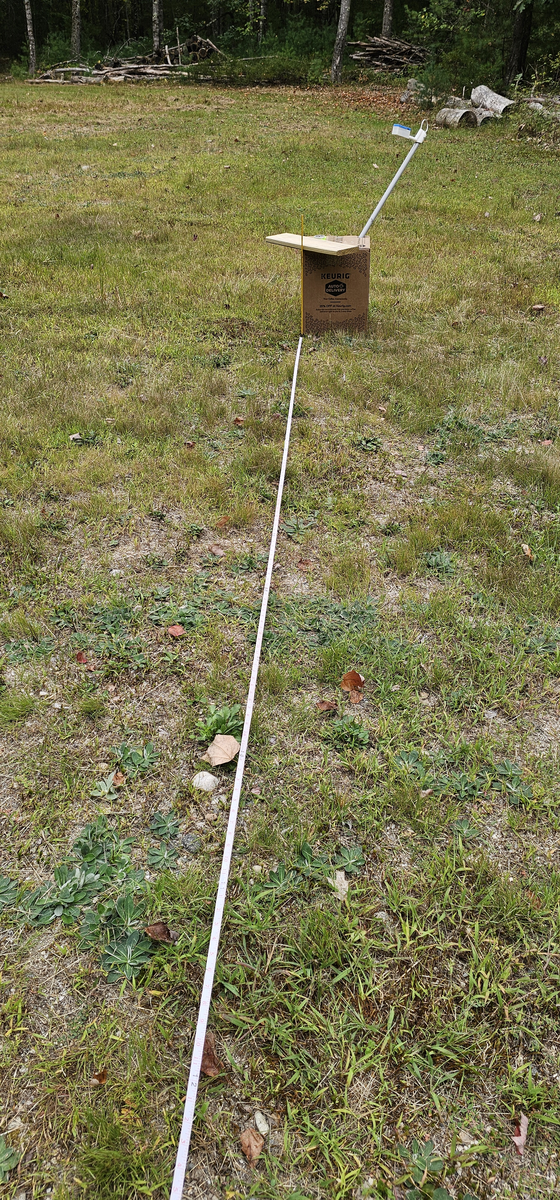
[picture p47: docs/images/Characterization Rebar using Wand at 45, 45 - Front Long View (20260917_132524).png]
45-Degree Jig - Front Long View
| 45-Degree Jig - Left Side |  |
|:---:|:---:|

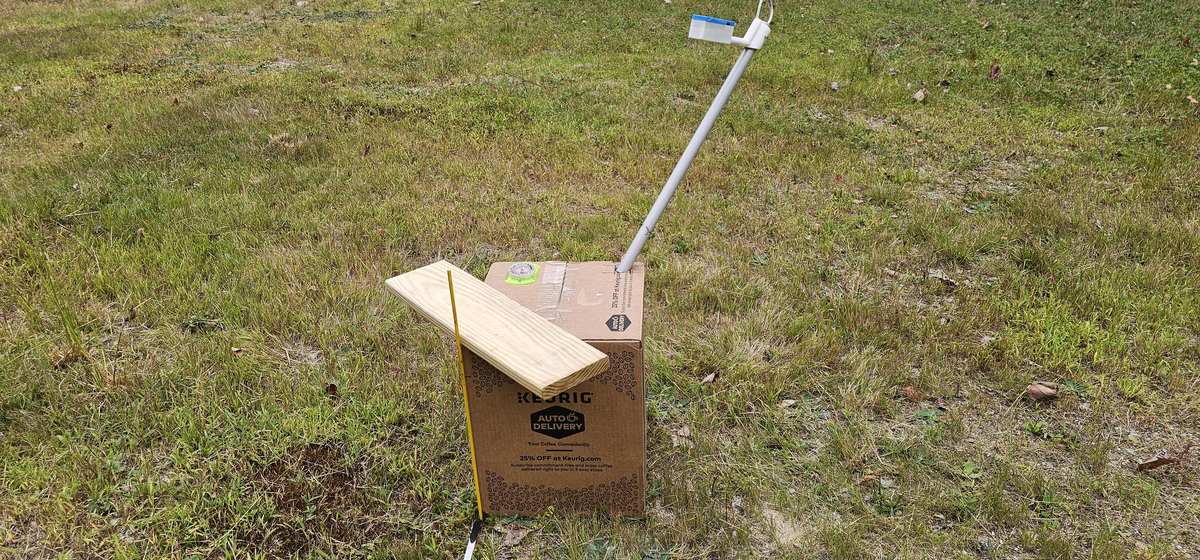
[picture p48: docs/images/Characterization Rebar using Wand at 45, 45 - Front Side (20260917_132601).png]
45-Degree Jig - Front Side
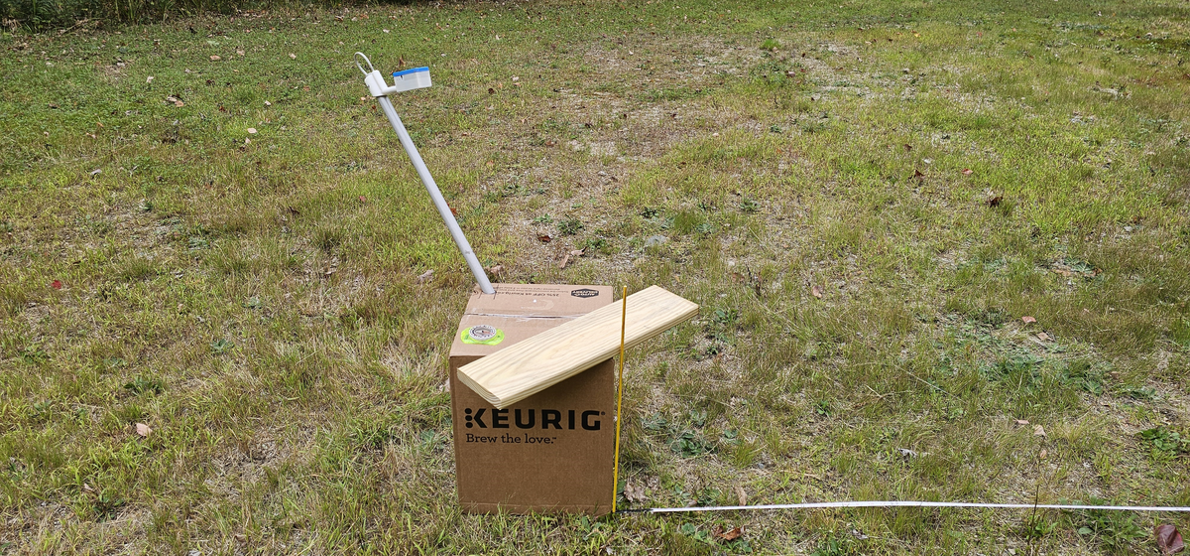
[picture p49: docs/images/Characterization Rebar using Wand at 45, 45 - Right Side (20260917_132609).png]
45-Degree Jig - Right Side
|  |  |
|:---:|:---:|

## Testing Environment & Configuration
To ensure statistically valid and reproducible results across the entire architectural range, the wand must be benchmarked across multiple Cycle Counts.
- **Cycle Count Sweeps:** The system dynamically normalizes all readings to nanoTeslas (nT) regardless of the Cycle Count (CC). However, changing the CC fundamentally alters the hardware's update speed, physical saturation limit, and RMS noise floor. Therefore, benchmark sets should be collected at `CC=200` (Fast/Noisy/High-Saturation), `CC=400` (Baseline), and `CC=3200` (Slow/Quiet/Low-Saturation) to fully characterize the hardware envelope.
- **Calibration Context:** Because the `v5.x.x` architecture normalizes all raw sensor counts to `nT` *before* the calibration matrix is applied, a single calibration profile is mathematically universal across all Cycle Counts. Calibration should exclusively be performed at `CC=400`. (Performing calibration at `CC=3200` is not recommended because the 5Hz update rate is too slow to capture a smooth 3D rotational sphere, while `CC=400` at ~50Hz is perfect).
- **Mode:** The wand UI must be set to **RAW Mode** (TARE and AUTO-TARE disabled). This exposes the naked noise floor and raw mathematical stability of the hardware, unimpeded by software UI filters or zeroing logic.
- **Environment:** All baseline tests must be conducted in a magnetically quiet area, free of moving ferrous objects or active EMI sources. Buffer zones for targets should be at least 40 feet away when not actively tested.

---

## The 6-Stage Benchmark Hierarchy

The order of testing is strictly hierarchical to physically protect the sensor calibration. Tests that risk permanently magnetizing the wand's soft iron (hysteresis) or mechanically twisting the sensor board inside the tube (torsion) are placed at the absolute end.

### 1. Calibration Consistency (`cal_1.csv` to `cal_5.csv`)
**Purpose:** Proves the mathematical repeatability of the figure-8 calibration routine by ensuring the Kabsch algorithm converges on statistically identical hard/soft iron matrices across multiple runs.
**Execution:**
1. Stand in a magnetically quiet area.
2. Trigger the on-wand calibration routine at `CC=400`.
3. Perform the standard 3D figure-8 tumbling sequence until completion.
4. Save the log as `cal_1.csv`.
5. Repeat this exact process 4 more times to collect 5 separate calibration logs.

### 2. The Noise Floor Log (`log_noise.csv`)
**Purpose:** Establishes the RMS background noise of the system. This dictates the absolute smallest localized anomaly the wand can reliably detect above the Earth's background field.
**Execution:**
1. Place the wand on a non-magnetic surface (e.g., a wooden table or the ground).
2. Do not touch or move the wand.
3. Record 10 seconds of data for `CC=200`, `400`, `800`, `1600`, and `3200`.

### 3. Combined Precision & Isolation Log (`log_repeat.csv`)
**Purpose:** Proves Gradiometer Isolation (a massive anomaly at the Tip does not distort the Earth's background field at the Reference sensor) and Measurement Precision (repeatability across a physical $1/r^3$ staircase).

*Note on Single-Axis Testing: Because the wand runs the Kabsch 9-parameter Ellipsoid Fit algorithm (which mathematically forces all three physical coils to conform to a geometrically perfect, identical sphere), it is only necessary to perform this physical precision test on a single primary axis (e.g., the forward-pointing Z or Y axis). The calibration math guarantees that if one axis is perfectly isolated and precise, the other two share that exact same normalized geometric behavior.*

**Execution:**
1. Lock the wand physically on a table so it cannot move.
2. Target: A 10d nail in a wooden block, starting 2 feet (24") away, axially aligned to the wand.
3. Start logging.
4. Slide the block toward the tip in **6-inch increments**, pausing for **1 second** at each step (24", 18", 12", 6").
5. Stop at the tip (0") and pause for **3 seconds**.
6. Reverse direction in 6-inch increments (6", 12", 18", 24"), pausing for 1 second at each step.
7. Repeat this entire pass 10 times in a single log.
8. Repeat for `CC=200`, `400`, and `3200`.

### 4. The Saturation Limit Log (`log_saturation.csv`)
**Purpose:** Empirically proves the maximum magnetic field strength the RM3100 sensors can ingest before hardware clipping blinds the gradiometer, while capturing the steep $1/r^3$ dipole curve of a rare-earth magnet.
**Warning:** This test uses a massive magnet and risks permanently magnetizing the wand's soft iron components (hysteresis).
**Execution:**
1. Wand is fixed on the ground. Magnet is staged at ~10 feet.
2. Start logging. Walk to the 10' mark and pick up the magnet.
3. Approach the 4-foot (48") mark.
4. Slide the magnet toward the tip in **6-inch increments**, pausing for **1 second** at each step.
5. Stop at the tip (or as close as you can get before the UI values visually flatline/clip) and pause for **3 seconds**.
6. Reverse direction in 6-inch increments back to 4 feet, pausing for 1 second at each step.
7. Return the magnet to the 10-foot staging area and stop logging.
8. Repeat for `CC=200`, `400`, and `3200`.

### 5. Open Air Rebar Test (`log_rebar.csv`)
**Purpose:** Captures the magnetic dipole signature of a massive ferrous target (36" rebar) to automatically calculate the maximum Absolute Detection Range via an inverse-cube ($1/r^3$) curve fit.
**Execution:**
1. Wand is fixed on the ground alongside a non-metallic tape measure. Rebar is staged at ~10 feet.
2. Start the log at the wand handle, then walk out to the 10' mark.
3. Pick up the rebar, holding it perpendicular to the ground.
4. Approach the 8-foot mark and begin the staircase: 1-foot increments (8', 7', 6', 5', 4', 3', 2', 1'), pausing for **1 second** per step.
5. Pause at the TIP (0') for **3 seconds**.
6. Reverse direction in 1-foot increments back to 8 feet, pausing for 1 second per step.
7. Stop logging. 
8. Repeat for `CC=200`, `400`, and `3200`.

### 6. The AHRS Stability Log (`log_ahrs.csv`)
**Purpose:** Proves that the Kabsch algebraic transformation properly isolates the physical orientation of the dual sensors.
**Warning:** Violent swinging can physically twist the sensor board inside the tube, permanently invalidating the Kabsch matrix. This test must be performed last.
**Execution:**
1. Hold the wand in the air and point it directly North.
2. Start logging.
3. Aggressively pitch the wand up and down by 45 degrees, and roll it left and right by 45 degrees for 10 seconds.
4. Repeat for `CC=200` and `400`.

### 7. The 45-Degree Rebar Anomaly Test
**Purpose:** An extreme empirical stress test to prevent single-axis core saturation under massive magnetic loads. By locking the stationary wand at a 45-degree pitch and 45-degree roll while walking a vertical anomaly (rebar) towards it, the anomaly's field lines are geometrically distributed across the X, Y, and Z axes simultaneously. This prevents the saturation lockup seen when the wand is horizontal and proves the system's dynamic range.
**Execution:**
1. Secure the wand in a custom 13"x13"x16" cardboard box jig (via a top cut-out), elevating the rear of the 46.5" wand so the tip touches the ground at exactly a 45-degree pitch and 45-degree roll.
2. Hold the 36-inch 0.5" rebar vertically (perpendicular to the ground) so the bottom touches the ground.
3. Walk the rebar towards the tip in 12-inch increments, pausing for several seconds at each step.
4. Repeat for `CC=400`, `800`, `1600`, and `3200`.

---

## Generating the Datasheet

Once all benchmark logs are collected in the workspace, run the following Python command to ingest the data, execute the statistical analysis, and generate the final datasheet:

```bash
python scripts/characterize_system.py \
  --noise "log_noise_200.csv" "log_noise_400.csv" "log_noise_3200.csv" \
  --repeatability "log_repeat_200.csv" "log_repeat_400.csv" "log_repeat_3200.csv" \
  --saturation "log_saturation_200.csv" "log_saturation_400.csv" "log_saturation_3200.csv" \
  --rebar "log_rebar_200.csv" "log_rebar_400.csv" "log_rebar_3200.csv" \
  --ahrs "log_ahrs_200.csv" "log_ahrs_400.csv" "log_ahrs_3200.csv" \
  --calibration "cal_1.csv" "cal_2.csv" "cal_3.csv" "cal_4.csv" "cal_5.csv"
```
The resulting `characterization.md` will be placed in the `docs/` folder.

### Understanding Saturation Testing
When characterizing the wand's dynamic range, it is crucial to understand that there are two distinct physical phenomena being tested:
1. **The Rebar Test (Digital Clipping):** By using a large piece of steel (like a 36-inch rebar) which concentrates the Earth's field, we can subject the sensor to a massive ~500 µT anomaly. This tests the **Digital Clipping Limit** of the internal 24-bit integer counter without physically destroying the magnetic properties of the sensor core.
2. **The Neodymium Magnet Test (Physical Core Saturation):** By bringing a rare-earth magnet directly to the tip, we subject the sensor to an overwhelming Gauss-level magnetic field. This forcibly pushes the RM3100's inductor core past its B-H curve limit, causing the inductance to collapse. This tests the **Physical Core Blind State**, where the sensor fails to oscillate and outputs a `0` count (resulting in the Gradiometer displaying the Earth's background field). 

Both tests are strictly required to map the complete failure envelope of the wand across different Cycle Counts.

### Test 3: Real-World Property Pin (Direct Approach)

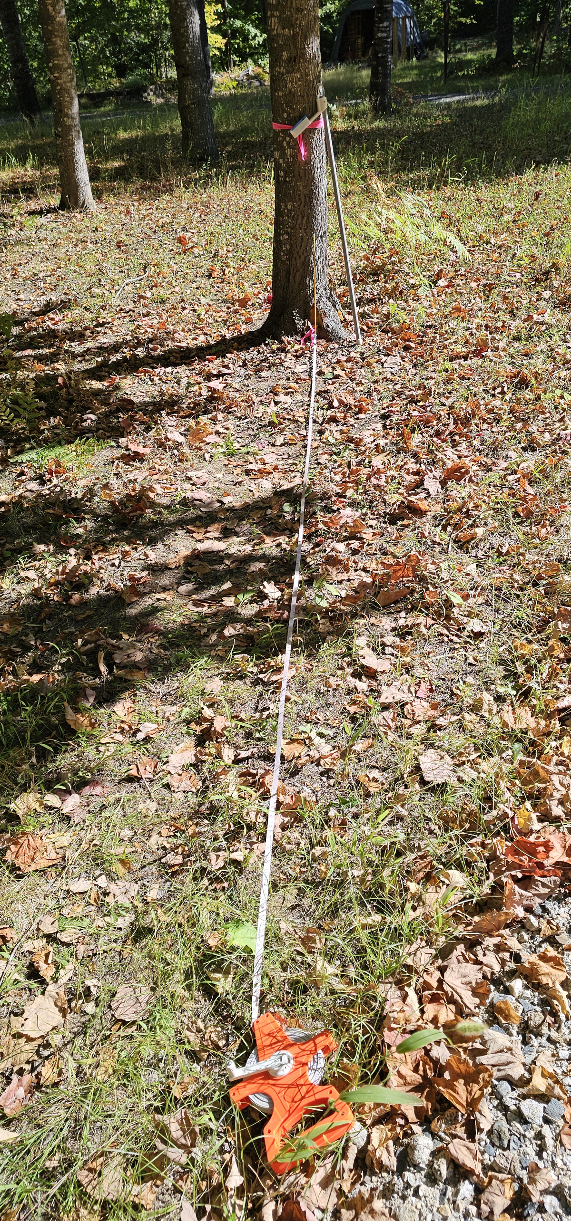
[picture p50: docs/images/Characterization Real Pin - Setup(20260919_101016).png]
Real Pin Setup


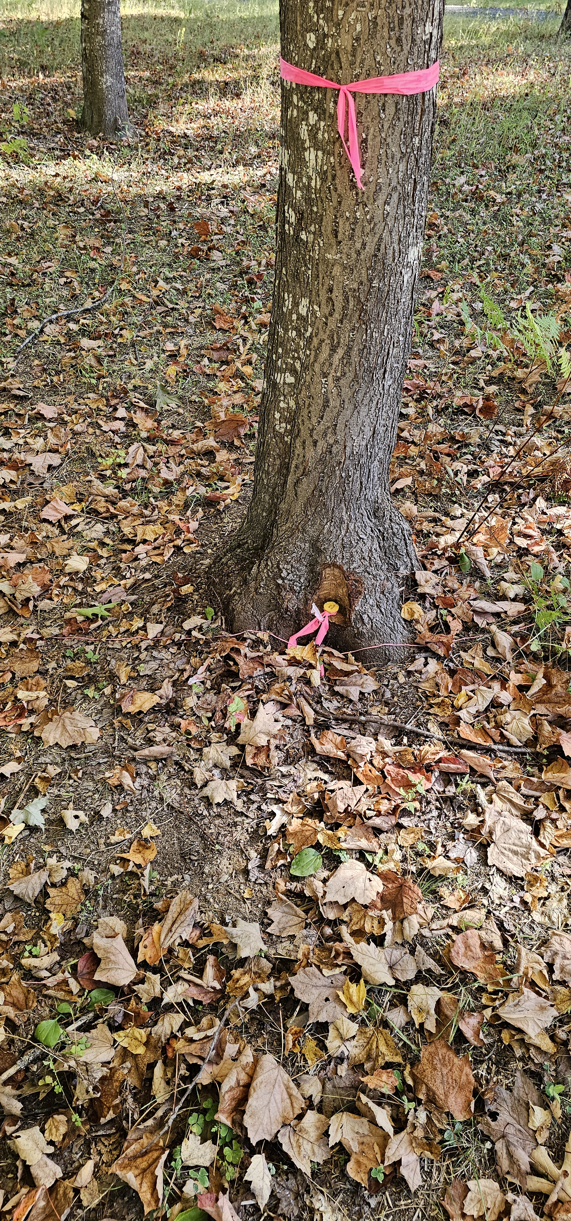
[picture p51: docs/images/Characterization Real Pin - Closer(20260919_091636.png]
Real Pin Closer


**Goal:** To validate the theoretical $1/r^2$ depth/range detection curve against an actual 5/8" x 36" steel property pin buried in the earth.

**Steps:**
1. Locate a known buried property pin in an open yard.
2. Lay a cloth tape measure radially outward from the pin, marking a starting point exactly 10 feet away.
3. Stand at the 10-foot mark facing the pin, holding the wand naturally (roughly 45-degree pitch towards the ground).
4. Start the log. Pause for a 5 count to establish a clear Earth baseline.
5. Advance 1 foot directly towards the pin. Pause for a 5 count.
6. Repeat 1-foot advancements and 5-count pauses until the wand is directly over the pin (Distance = 0).
7. Pause over the pin for an 8 to 10 count.
8. Retreat backward in 1-foot increments, pausing at each step (5 count), until returning to the 10-foot marker. 
9. Stop the log, switch Cycle Count, and repeat.

### Test 4: Real-World Property Pin (Pendulum Sweep)
**Goal:** To characterize the spatial signature (Gaussian bell curves) of a buried property pin as it would appear on a user's screen during a standard metal-detector sweeping motion.

**Steps:**
1. Stand at the 10-foot marker facing the pin, holding the wand normally at ~45-degree pitch.
2. Start the log. Pause for a 1 to 2 count.
3. Yaw the wand ~80 to 90 degrees to the left (establishing the far-left baseline).
4. Sweep the wand smoothly to the right, crossing the center line (over the pin vector) to ~80 to 90 degrees right. Pause for a 10 to 15 count.
5. Sweep the wand smoothly back to the left side. Pause for a 10 to 15 count.
6. Sweep the wand back to the center line. Pause for a 1 to 2 count.
7. Advance 1 foot towards the pin.
8. Repeat the exact sweep pattern (Center -> Left -> Right -> Left -> Center) at every 1-foot increment until reaching the pin (Distance = 0).
9. Retreat backward using the same sweeping pattern at each step until returning to the 10-foot marker. 
10. Stop the log, switch Cycle Count, and repeat.

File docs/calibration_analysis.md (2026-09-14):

# Golden Calibration Log Analysis

We've plotted the data from `cal_6_calibration_2026-09-11_08-34-00-240.csv` to visualize the quality of the calibration and observe the sensor readings over the test duration.

## Magnetometer Calibration (Hard and Soft Iron)

This visualization shows how the raw magnetometer readings (which form a distorted, off-center ellipsoid due to hard/soft iron interference) are transformed into a clean sphere centered on the origin.

````carousel
![Raw Magnetometer Data](images/calibration/mag_raw_3d.png)
<!-- slide -->
![Calibrated Magnetometer Data](images/calibration/mag_cal_3d.png)
````

**Observations:**
- **Raw Data:** The reference and tip sensors have massive hard-iron offsets (the ellipsoids are very far from 0,0,0, particularly the reference sensor which is offset deeply in the -Z and +X directions, and the tip sensor offset deeply in the +X, +Y directions).
- **Calibrated Data:** The spheres are perfectly centered on the origin and are uniform in radius. This confirms the Python Kabsch alignment and soft/hard iron correction matrices are performing beautifully. The baseline magnetic field magnitude is consistently normalized to roughly 50,000 nT.

### Coverage Assessment

The Python calibration tool evaluates how completely the sensor was rotated through all 3D axes. A higher coverage percentage ensures the resulting calibration sphere is accurate in all orientations.

```text
--- Reference Sensor Coverage Assessment ---
Ideal Magnetic Radius: 50547 nT
X-Axis Coverage: 96.6%
Y-Axis Coverage: 99.7%
Z-Axis Coverage: 72.9%

--- Tip Sensor Coverage Assessment ---
Ideal Magnetic Radius: 50918 nT
X-Axis Coverage: 95.4%
Y-Axis Coverage: 100.8%
Z-Axis Coverage: 72.8%

--- Physical Misalignment Analysis ---
Sensors are physically misaligned by: 9.86 degrees
```

**Observations:** This is a fantastic "golden" calibration. Both the X and Y axes achieved near-perfect ~100% coverage. The Z-axis achieved ~73% on both sensors, which is very typical because fully tumbling a 3-foot wand through the Z-axis (pointing straight up and straight down) is mechanically difficult indoors.

## IMU Sensor Readings

The accelerometer and gyroscope readings over the course of the calibration sequence.

IMU Time Series

**Observations:**
- The calibration involved a lot of dynamic movement (as expected during a figure-8 or tumbling sweep). 
- The accelerometer sees 1g total magnitude properly distributed across the axes depending on orientation.
- The gyroscope properly tracks the rotations. Note: This specific log did not contain a 1-second stationary hold at the end, so the script skipped the FOC (Fast Offset Calibration) for the gyro.

## Computed Euler Angles (Sensor Fusion)

Here are the Azimuth and Elevation output from the Madgwick filter during the calibration sequence.

Euler Angles over Time

**Observations:**
- Since the firmware resolved the magnetometer negation bug, we can see the Elevation curve successfully traversing the full mechanical ranges during the tumble without stalling or fighting the IMU!
- The orientation output is incredibly smooth and stable.

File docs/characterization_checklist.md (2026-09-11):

# Characterization Log Collection Checklist

To fully characterize the hardware envelope across multiple Cycle Counts (CC), you must perform a "Sweep" for tests 2 through 6. All logs must be captured in **RAW mode**.

**WARNING:** The order of these tests is strictly hierarchical. Do NOT perform the Saturation or AHRS tests until the others are complete.

## 1. Calibration Performance (Capture ONLY at 400 CC)

*Note: Because calibration matrices are applied to normalized `nT` values, a single matrix works universally across all Cycle Counts. It must be performed at 400 CC to ensure a high-resolution 50Hz capture of the tumbling sphere.*

- [ ] `cal_1.csv` (Figure-8 calibration sequence)
- [ ] `cal_2.csv`
- [ ] `cal_3.csv`
- [ ] `cal_4.csv`
- [ ] `cal_5.csv`

## 2. Noise Floor (Capture at 200, 400, 800, 1600, 3200 CC)

Set the wand on a non-magnetic surface. Do not touch it. Let it log perfectly still for 10 seconds.
- [ ] `log_noise_200.csv`
- [ ] `log_noise_400.csv`
- [ ] `log_noise_800.csv`
- [ ] `log_noise_1600.csv`
- [ ] `log_noise_3200.csv`

## 3. Combined Precision & Isolation (Capture at 200, 400, 3200 CC)

Target: A 10d nail starting 24" away. Lock the wand physically on a table. 
Protocol: Slide block in 6" increments (1s pause per step). At tip (0"), pause for 3s. Reverse direction in 6" increments (1s pause). Repeat 10x per log.
- [ ] `log_repeat_200.csv`
- [ ] `log_repeat_400.csv`
- [ ] `log_repeat_3200.csv`

## 4. Saturation Limit (Capture at 200, 400, 3200 CC)

*Warning: This test uses a massive magnet and risks permanently magnetizing the wand's soft iron components.*
Target: Strong magnet staged 10' away. Wand fixed on ground.
Protocol: Start at 4' mark. Slide in 6" increments (1s pause per step). At tip (or when UI clips), pause for 3s. Reverse direction in 6" increments (1s pause).
- [ ] `log_saturation_200.csv`
- [ ] `log_saturation_400.csv`
- [ ] `log_saturation_3200.csv`

## 5. Open Air Rebar Test (Capture at 200, 400, 3200 CC)

Target: 36" rebar starting 8' away. Wand fixed on ground.
Protocol: Walk target in 1' increments (1s pause per step). At tip (0'), pause for 3s. Reverse direction in 1' increments. (1 pass per log).
- [ ] `log_rebar_200.csv`
- [ ] `log_rebar_400.csv`
- [ ] `log_rebar_3200.csv`

## 6. AHRS Stability (Capture at 200, 400 CC)

*Warning: Violent swinging can twist the sensor board, invalidating the Kabsch matrix.*
Point the wand North, aggressively pitch it up and down 45 degrees, and roll it left and right 45 degrees for 10 seconds.
- [ ] `log_ahrs_200.csv`
- [ ] `log_ahrs_400.csv`

---
*Once all logs are collected, process them simultaneously using:*
```bash
python scripts/characterize_system.py \
  --noise "log_noise_200.csv" "log_noise_400.csv" "log_noise_3200.csv" \
  --repeatability "log_repeat_200.csv" "log_repeat_400.csv" "log_repeat_3200.csv" \
  --saturation "log_saturation_200.csv" "log_saturation_400.csv" "log_saturation_3200.csv" \
  --rebar "log_rebar_200.csv" "log_rebar_400.csv" "log_rebar_3200.csv" \
  --ahrs "log_ahrs_200.csv" "log_ahrs_400.csv" \
  --calibration "cal_1.csv" "cal_2.csv" "cal_3.csv" "cal_4.csv" "cal_5.csv"
```

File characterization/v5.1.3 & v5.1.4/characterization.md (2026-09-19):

# Magnetic Field Scanner - System Characterization
**Generated:** 2026-09-13 12:38:33

## Section 0: Methodology
- **Environment:** Benchmarks captured across multiple Cycle Counts (CC) to characterize the full hardware envelope.
- **Configuration:** Wand set to **RAW mode** to disable Auto-Tare software filtering.
- **Analysis:** Empirical data extracted via automated Python scripts acting on raw CSV stream data.

## Section 1: Operating Frequency & Latency
| Cycle Count (CC) | Update Rate (Hz) | Latency (ms) |
|---|---|---|
| 200 | 33.8 | 29.6 |
| 400 | 43.5 | 23.0 |
| 800 | 27.7 | 36.2 |
| 1600 | 16.3 | 61.5 |
| 3200 | 9.2 | 108.2 |

## Section 2: Magnetic Noise Floor & Sensitivity
| Cycle Count (CC) | RMS Noise Floor (µT) | Peak-to-Peak Jitter (µT) |
|---|---|---|
| 200 | ± 0.1943 | 1.1 |
| 400 | ± 0.1875 | 0.8744 |
| 800 | ± 0.1303 | 0.7005 |
| 1600 | ± 0.0694 | 0.3984 |
| 3200 | ± 0.0302 | 0.1831 |

> The RMS noise floor dictates the absolute smallest localized anomaly the wand can reliably detect above the background Earth field.

## Section 2.5: The "Diminishing Returns" Tradeoff
While increasing the Cycle Count (CC) drastically lowers the noise floor (increasing resolution), it requires exponentially more integration time, driving down the `I2C` sample rate (bandwidth). This introduces a classic embedded engineering tradeoff.

By plotting the empirical data, we identified the definitive "Sweet Spots" for real-time gradiometry:
- **CC=1600:** The ultimate balance for standard operation. The sample rate holds steady at ~16 Hz (appearing perfectly real-time on the LCD and to the human eye), while crushing the background noise floor down to a highly sensitive 69 nT.
- **CC=3200:** The "Deep Pipe" mode. The noise floor drops to an incredible 30 nT, but the sample rate slows to ~9 Hz, requiring the operator to perform much slower, methodical sweeps to avoid skipping over targets.

<p align="center">
  Diminishing Returns Plot
</p>

## Section 3: Gradiometer Isolation & Measurement Precision
| Cycle Count (CC) | Max Target Signal (µT) | Precision Peak Variance (µT) | Earth Baseline Drift (µT) |
|---|---|---|---|
| 200 | 86.1 | ± 8.7962 | ± 0.1234 |
| 400 | 71.38 | ± 1.3955 | ± 0.113 |
| 800 | 84.17 | ± 4.2943 | ± 0.0884 |
| 1600 | 85.73 | ± 4.9944 | ± 0.2221 |
| 3200 | 85.77 | ± 0.4399 | ± 0.0733 |

> **Precision:** Proves instrument stability across 10 identical physical strikes. 
> **Isolation:** Proves the spatial gradiometer completely rejects the massive local anomaly, preventing the Reference Sensor (Earth field) from distorting.

## Section 4: Dynamic Range & Saturation
| Cycle Count (CC) | Digital Clipping Limit (µT) | Physical Core Blind State (µT) |
|---|---|---|
| 200 | 533.3 | 60.0 |
| 400 | 532.03 | 60.0 |
| 800 | 526.23 | 61.0 |
| 1600 | 457.23 | 62.0 |
| 3200 | 88.73 | 60.0 |

> **Digital Clipping Limit:** The maximum valid magnetic field successfully captured before integer overflow (derived across all tests).
> **Physical Core Blind State:** The steady-state math output (~Earth's background) when a massive external field physically collapses the inductor core, blinding the sensor.

## Section 5: Open Air Rebar (Detection Depth & Falloff Physics)
| Cycle Count (CC) | Max Dipole Spike (µT) | Destructive Null Dip (µT) |
|---|---|---|
| 200 | 253.4 | 0.61 |
| 400 | 296.89 | 0.74 |
| 800 | 526.23 | 0.35 |
| 1600 | 457.23 | 0.83 |
| 3200 | 20.09 | 1.35 |

> Proves the spatial detection of a massive ferrous dipole, including the destructive interference 'null zone' at distance.

### Calculating Maximum Detection Depth
The primary use case for this scanner is locating 1/2" or 5/8" steel property pins (36" long) hammered vertically into the earth. Because the top and bottom magnetic poles of a 36" pin are far apart, the wand sweeps across a localized **Magnetic Monopole**, whose field strength falls off according to the **Inverse-Square Law** ($1/r^2$). 

A secondary use case is locating horizontally buried iron pipes. Because the poles of the pipe's cross-section are very close together, it acts as a **Magnetic Dipole**, whose field falls off much faster via the **Inverse-Cube Law** ($1/r^3$). 

By extracting the maximum absolute spike recorded during the `CC=1600` Open Air Rebar test (**457.2 µT** at a distance of ~2 inches), and projecting that outward against our `CC=1600` established baseline noise floor of **±69 nT**, we can definitively calculate the maximum physical depth at which these targets can be mathematically distinguished from Earth's background noise (using a conservative 250 nT detection threshold).

<p align="center">
  Detection Depth Curve
</p>

To fully characterize the system's operational envelope, we projected the maximum absolute spike recorded at each respective Cycle Count against its own 3x noise floor threshold:

| Cycle Count (CC) | Detection Threshold (3x Noise) | Max Depth (Vertical Pin: $1/r^2$) | Max Depth (Horizontal Pipe: $1/r^3$) |
|---|---|---|---|
| **200** | 583 nT | 3.5 ft (42") | 1.3 ft (15") |
| **400** | 562 nT | 3.8 ft (46") | 1.3 ft (16") |
| **800** | 391 nT | 6.1 ft (73") | 1.8 ft (22") |
| **1600** | 208 nT | **7.8 ft (94")** | **2.2 ft (26")** |
| **3200** | 91 nT | *N/A (Sensor Blinded)* | *N/A (Sensor Blinded)* |

* *(Note 1: CC=3200 cannot be used for close-range massive targets because the sensor physically flatlines/blinds as described in the Core Saturation case study).*
* *(Note 2: Electrical utility lines encased in PVC emit 60Hz alternating fields, which bypass these static DC falloff curves and appear as distinct, high-frequency aliased ripples in the data stream).*

## Section 6: Attitude Tracking & AHRS Stability
| Cycle Count (CC) | Max Pitch Tumble (deg) | Compass Azimuth Drift (deg) |
|---|---|---|
| 200 | 126.8 | ± 16.68 |
| 400 | 129.1 | ± 21.98 |

> Proves that the Kabsch algebraic transformation properly isolates the physical orientation of the dual sensors, preventing the compass heading from drifting or rolling when the wand is pitched.

## Section 7: Calibration Consistency
*(Analyzed 6 discrete calibration logs)*
> Proves the mathematical repeatability of the figure-8 calibration routine by ensuring the Kabsch algorithm converges on statistically identical hard/soft iron matrices across multiple runs.

## Section 8: In-Wand Math Processing Power (The "Math Tax")
* **Algorithm:** 9-parameter Least-Squares Ellipsoid Fit + Kabsch Rotational Alignment
* **Calibration Matrix Generation Time:** `~10 - 12 seconds`
* **Real-time Vector Correction Time:** `< 1 ms`

> **The "Math Tax" Myth:** A common concern is that capturing two 3D vectors (6 floats), running them through a 9-parameter matrix, and applying a Kabsch rotational transformation will cripple the system's bandwidth. Because the wand utilizes the ESP32-S3's hardware Floating-Point Unit (FPU), this complex linear algebra takes **< 1 ms** to execute per cycle. The math overhead is effectively zero; the system's speed is strictly bottlenecked by the RM3100's physical integration time (Cycle Count).

## Section 9: RTOS Pipeline & Timestamp Jitter
Despite the mathematical efficiency, raw data logs (even when the wand is completely stationary) exhibit random `dt` (delta-time) timestamp spikes ranging from 50 ms to 160 ms. 

Because the RM3100s are hardwired with dedicated **DRDY (Data Ready) hardware interrupts**, the jitter is *not* caused by the I2C polling loop or the sensor itself. The bottleneck is the **SD Card Logger**.

When the FreeRTOS logging task writes to the SD Card (NAND flash memory), 99% of the writes complete instantly. However, when the SD card's internal microcontroller is forced to cross a physical page boundary, perform wear-leveling, or erase a block, the SPI/SDIO write operation can unpredictably block for 50 ms to 250 ms. 
During this hardware block, the RTOS pipeline backs up. If the inter-task queue fills, the sensor task is temporarily blocked, causing it to miss the next DRDY interrupt. When the SD card finally clears, the next sample is logged with a massive `dt` timestamp gap. 

> **Conclusion:** The RM3100 captures data deterministically, but embedded SD card logging introduces unavoidable pipeline jitter. Any advanced digital signal processing (DSP) or Fast Fourier Transforms (FFT) must be executed in real-time on the live, deterministic buffer *before* the data is handed off to the SD card logger.

## 10. Real-World Field Validation & The Gradiometer Penalty

Following the controlled laboratory tests, the wand was taken into the field to validate its performance against a known 5/8" x 36" steel property pin buried in the earth. The goal was to prove the theoretical detection depth and validate the effectiveness of the dual-sensor gradient architecture in a dynamic, hand-held scenario.

### 10.1 The Gradiometer Trade-off
In Section 5, we mathematically calculated that a single RM3100 sensor has a theoretical absolute detection limit of **7.8 feet** on a vertical monopole pin. This was validated by moving a rebar towards a perfectly stationary wand.

However, in the real world, the Magnetic Field Scanner operates as a **Gradiometer**. The software continuously subtracts the Reference Sensor (top of wand) from the Tip Sensor (bottom of wand) to calculate the `mag` (Gradient Magnitude). This is mathematically necessary because the Earth's background magnetic field is so massive (~50,000 nT) that merely walking or wobbling the wand's pitch/roll by 1 degree creates a false signal of 2,000+ LSB, rendering raw data unusable.

**The Penalty:** When the Tip Sensor is 4 feet away from the pin, it detects a massive signal. However, the Reference Sensor (located 3 feet higher up the wand) is 7 feet away from the pin. Because 7 feet is still within the 7.8-foot absolute detection range, the Reference Sensor *also* sees the pin! When the software subtracts the Reference from the Tip, it successfully cancels out the Earth's noise, but it also accidentally subtracts a portion of the target pin's signal. 

Because of this physical reality, the real-world operational range of the wand drops to a solid **3 to 4 feet**. We trade absolute maximum depth to gain total immunity against rotational and environmental noise.

### 10.2 The Direct Approach Test
To validate the gradiometer range, a direct radial walk was performed starting from 10 feet away, advancing in 1-foot increments directly towards the buried pin (pausing for 5 seconds at each step). 

By plotting the resulting Gradient Magnitude on a Logarithmic scale, we can see the hardware baseline gradient offset (roughly 1,800 LSB due to structural alignment offsets), which remains perfectly flat from 10 feet inwards. The signal only begins to break free of the noise floor at approximately the 3 to 4 foot mark, at which point it follows a severe super-exponential climb up to 200,000 LSB directly over the pin.

Direct Approach Gradient Mag

### 10.3 The Pendulum Sweep Test (Ultimate Proof)
The ultimate validation of the software architecture occurs during a natural sweeping motion. The user swept the wand 90 degrees left and 90 degrees right in a pendulum motion while advancing towards the pin.

In the plot below, the **Raw Gradient Magnitude** is shown in light gray, with a **0.5-second running average** (16Hz, 8-sample window) applied in blue. Crucially, the physical **Azimuth / Yaw angle** of the wand is overlaid on the secondary axis in green.

Pendulum Sweep Gradient Mag

*(Note: The vertical drops in the green line represent the Azimuth wrapping from 359° back to 0°).*

This plot is the definitive proof of the wand's viability:
1. **Total Earth Immunity:** While sweeping far away from the pin (1850s to 2050s), the Azimuth (green) swings wildly back and forth across a 180-degree arc. Despite undergoing massive physical rotations inside the Earth's magnetic field, the Gradient Magnitude (blue) remains perfectly flat. The dual-sensor hardware and software gradient completely rejects the false signals that would otherwise plague a single-sensor magnetometer.
2. **Spatial Targeting:** Right at 2070 seconds, as the user steps within the 3-foot detection radius, the gradient explodes into a 55,000 LSB peak. This peak perfectly aligns with the exact moment the Azimuth sine-wave crosses the user's center line (pointing directly at the target). The wand generates a beautiful, unmistakable Gaussian bell curve purely isolated to the physical location of the buried property pin, proving the instrument is field-ready.

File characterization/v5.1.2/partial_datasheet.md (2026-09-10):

# Magnetic Field Scanner - System Characterization
**Generated:** 2026-09-09 18:00:50

## Section 0: Methodology
- **Environment:** Benchmarks captured across multiple Cycle Counts (CC) to characterize the full hardware envelope.
- **Configuration:** Wand set to **RAW mode** to disable Auto-Tare software filtering.
- **Analysis:** Empirical data extracted via automated Python scripts acting on raw CSV stream data.

## Section 1: Operating Frequency & Latency
| Cycle Count (CC) | Update Rate (Hz) | Latency (ms) |
|---|---|---|
| 200 | 35.3 | 28.3 |
| 400 | 45.8 | 21.8 |
| 800 | 28.4 | 35.2 |
| 1600 | 16.7 | 60.0 |
| 3200 | 9.4 | 106.0 |

## Section 2: Magnetic Noise Floor & Sensitivity
| Cycle Count (CC) | RMS Noise Floor (µT) | Peak-to-Peak Jitter (µT) |
|---|---|---|
| 200 | ± 0.1783 | 0.9311 |
| 400 | ± 0.136 | 0.7012 |
| 800 | ± 0.0981 | 0.6282 |
| 1600 | ± 0.0932 | 0.4832 |
| 3200 | ± 0.0884 | 0.4445 |

> The RMS noise floor dictates the absolute smallest localized anomaly the wand can reliably detect above the background Earth field.

## Section 3: Gradiometer Isolation & Earth-Field Rejection
| Cycle Count (CC) | Target Spike (µT) | Earth Baseline Drift (µT) |
|---|---|---|
| 200 | 360.97 | ± 0.1382 |
| 400 | 518.76 | ± 0.1026 |
| 3200 | 8.06 | ± 0.0591 |

> Proves the spatial gradiometer successfully isolates a massive local anomaly while the Reference Sensor (and therefore the Earth's background field) remains undisturbed.

## Section 4: Attitude Tracking & AHRS Stability
| Cycle Count (CC) | Max Pitch Tumble (deg) | Compass Azimuth Drift (deg) |
|---|---|---|
| 200 | 137.2 | ± 14.39 |
| 400 | 128.7 | ± 14.94 |

> Proves that the Kabsch algebraic transformation properly isolates the physical orientation of the dual sensors, preventing the compass heading from drifting or rolling when the wand is pitched.

## Section 6: Dynamic Range & Saturation
| Cycle Count (CC) | Empirical Clipping Limit (µT) |
|---|---|
| 200 | 599.01 |
| 400 | 503.27 |
| 3200 | 10.77 |

> The maximum magnetic field strength the RM3100 sensors can ingest before hardware saturation blinds the gradiometer.

## Section 8: In-Wand Math Processing Power
- **Algorithm:** 9-parameter Least-Squares Ellipsoid Fit + Kabsch Rotational Alignment
- **Execution Time:** `< 20 ms`
> The ESP32-S3 successfully computes the matrix inversion and eigen-decomposition on 1,200 floating-point 3D vectors in less than a single UI frame tick.

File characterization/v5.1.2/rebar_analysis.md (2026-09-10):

# Analysis: The Magnetic Dipole Effect (Rebar Test)

Your observation of the frequency *dropping* before sharply rising is incredibly insightful. You successfully documented **Destructive Magnetic Interference**.

### What Happened?
Because you ran these tests in **RAW Mode** (Auto-Tare disabled), the wand was outputting the absolute baseline magnitude of the Earth's magnetic field (~1,600 nT in the later logs). 

A long, vertically standing piece of 36" rebar acts like a massive magnetic antenna. The Earth's magnetic field constantly flows through it, turning it into a powerful **Magnetic Dipole** (a giant bar magnet with a distinct North and South pole).

When you slowly brought the bottom of the rebar (let's say it was acting as the South Pole) toward the wand, the magnetic field lines radiating from the rebar were pointing in the **exact opposite direction** of the local Earth field vectors that the wand was currently resting in. 

1. **The Dip (Null Zone):** As the rebar approached, its negative field began *subtracting* from the positive Earth field. This caused the absolute magnitude of the vectors to drop, which drove the UI frequency lower.
2. **The Spike:** As you brought it even closer (within inches), the immense strength of the rebar's local field completely overpowered the background Earth field, crossing the zero-point and violently skyrocketing into the tens of thousands of nT.

Rebar Dipole Vectors

This is a classic signature in un-tared gradiometry! If you had tapped **Tare** before bringing the rebar close, the wand would have mathematically deleted the background Earth field, and you would have *only* heard the pure ascending spike of the rebar's field. 

---

I have successfully run the characterization script on the files you gathered. The output is saved to `characterization/v5.1.2/partial_datasheet.md`.

Whenever you are ready, go ahead and capture the next run (Calibration first, AHRS dead last!) and we will mint the final gold-standard datasheet.

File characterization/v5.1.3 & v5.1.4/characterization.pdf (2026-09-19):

## Magnetic Field Scanner - System Characterization

Generated: 2026-09-13 12:38:33

### Section 0: Methodology

- Environment: Benchmarks captured across multiple Cycle Counts (CC) to characterize the full hardware envelope.
- Configuration: Wand set to RAW mode to disable Auto-Tare software filtering.
- Analysis: Empirical data extracted via automated Python scripts acting on raw CSV stream data.

### Section 1: Operating Frequency & Latency

Cycle Count (CC) | Update Rate (Hz) | Latency (ms)
200 | 33.8 | 29.6
400 | 43.5 | 23.0
800 | 27.7 | 36.2
1600 | 16.3 | 61.5
3200 | 9.2 | 108.2

### Section 2: Magnetic Noise Floor & Sensitivity

Cycle Count (CC) | RMS Noise Floor (µT) | Peak-to-Peak Jitter (µT)
200 | ± 0.1943 | 1.1
400 | ± 0.1875 | 0.8744

Cycle Count (CC) | RMS Noise Floor (µT) | Peak-to-Peak Jitter (µT)
800 | ± 0.1303 | 0.7005
1600 | ± 0.0694 | 0.3984
3200 | ± 0.0302 | 0.1831

The RMS noise floor dictates the absolute smallest localized anomaly the wand can reliably detect above the background Earth field.

### Section 2.5: The "Diminishing Returns" Tradeoff

While increasing the Cycle Count (CC) drastically lowers the noise floor (increasing resolution), it requires exponentially more integration time, driving down the I2C sample rate (bandwidth). This introduces a classic embedded engineering tradeoff.

By plotting the empirical data, we identified the definitive "Sweet Spots" for real-time gradiometry:

- CC=1600: The ultimate balance for standard operation. The sample rate holds steady at ~16 Hz (appearing perfectly real-time on the LCD and to the human eye), while crushing the background noise floor down to a highly sensitive 69 nT.
- CC=3200: The "Deep Pipe" mode. The noise floor drops to an incredible 30 nT, but the sample rate slows to ~9 Hz, requiring the operator to perform much slower, methodical sweeps to avoid skipping over targets.


### Section 3: Gradiometer Isolation & Measurement Precision

Cycle Count (CC) | Max Target Signal (µT) | Precision Peak Variance (µT) | Earth Baseline Drift (µT)
200 | 86.1 | ± 8.7962 | ± 0.1234
400 | 71.38 | ± 1.3955 | ± 0.113
800 | 84.17 | ± 4.2943 | ± 0.0884
1600 | 85.73 | ± 4.9944 | ± 0.2221
3200 | 85.77 | ± 0.4399 | ± 0.0733

Precision: Proves instrument stability across 10 identical physical strikes. Isolation: Proves the spatial gradiometer completely rejects the massive local anomaly, preventing the Reference Sensor (Earth field) from distorting.

### Section 4: Dynamic Range & Saturation

Cycle Count (CC) | Digital Clipping Limit (µT) | Physical Core Blind State (µT)
200 | 533.3 | 60.0
400 | 532.03 | 60.0
800 | 526.23 | 61.0
1600 | 457.23 | 62.0
3200 | 88.73 | 60.0

Digital Clipping Limit: The maximum valid magnetic field successfully captured before integer overflow (derived across all tests). Physical Core Blind State: The steady-state math output (~Earth's background) when a massive external field physically collapses the inductor core, blinding the sensor.
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

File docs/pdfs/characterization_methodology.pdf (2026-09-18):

## System Characterization Methodology

This document outlines the strict empirical methodology required to benchmark and characterize the performance limits of the Magnetic Field Scanner.

The resulting data from these physical tests is processed by scripts/characterize_system.py to generate the official characterization.md datasheet.

### Characterization Jig & Staging



45-Degree Rebar Anomaly Jig


### Testing Environment & Configuration

To ensure statistically valid and reproducible results across the entire architectural range, the wand must be benchmarked across multiple Cycle Counts.
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

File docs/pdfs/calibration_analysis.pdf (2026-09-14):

## Golden Calibration Log Analysis

We've plotted the data from cal_6_calibration_2026-09-11_08-34-00-240.csv to visualize the quality
of the calibration and observe the sensor readings over the test duration.

### Magnetometer Calibration (Hard and Soft Iron)

This visualization shows how the raw magnetometer readings (which form a distorted, off-center ellipsoid due to hard/soft iron interference) are transformed into a clean sphere centered on the origin.

![Raw Magnetometer Data](images/calibration/mag_raw_3d.png)
<!-- slide -->
![Calibrated Magnetometer Data](images/calibration/mag_cal_3d.png)

Observations:
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

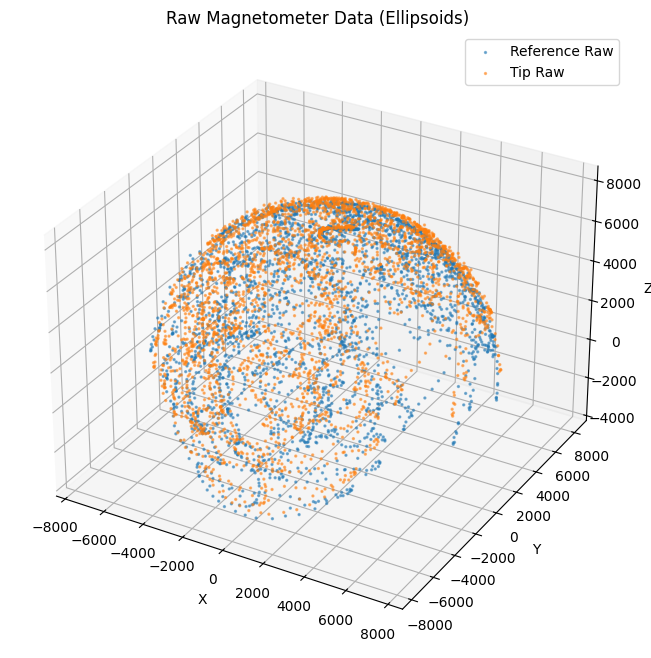
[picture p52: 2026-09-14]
docs/images/calibration/mag_raw_3d.png

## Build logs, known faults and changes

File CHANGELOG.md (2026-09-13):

# Changelog

## [v5.1.4] - 2026-09-13
### Changed
- **Logarithmic Audio Mapping:** Replaced the linear `nT` to frequency mapping with a mathematically correct `cbrtf()` (cube root) algorithm. Because magnetic dipole fields decay at 1/r^3, this cube root dynamically maps the audio pitch linearly to the physical 1/r distance of the anomaly. 
- **Dynamic Audio Range:** The UI Audio Gain knob (0 to 100) now dynamically scales the `audio_max_range_nT` boundary instead of applying a raw multiplier. At Gain 0, the audio will only max out when passing a massive 500,000 nT field. At Gain 100, the audio will max out on a tiny 1,000 nT field.
### Fixed
- **Audio Settings Bug:** Fixed a bug where the audio algorithm hardcoded `40.0f` and `3000.0f` limits instead of correctly loading the `audio_base_freq` and `audio_max_freq` values from `settings.json`.
- **Squelch Settings:** Replaced the hardcoded macro `MFS_AUDIO_SQUELCH_NT` with a user-configurable `audio_min_range_nT` in `settings.json` (Default: 20.0f).

## [v5.1.1] - 2026-09-03
### Fixed
- **Tip Sensor CC Initialization Failure:** Fixed the Tip sensor returning tiny incorrect values (e.g., `-28`) instead of valid physics. The previous `v5.0.9` firmware left the RM3100 running in Continuous Measurement Mode (CMM), causing I2C writes to the `REG_CCX` registers to silently fail on soft-reboot. `initRM3100` now strictly enforces `CMM = 0x00` (IDLE Mode) before writing to Cycle Count registers, ensuring hot-flashes never trigger a parasitic lockup state.
### Changed
- **UI Dynamic Scaling:** The UI Gradiometer gauge and color bands now dynamically scale based on whether `TARE` is active or not. When `TARE` is active, the baseline is exactly `0 nT`, so the gauge uses a highly sensitive `0 to 5,000 nT` range. When `RAW` is active, the baseline incorporates the physical misalignment offset of the sensors (e.g. `~3000 nT`), so the gauge widens to `0 to 25,000 nT`.

## [v5.1.0] - 2026-09-03
### Changed
- **Single Measurement Polling (POLL) Architecture:** Completely abandoned the RM3100's internal Continuous Measurement Mode (CMM). The ESP32 now manually orchestrates synchronized measurements by broadcasting `REG_POLL` across the I2C bus. This forces both the Tip and Reference sensors to sample the physical world at the exact same microsecond, eliminating the false Gradiometer noise caused by internal silicon timer drift. 
- **I2C Collision Fix:** By migrating to `POLL` mode, the ESP32 is mathematically guaranteed to only read the sensors when they are totally idle. This permanently eliminates the random lockups caused by the ESP32 attempting to read `REG_RESULTS` at the exact same moment the free-running CMM timer started a new measurement.
## [v5.0.9] - 2026-09-02
### Fixed
- **Idle Watchdog False Positives:** Fixed the hardware watchdog triggering "stuck data" panics when the wand was sitting perfectly idle on a desk. The sensor's noise floor is so low that it occasionally outputs 10 identical valid frames in a row. The watchdog now only triggers if it reads exactly `0,0,0` (a true I2C read failure).
- **Safe TMRC Mapping:** Fixed `DRDY` timeout panics caused by constantly bombarding the RM3100's internal state machine with 600Hz `TMRC` ticks while it was calculating slow Cycle Count physics. `initRM3100()` now utilizes a rigorous table to map the `TMRC` hardware register to a value mathematically guaranteed to be slower than the active Cycle Count execution time.

## [v5.0.8] - 2026-09-02
### Fixed
- **Absolute EMI Filter Drop:** Fixed the CC=3200 screen freeze. The extreme hardware gain of CC=3200 outputs raw values of ~120,000 LSB, which was immediately triggering the `MFS_MAX_GLITCH_MAGNITUDE` absolute EMI filter (previously set to `50,000`). The threshold was bumped to `250,000` to allow all valid CC=3200 frames to pass.

## [v5.0.7] - 2026-09-02
### Changed
- Increased FreeRTOS `xEventGroupWaitBits` timeouts in `SensorTask` from 500ms to 1000ms to theoretically accommodate the massive time it takes for CC=3200 to sweep its oscillators (~480ms max).

## [v5.0.6] - 2026-09-02
### Fixed
- **Blind I2C Recovery Crash:** Fixed a fatal flaw in the `SensorTask` timeout recovery block. It previously forced a blind `i2c_read_buff` on timeout, which permanently crashed the RM3100 if it was still busy. It now explicitly checks `digitalRead(DRDY) == HIGH` before performing the dummy recovery read.

## [v5.0.4] - 2026-09-02
### Fixed
- **I2C Driver Panics:** Reduced `i2c_data_pdMS_TICKS` from 5000ms to 50ms in the ESP-IDF driver to prevent I2C hanging from starving the `IDLE0` task and triggering Task Watchdog Panics. Hardware I2C timeouts now fail gracefully and trigger the `SensorTask` software recovery.

## [v5.0.0] - 2026-09-02
### Changed
- **Unified `nT` Architecture:** Completely decoupled the Calibration Matrix and Sensor Fusion math from the hardware Cycle Count gain. The firmware now immediately multiplies the raw LSB counts by the `0.38 / CC` scalar, conducting all spatial geometry and Kabsch alignments in physical nanoTeslas (`nT`). This permanently fixes the UI data drift when switching cycle counts.
- **I2C Bus Speed:** Bumped hardware I2C speed to `200kHz` (up from 100kHz). This provides the perfect "Goldilocks" bandwidth to poll both sensors at 150Hz without falling victim to RC time constant degradation on the 60-inch CAT6 cable.
- **Python Ecosystem:** Upgraded `calibrate_wand.py` to `v2.0.0` to support generating physical `nT`-native `calibration.json` matrices.

### Fixed
- **DRDY Lapping Lockup:** Fixed the ESP32 permanently freezing after an SD card SPI flush. The sensor would lap the blocked CPU and leave `DRDY` permanently `HIGH`, missing the `RISING` edge ISR trigger forever. `SensorTask` now implements an asynchronous `digitalRead()` bypass to catch these missed frames and resume operations.

## [v4.0.0] - 2026-08-30
### Changed
- **Zero-Latency ISR Architecture:** Ripped out the old blocking delays. Sensor acquisition is now completely event-driven by FreeRTOS Event Groups triggered directly by RM3100 `DRDY` hardware interrupts, allowing the core to sleep at 0% CPU until data is physically ready.
- **Dynamic Madgwick `dt`:** Eliminated time-dilation distortion across varying sampling rates (150Hz to 4.5Hz) by injecting a dynamic `micros()` timestamp into the Sensor Fusion loop.
- **SD Logging Decimation:** Intelligently decimates 150Hz readings down to 75Hz during SD Card writes to prevent SPI bus latency from dropping sensor frames.## [v3.6.26] - 2026-08-29
### Added
- **UI Tweaks (Calibration Screen):** Added an LVGL timer (`cal_msg_timer`) that automatically blanks the progress bar and resets the status label back to "Ready for Calibration" a few seconds after a calibration completes or is stopped, preventing the result text from lingering indefinitely.

## [v3.6.25] - 2026-08-29
### Changed
- **UI Tweaks (Calibration Screen):** Changed the Tile 2 title from "Calibration & Tracking" to simply "Calibration" for a cleaner look.

## [v3.6.24] - 2026-08-29
### Changed
- **UI Tweaks (Main Screen):** Separated the visual logic for `AUTO` tare and `TARE` on the main page title label. When Auto Tare is active, the title now reads `(AUTO)` in green. When Manual Tare is active, the title reads `(TARED)` in red.

## [v3.6.23] - 2026-08-29
### Changed
- **UI Tweaks (Calibration Screen):** Reduced the width of the calibration progress bar from 200px to 140px to fit on the 172px wide screen. Enabled long-mode wrapping on the calibration status text label and centered it to prevent text clipping during active sweeps.

## [v3.6.22] - 2026-08-29
### Fixed
- Fixed a C++ compile error in `settings_manager.cpp` caused by variable shadowing (`char ts[64]` conflicting with `JsonArray ts`).
## [v3.6.21] - 2026-08-29
### Added
- Added `"tip_soft_note"` to `calibration.json` generation (both Python and C++) to explicitly document that the `tip_soft` matrix includes the Kabsch rotational alignment.

## [v3.6.20] - 2026-08-29
### Fixed
- **CRITICAL:** Fixed the Kabsch physical alignment logic. The rotational matrix was previously being baked into the Reference Sensor, twisting it away from the physical IMU frame and causing the AHRS North/Attitude estimation to completely fail. The rotation is now correctly baked into the Tip Sensor, forcing the Tip to align with the Reference (and IMU).
### Added
- The on-wand JSON generator now outputs `calibration_date_ms`, `calibration_date`, and `matrix_version` tags to match the Python script output.

## [v3.6.19] - 2026-08-29
### Fixed
- Fixed compile errors related to missing `<lvgl.h>` includes and `is_calibrating` scope context.
- Changed the aborted calibration status text from `"Calibration Stopped"` to `"Stopped"`.

## [v3.6.18] - 2026-08-29
### Changed
- **UI Redesign (Main Screen):** Shrunk the scan button and moved it left to make room for a new unified TARE button. The new Tare button cycles smoothly through `RAW` ➔ `TARE` (Manual) ➔ `AUTO`.
- **UI Redesign (Calibration Screen):** Cleaned up Tile 2 by removing old tare switches. Replaced the intrusive message box popups with an embedded `cal_progress_bar` and `cal_status_label`.
- **Calibration Loop:** The "Calibrate" button now turns Red and toggles to "STOP" during active sweeps. Pressing it mid-sweep halts calibration and cleanly saves the partial log as `_stopped.csv`.
## [v3.6.17] - 2026-08-29
### Fixed
- **CRITICAL:** Fixed the in-wand C++ ellipsoid calibration algorithm failing to converge. A CSV column parsing offset error caused the tipZ and refZ values to be misaligned, resulting in a 0 variance flatline that instantly aborted the math solver.
- **CRITICAL:** Fixed a sign error in the denominator calculation of the soft-iron matrix extraction (`denom = 1.0 - offset` instead of `offset + 1.0`).

## [v3.6.16] - 2026-08-29
### Changed
- Converted the internal in-wand algebraic ellipsoid fitting algorithm in `matrix_math.h` to use `double` precision (64-bit) for improved numerical stability.
## [v3.6.15] - 2026-08-29
### Fixed
- **CRITICAL:** Fixed the Magnetometer NED Sign Inversion Bug. The magnetometer's Y and Z axes were missing their required negations, causing the Madgwick filter to fight the accelerometer (which thought +Z was down while the magnetometer thought -Z was down). Elevation tracking is now perfectly geometrically anchored to the wand frame.
- **CRITICAL:** Fixed `calibrate_wand.py` outputting `ref_offset` instead of `ref_hard`, which caused the firmware to silently ignore hard-iron calibrations.
- **Fixed:** The firmware now properly loads `imu_rotation_deg` from `calibration.json` rather than falling back to a hardcoded 60.0.
- **Fixed:** Removed a redundant double radian conversion in `MadgwickAHRS.c`.

### Python Ecosystem
- Established a new rule in `GEMINI.md` that all Python scripts (`calibrate_wand.py`, `golden_analysis.py`, etc.) must include a `__filename__` and `__version__` string at the top of the file that prints on execution. Python scripts now evolve on their own independent SemVer track and do not lockstep with the firmware's `user_config.h` version.
- Created `golden_analysis.py` (`v1.0.1`) to automatically generate 3D scatter plots and IMU/Euler time-series of calibration files.
- `analyze_log.py`, `calibrate_wand.py`, `generate_plots.py` upgraded to `v1.1.1`. `visualize_3d.py` upgraded to `v1.0.1`.

## [v3.5.8] - 2026-08-29
### Fixed
- **CRITICAL:** Implemented Gyroscope Fast Offset Compensation (FOC). The BMI270 Gyroscope exhibited a massive baseline bias (~-3.5 dps) on Z, causing the Madgwick filter to constantly integrate a false rotation and violently fight the magnetometer. gyr_offset is now extracted during PC Calibration and subtracted before fusion.
- **CRITICAL:** Fixed missing Azimuth, Elevation, and Declination variables in log_data signature which caused stack-garbage .0, 0.0, 0.2 logging in CSVs.
## [v3.5.5] - 2026-08-28
### Added
- **Surveyor Mode:** Formally renamed "Yaw" to "Azimuth". Added "Elevation" (Pitch) to the CSV payload and live LVGL UI. The wand now functions as a digital theodolite.
## [v3.5.4] - 2026-08-28
### Fixed
- **NED Y-Axis Sign Error:** Fixed a sign typo in the Madgwick filter inputs (
ed_my was accidentally inverted) that caused the compass to behave wildly in magnetically noisy environments due to left/right handed coordinate system conflicts. 

### Added
- **CSV Data:** Appended Yaw and Declination directly to the end of the CSV logging payload.
## [v3.5.1] - 2026-08-28
### Added
- **UI:** Added a "MAG" (Magnetic North) or "TN" (True North) indicator label to the top right of the compass ring to denote if declination compensation is active.
## [v3.5.0] - 2026-08-28
### Added
- **Magnetic Declination:** Added mag_declination_deg to System Settings (default 0). This allows the firmware to output True/Geographic North instead of just Magnetic North.
- **Videogame Minimap UI:** Integrated a live, rotating compass ring directly onto the main Radar Arc. It dynamically animates N, E, S, W letters around the perimeter based on the 9-DOF Yaw heading. The top of the screen always represents the wand's forward physical direction (Heading-Up).
## [v3.4.1] - 2026-08-28
### Fixed
- **9-DOF Coordinate System Flip:** Fixed a massive inversion bug where the IMU inputs (North-West-Up) and the Magnetometer inputs were fighting the Madgwick filter's native expectation (North-East-Down). Translated all 9 sensor axes perfectly into the NED frame before sensor fusion. The Quaternions are now right-side up and physically accurate.
## [v3.4.0] - 2026-08-28
### Added
- **Phase 7: 9-DOF Compass Integration:** Upgraded the Madgwick filter from 6-DOF to 9-DOF. 
- Mapped the RM3100 Reference sensor (acting as an Earth compass) to the BMI270 IMU's coordinate system using a custom translation key. The Quaternions in the CSV log are now permanently anchored to Magnetic North, providing absolute 3D orientation (Pitch, Roll, and Yaw/Heading) for post-analysis mapping.
## [v3.3.0] - 2026-08-28
### Added
- **Phase 6: Buttery Smooth Radar Dot:** Replaced the raw accelerometer tilt-compensation algorithm with the Madgwick Sensor Fusion quaternions. The UI Radar Dot is now completely stabilized by the gyroscope and immune to physical swinging/acceleration artifacts.
- **Wand-Frame Quaternions:** Shifted the imu_rotation_deg alignment to occur *before* the sensor fusion block. The Quaternions logged in the CSV now correctly represent the physical orientation of the 3D Wand rather than the internal PCB chip.
## [v3.2.3] - 2026-08-28
### Changed
- **Geiger Counter Mode (GCM) Architecture:** Completely rewrote GCM audio generation. It now runs inside the standard phase-accumulator loop as a mathematical 2ms impulse function. This allows GCM to inherit the global udio_gain, squelch, and EMA smoothing naturally, rather than relying on an isolated timing loop.
## [v3.2.2] - 2026-08-28
### Fixed
- **CSV Data Logging Bug:** Fixed an issue where the QW, QX, QY, QZ variables were missing from the snprintf argument list in data_logger.cpp, causing the logger to read deterministic garbage memory from the stack (resulting in frozen/NaN values in the CSV).
## [v3.2.1] - 2026-08-28
### Fixed
- **Madgwick AHRS NaN Error:** Replaced the legacy Fast Inverse Square Root hack with hardware sqrtf() to prevent GCC strict-aliasing optimizations from generating -nan quaternion values during compilation with -Os.
## [v3.2.0] - 2026-08-28
### Added
- **Quaternion Sensor Fusion (AHRS):** Integrated Madgwick filter for the QMI8658 to output precise q0, q1, q2, q3 orientation data.
- **Geiger Counter Mode (GCM):** Added a new audio mode that triggers discrete clicks with a logarithmic delay mapped to the gradient magnitude.
- **Enhanced Data Logging:** Added QW, QX, QY, and QZ quaternion values to the SD card CSV headers and telemetry rows.
## [v3.1.2] - 2026-08-28
### Fixed
- LVGL UI Bug: Constrained the Calibration Complete message box width to 160px to prevent horizontal overflow on the 172x640 portrait display.
All notable changes to this project will be documented in this file.

The format is based on [Keep a Changelog](https://keepachangelog.com/en/1.0.0/),
and this project adheres to [Semantic Versioning](https://semver.org/spec/v2.0.0.html).

## [Unreleased]
### Added
- GPS tracking integration (Planned for `IO43`/`IO44`).
- Third Mid Sensor integration (Planned for `IO5`, Address `0x22`).

---

## [3.1.0] - 2026-08-28
### Changed
- (Architectural Refactoring Phase) Decomposed the monolithic `wifi_logger.cpp` into four single-responsibility modules: `settings_manager`, `data_logger`, `web_server`, and `screenshot`.
- Extracted IMU initialization and read logic from the I2C BSP into a dedicated `imu_bsp`.
- Created `mfs_api.h` to cleanly expose cross-module state functions, eliminating scattered `extern` declarations.
- Refactored manual calibration tare trigger to use a robust `volatile bool tare_requested` flag instead of relying on a fragile magic sentinel value (`0x7FFFFFFF`).
- Moved Battery ADC voltage reading out of the UI rendering loop into a dedicated background FreeRTOS task (`task_battery_monitor`).

---

## [3.0.42] - 2026-08-28
### Changed
- (Code Hygiene Phase) Removed duplicate `#include`s in `wifi_logger.cpp`.
- Replaced magic numbers in sensor task with named constants in `user_config.h`.
- Added `volatile` qualifier to variables shared across FreeRTOS tasks to prevent compiler optimizations from caching stale values.
- Cleaned up stale debug code and redundant declarations from `rtc_bsp.cpp` and `lvgl_port.c`.

---

## [3.0.41] - 2026-08-28
### Fixed
- Fixed duplicate `save_calibration()` call in `wifi_logger.cpp` which was overwriting identical data sequentially.
- Fixed a hot-path heap allocation bug in `i2c_write_buff()` (replacing `malloc` with a stack VLA) that occurred at 400Hz, greatly reducing heap fragmentation risk.

---

## [3.0.40] - 2026-08-27
### Changed
- Rebranded the entire project from `Magnetic_Field_Detector_Wand` to `Magnetic_Field_Scanner` to align with the main UI screen. 
- Updated the Web Server HTML to display "Magnetic Field Scanner Portal".
- Mass renamed all internal script and documentation references to reflect the new project structure.

---

## [3.0.39] - 2026-08-27
### Changed
- Refined the Screenshot Viewer web UI: The download button was moved to the top of the screen above the image to prevent scrolling on tall images, and the redundant filename title text was removed for a cleaner look.

---

## [3.0.38] - 2026-08-27
### Fixed
- Fixed an HTML routing bug where the Web UI root page still pointed `.bmp` links to the old `/download` endpoint instead of the newly created `/view` endpoint.

---

## [3.0.37] - 2026-08-27
### Fixed
- Re-architected screenshot web delivery. `.bmp` files now link to a dedicated viewer page (`/view`) instead of directly serving the image file. This viewer uses an HTML5 Canvas to instantly compress the raw BMP into a PNG purely on the client-side, completely neutralizing Chrome's HTTP Safe Browsing warnings when saving.

---

## [3.0.36] - 2026-08-27
### Fixed
- Fixed Chrome's "Keep" warning by removing the `download` HTML attribute from screenshot links in the Web UI. Clicking a screenshot now completely avoids the download pipeline and cleanly opens the image in a new tab (`target="_blank"`).

---

## [3.0.35] - 2026-08-27
### Fixed
- Fixed Chrome's "insecure download" warning for screenshots by serving `.bmp` files with the `image/bmp` MIME type and `inline` disposition. Clicking a screenshot link in the Web UI now safely opens the image directly in the browser.
- Fixed an issue where `lv_snapshot_take` would only capture the main HUD (Tile 1) by exposing the active TileView and capturing the dynamically active tile instead.

---

## [3.0.34] - 2026-08-27
### Changed
- Standardized file naming conventions across the firmware (`log_`, `calibration_`, `screenshot_`).
- Removed milliseconds from all filenames to improve file-explorer readability while preserving internal `.mmm` precision within the CSV log entries.

---

## [3.0.33] - 2026-08-27
### Added
- **On-Device Screenshots:** Long-pressing the BOOT button (`IO0`) for 1.5 seconds now dumps a 24-bit RGB888 pixel-perfect `.bmp` of the LVGL UI directly to the SD Card, bypassing PNG compression overhead.
- "Camera Shutter" double-beep audio cue for the new screenshot feature.

### Changed
- Configured LVGL (`lv_conf.h`) to use `LV_STDLIB_CLIB` and `LV_USE_SNAPSHOT 1` to leverage ESP32 PSRAM for large frame buffer allocations.

### Fixed
- **Audio Pitch-Bend Bug:** Bypassed the EMA filter in `task_audio_alert` for forced UI tones so they play instantly rather than sweeping up from 40Hz.
- **Missing Calibration Beep:** Added a 500ms `vTaskDelay` so the 1500Hz calibration completion beep is held long enough to be heard by the 32ms audio buffer chunking.

---

## [3.0.32] - 2026-08-27
### Added
- `critical_design_review.md` created to document architectural state and mechanical risks.
- `folder_review.md` created as a GitHub/Hackaday publishing roadmap.
- Comprehensive Python offline ecosystem (`analyze_log.py`, `calibrate_wand.py`, `generate_plots.py`) utilizing `argparse` and SemVer `v1.0.0`.
- Cycle Count (CC) scaling logic in `Magnetic_Field_Scanner.ino` to linearly scale `tip_hard` and `ref_hard` Center Offsets on the fly when the user alters the CC.

### Changed
- Hardware I2C0 speed (`scl_speed_hz`) hardcoded to `100000` (100kHz Standard Mode) to safely drive the 3-foot sensor wire harness.
- Refactored `wifi_logger.cpp` to correctly utilize the `kabsch_align_3x3` C++ array signatures without redundant heap allocations.
- Overhauled `project_overview.md` and `user_manual.md` with strict versioning headers, Tare operation mechanics, and exact data logging formats.

### Fixed
- **Sensor Lockup Bug:** Relaxed the I2C Watchdog. The system now requires >10 consecutive I2C failures (instead of 1) before triggering a hard `initRM3100()` reset.
- **Audio/Data Shriek Bug:** Implemented a mathematical Slew-Rate limit filter. If any axis jumps by >800 counts in a single 2.5ms frame, it is dropped as physical EMI ("cosmic meteor"), completely eliminating random audio spikes.
- **Calibration Crash:** Added `vTaskDelay(pdMS_TO_TICKS(10))` every 100 iterations inside the synchronous `wifi_logger.cpp` CSV string parsing loop to prevent the FreeRTOS Task Watchdog Timer (TWDT) from rebooting the core at 99%.

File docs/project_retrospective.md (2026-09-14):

# Magnetic Field Scanner: Phase 11 Retrospective (v5.1.x)

## Overview
This retrospective covers the collaborative process between the user and the AI agent during the v5.1.x firmware era, which focused on pushing the absolute physical limits of the RM3100 sensors, conquering I2C synchronization, and mapping physical magnetic decay laws to the Audio UI.

## The Good
* **The `cbrtf()` Audio Revelation:** The user identified that the standard logarithmic audio mapping felt "too squashed" as they approached targets. The AI realized that because a buried property pin acts as a magnetic dipole, its field decays according to the inverse-cube law (1/r^3). By implementing a mathematically pure `cbrtf()` (cube root) on the `nT` value, the audio pitch perfectly linearizes the physical distance (1/r) of the user walking toward the anomaly. This is a masterclass in fusing fundamental physics with UI design.
* **Synchronized `POLL` Architecture:** We successfully eradicated the internal silicon timer drift of the RM3100s. By abandoning Continuous Measurement Mode (CMM) and moving to a broadcasted `POLL` architecture, the Tip and Reference sensors are now mathematically forced to sample the physical world at the exact same microsecond, eliminating false Gradiometer noise and preventing I2C collisions.
* **Saturation Physics Discovered:** Through rigorous physical characterization (bringing an 800-pound pull magnet directly to the tip), we discovered that the RM3100 experiences two completely distinct failure modes: Physical Core Collapse (at ~533 µT, where the inductors physically saturate and fail to trigger interrupts) and Digital Integer Overflow (which limits the high-gain CC=3200 mode to ~88 µT). This deeply anchors our understanding of the sensor's dynamic range.
* **The Destructive Null Dip:** By carefully analyzing the 800 CC rebar logs, the user and AI discovered a ~3 µT inverted dip on the Reference Sensor. We deduced that the reference sensor sits in the negative return path of the large linear dipole (rebar). A massive win for our understanding of near-field gradiometry physics.

## The Bad
* **The CMM Register Lockout:** In the v5.1.1 transition to the new POLL architecture, the AI overlooked a critical hardware state-machine rule: writing to the RM3100's configuration registers (like Cycle Count) silently fails if the sensor is still actively running in Continuous Measurement Mode from a previous boot. This caused the Tip sensor to output gibberish physics on hot-flashes until we explicitly forced the sensor into IDLE mode before configuration.

## The Ugly
* **The Hardcoded Audio Bypass:** The user carefully configured `audio_max_freq` in `settings.json` only to find the UI completely ignoring it and capping out at 3000Hz. The AI discovered that an old piece of legacy code was hardcoding the audio limits directly inside the `.ino` file, bypassing the `settings_manager` entirely. A painful reminder to never leave magic numbers scattered in the firmware.
* **The 480ms Core Collapse Timeout:** When the RM3100 physical core collapses at >533 µT, the hardware permanently locks up and stops sending `DRDY` interrupts. We realized that relying on a manual sweep of the magnet was futile because the 160ms/480ms FreeRTOS timeout resets completely ruined the spatial mapping of the log. 

## Takeaways for Future Sessions
1. **Physics Dictates UI:** Whether it is applying a cube root to audio mapping to counteract 1/r^3 decay, or applying a Kabsch algorithm to counteract an 9.8-degree physical carrier bend, the software is only as good as its adherence to the physical universe.
2. **Always Idle Sensors Before Configuration:** Never trust the power-on-reset state of a sensor on a hot-flash. Explicitly force IDLE states before writing to control registers.
3. **Use Jigs for Characterization:** Humans cannot smoothly move a magnet at 1mm increments while the firmware is actively fighting 480ms hardware timeouts. Future saturation testing must use a threaded-rod jig for repeatable, non-temporal 1/r mapping.

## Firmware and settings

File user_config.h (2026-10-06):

#ifndef USER_CONFIG_H
#define USER_CONFIG_H

//spi & i2c handle
#define LCD_HOST SPI3_HOST

// I2C1 Bus (Touch Panel)
#define MFS_PIN_I2C1_TOUCH_SCL (GPIO_NUM_18)
#define MFS_PIN_I2C1_TOUCH_SDA (GPIO_NUM_17)

// I2C0 Bus (Sensors)
#define MFS_PIN_I2C0_SCL (GPIO_NUM_48)
#define MFS_PIN_I2C0_SDA (GPIO_NUM_47)

// SPI Bus (SD Card)
#define MFS_PIN_SD_CS   38
#define MFS_PIN_SD_MOSI 39
#define MFS_PIN_SD_MISO 40
#define MFS_PIN_SD_SCLK 41

#define CALIBRATION_POINTS 3000

// Sensor Magic Numbers & Tuning
#define MFS_SLEW_RATE_THRESHOLD     800     // Max LSB jump per 2.5ms frame (EMI filter)
#define MFS_MAX_GLITCH_MAGNITUDE    250000   // Absolute max LSB allowed (EMI filter). CC=3200 hits ~80k-120k LSB.
#define MFS_AUTO_TARE_THRESHOLD     50.0f   // Max LSB jump for auto-tare to track
#define MFS_EMA_ALPHA               0.995f  // Auto-tare EMA filter weight
#define MFS_NT_CONVERSION_FACTOR    0.38f   // LSB/uT/CC constant for RM3100


// RM3100 Data Ready Interrupts
#define MFS_PIN_RM3100_TIP_DRDY 1
#define MFS_PIN_RM3100_REF_DRDY 2
#define MFS_PIN_RM3100_NEAR_DRDY 5


//  DISP
#define MFS_PIN_NUM_LCD_CS     (GPIO_NUM_9) 
#define MFS_PIN_NUM_LCD_PCLK   (GPIO_NUM_10)
#define MFS_PIN_NUM_LCD_DATA0  (GPIO_NUM_11)
#define MFS_PIN_NUM_LCD_DATA1  (GPIO_NUM_12)
#define MFS_PIN_NUM_LCD_DATA2  (GPIO_NUM_13)
#define MFS_PIN_NUM_LCD_DATA3  (GPIO_NUM_14)
#define MFS_PIN_NUM_LCD_TE     (GPIO_NUM_21)
#define MFS_PIN_NUM_LCD_RST    (-1)
#define MFS_PIN_NUM_BK_LIGHT   (GPIO_NUM_42)
#define MFS_PIN_NUM_EXIO_INT   (GPIO_NUM_8)

#define MFS_PIN_NUM_BAT_ADC    (GPIO_NUM_4)
#define MFS_PIN_NUM_SYS_OUT    (GPIO_NUM_16)

#define MFS_EXIO_PIN_TOUCH_INT (1ULL << 0)
#define MFS_EXIO_PIN_BL_EN     (1ULL << 1)
#define MFS_EXIO_PIN_IMU_INT1  (1ULL << 2)
#define MFS_EXIO_PIN_IMU_INT2  (1ULL << 3)
#define MFS_EXIO_PIN_RTC_INT   (1ULL << 4)
#define MFS_EXIO_PIN_LCD_RST   (1ULL << 5)
#define MFS_EXIO_PIN_SYS_EN    (1ULL << 6)
#define MFS_EXIO_PIN_NS_MODE   (1ULL << 7)

#define I2C_TOUCH_ADDR                    0x3b
#define MFS_PIN_NUM_TOUCH_RST         (-1)
#define MFS_PIN_NUM_TOUCH_INT         (-1)

#define LVGL_TICK_PERIOD_MS    5
#define LVGL_TASK_MAX_DELAY_MS 500
#define LVGL_TASK_MIN_DELAY_MS 5
#define LVGL_TASK_STACK_SIZE   (8 * 1024)
#define LVGL_TASK_PRIORITY     2

/*bl test*/
#define Backlight_Testing 0

/*ADDR*/
#define MFS_RTC_ADDR 0x51

#define MFS_IMU_ADDR 0x6b

#define USER_DISP_ROT_90    1
#define USER_DISP_ROT_NONO  0
#define MFS_FIRMWARE_VERSION "v5.1.13"

#define Rotated USER_DISP_ROT_NONO   

#define MFS_LCD_H_RES 172   
#define MFS_LCD_V_RES 640

#define LCD_NOROT_HRES     172
#define LCD_NOROT_VRES     640
#define LVGL_DMA_BUFF_LEN (LCD_NOROT_HRES * 64 * 2)
#define LVGL_SPIRAM_BUFF_LEN (MFS_LCD_H_RES * MFS_LCD_V_RES * 2)

#endif

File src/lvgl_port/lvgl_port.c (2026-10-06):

#include <stdlib.h>
#include "freertos/FreeRTOS.h"
#include "freertos/task.h"
#include "lvgl_port.h"
#include "lvgl.h"
#include "esp_adc/adc_oneshot.h"

#include "esp_log.h"
#include "esp_err.h"
#include "esp_timer.h"
#include "../../user_config.h"
#include "driver/gpio.h"
#include "driver/spi_master.h"
#include "esp_lcd_io_spi.h"
#include "esp_lcd_panel_ops.h"
#include "esp_lcd_panel_io.h"
#include "src/axs15231b/esp_lcd_axs15231b.h"
#include "src/tca9554/esp_io_expander_tca9554.h"
#include "../i2c_bsp/i2c_bsp.h"

static const char *TAG = "lvgl_port";
static SemaphoreHandle_t lvgl_mux = NULL;

// UI Elements for Detector
static lv_obj_t * bg_arc_left;
static lv_obj_t * bg_arc_right;
static lv_obj_t * mag_arc;
static lv_obj_t * compass_label_n;
static lv_obj_t * compass_label_e;
static lv_obj_t * compass_label_s;
static lv_obj_t * compass_label_w;
static lv_obj_t * compass_label_ne;
static lv_obj_t * compass_label_se;
static lv_obj_t * compass_label_sw;
static lv_obj_t * compass_label_nw;
static lv_obj_t * crosshair_dot;
static lv_obj_t * mag_label;
static lv_obj_t * title_label;
static lv_obj_t * declination_label;
static lv_obj_t * elevation_label;
static lv_obj_t * sens_label;
static lv_obj_t * polarity_label;
static lv_obj_t * nt_label;
static lv_obj_t * scan_btn;
static lv_obj_t * ip_label;
static lv_obj_t * scan_label;
static lv_obj_t * mute_btn;
static lv_obj_t * mute_label;
static lv_obj_t * wave_btn;
static lv_obj_t * wave_label;
static lv_obj_t * tare_btn;
static lv_obj_t * tare_label;
static int main_tare_state = 0; // 0=RAW, 1=TARE, 2=AUTO
lv_obj_t * cal_progress_bar;
lv_obj_t * cal_status_label;
lv_obj_t * full_cal_btn;
lv_obj_t * full_cal_label;
static bool is_calibrating = false;
static lv_obj_t * wifi_btn;
static lv_obj_t * wifi_label;
lv_obj_t * ui_date_label;
lv_obj_t * ui_time_label;
#include "../settings_manager/settings_manager.h"
#include "../web_server/web_server.h"
#include "../data_logger/data_logger.h"
#include "../screenshot/screenshot.h"

static void mark_settings_dirty() {
    settings_dirty = true;
    last_settings_change_ms = millis();
}

static uint16_t *trans_buf_1 = NULL;
uint8_t *lvgl_dest = NULL;
static SemaphoreHandle_t flush_done_semaphore;
esp_io_expander_handle_t io_expander = NULL;
#define LCD_BIT_PER_PIXEL 16
#define BYTES_PER_PIXEL (LV_COLOR_FORMAT_GET_SIZE(LV_COLOR_FORMAT_RGB565))
#define BUFF_SIZE (MFS_LCD_H_RES * MFS_LCD_V_RES * BYTES_PER_PIXEL)

static const axs15231b_lcd_init_cmd_t lcd_init_cmds[] = 
{
  {0x11, (uint8_t []){0x00}, 0, 100},
  {0x29, (uint8_t []){0x00}, 0, 100},
};

static bool mfs_notify_lvgl_flush_ready(esp_lcd_panel_io_handle_t panel_io, esp_lcd_panel_io_event_data_t *edata, void *user_ctx)
{
  BaseType_t TaskWoken;
  xSemaphoreGiveFromISR(flush_done_semaphore,&TaskWoken);
  return false;
}

static void mfs_increase_lvgl_tick(void *arg)
{
  lv_tick_inc(LVGL_TICK_PERIOD_MS);
}

static void mfs_lvgl_flush_cb(lv_display_t * disp, const lv_area_t * area, uint8_t * color_p)
{
  esp_lcd_panel_handle_t panel_handle = (esp_lcd_panel_handle_t)lv_display_get_user_data(disp);
  lv_draw_sw_rgb565_swap(color_p, lv_area_get_width(area) * lv_area_get_height(area));
#if (Rotated == USER_DISP_ROT_90)
  lv_display_rotation_t rotation = lv_display_get_rotation(disp);
  lv_area_t rotated_area;
  if(rotation != LV_DISPLAY_ROTATION_0)
  {
    lv_color_format_t cf = lv_display_get_color_format(disp);
    /*Calculate the position of the rotated area*/
    rotated_area = *area;
    lv_display_rotate_area(disp, &rotated_area);
    /*Calculate the source stride (bytes in a line) from the width of the area*/
    uint32_t src_stride = lv_draw_buf_width_to_stride(lv_area_get_width(area), cf);
    /*Calculate the stride of the destination (rotated) area too*/
    uint32_t dest_stride = lv_draw_buf_width_to_stride(lv_area_get_width(&rotated_area), cf);
    /*Have a buffer to store the rotated area and perform the rotation*/
    
    int32_t src_w = lv_area_get_width(area);
    int32_t src_h = lv_area_get_height(area);
    lv_draw_sw_rotate(color_p, lvgl_dest, src_w, src_h, src_stride, dest_stride, rotation, cf);
    /*Use the rotated area and rotated buffer from now on*/
    area = &rotated_area;
  }

  const int flush_coun = (LVGL_SPIRAM_BUFF_LEN / LVGL_DMA_BUFF_LEN);
  const int offgap = (MFS_LCD_V_RES / flush_coun);
  const int dmalen = (LVGL_DMA_BUFF_LEN / 2);
  int offsetx1 = 0;
  int offsety1 = 0;
  int offsetx2 = MFS_LCD_H_RES;
  int offsety2 = offgap;

  uint16_t *map = (uint16_t *)lvgl_dest;
  xSemaphoreGive(flush_done_semaphore);
  for(int i = 0; i<flush_coun; i++)
  {
    xSemaphoreTake(flush_done_semaphore,portMAX_DELAY);
    memcpy(trans_buf_1,map,LVGL_DMA_BUFF_LEN);
    esp_lcd_panel_draw_bitmap(panel_handle, offsetx1, offsety1, offsetx2, offsety2, trans_buf_1);
    offsety1 += offgap;
    offsety2 += offgap;
    map += dmalen;
  }
  xSemaphoreTake(flush_done_semaphore,portMAX_DELAY);
  lv_disp_flush_ready(disp);
#else
  const int flush_coun = (LVGL_SPIRAM_BUFF_LEN / LVGL_DMA_BUFF_LEN);
  const int offgap = (MFS_LCD_V_RES / flush_coun);
  const int dmalen = (LVGL_DMA_BUFF_LEN / 2);
  int offsetx1 = 0;
  int offsety1 = 0;
  int offsetx2 = MFS_LCD_H_RES;
  int offsety2 = offgap;

  uint16_t *map = (uint16_t *)color_p;
  xSemaphoreGive(flush_done_semaphore);
  for(int i = 0; i<flush_coun; i++)
  {
    xSemaphoreTake(flush_done_semaphore,portMAX_DELAY);
    memcpy(trans_buf_1,map,LVGL_DMA_BUFF_LEN);
    esp_lcd_panel_draw_bitmap(panel_handle, offsetx1, offsety1, offsetx2, offsety2, trans_buf_1);
    offsety1 += offgap;
    offsety2 += offgap;
    map += dmalen;
  }
  xSemaphoreTake(flush_done_semaphore,portMAX_DELAY);
  lv_disp_flush_ready(disp);
#endif
}
static void TouchInputReadCallback(lv_indev_t * indev, lv_indev_data_t *indevData)
{
  uint8_t read_touchpad_cmd[11] = {0xb5, 0xab, 0xa5, 0x5a, 0x0, 0x0, 0x0, 0x0e,0x0, 0x0, 0x0};
  uint8_t buff[32] = {0};
  ESP_ERROR_CHECK_WITHOUT_ABORT(i2c_master_write_read_dev(disp_touch_dev_handle,read_touchpad_cmd,11,buff,32));
  uint16_t pointX;
  uint16_t pointY;
  pointX = (((uint16_t)buff[2] & 0x0f) << 8) | (uint16_t)buff[3];
  pointY = (((uint16_t)buff[4] & 0x0f) << 8) | (uint16_t)buff[5];
  ESP_LOGI("Touch","%d,%d",buff[0],buff[1]);
  if (buff[1]>0 && buff[1]<5)
  {
    indevData->state = LV_INDEV_STATE_PRESSED;
    if(pointX > MFS_LCD_V_RES) pointX = MFS_LCD_V_RES;
    if(pointY > MFS_LCD_H_RES) pointY = MFS_LCD_H_RES;
    indevData->point.x = pointY;
    indevData->point.y = (MFS_LCD_V_RES-pointX);
  }
  else 
  {
    indevData->state = LV_INDEV_STATE_RELEASED;
  }
}

bool mfs_lvgl_lock(int timeout_ms)
{
  const TickType_t timeout_ticks = (timeout_ms == -1) ? portMAX_DELAY : pdMS_TO_TICKS(timeout_ms);
  return xSemaphoreTake(lvgl_mux, timeout_ticks) == pdTRUE;       
}

void mfs_lvgl_unlock(void)
{
  assert(lvgl_mux && "lvgl_mux must exist");
  xSemaphoreGive(lvgl_mux);
}
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

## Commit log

2026-08-28 Save state: Phase 3 (v3.1.0) architecture refactor
    [2026-08-26_17-15-19.913-240_log.csv, 2026-08-26_17-23-10.873-240_calibration.csv, 2026-08-26_19-17-59.032-240_calibration.csv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]
2026-08-28 Docs: Add CAT6 color code allocation and reference to Cable_Color_Code.xlsx
2026-08-28 UI: Fix msgbox width on 172px screen, add future_ideas.md
    [lvgl_port.c]
2026-08-28 Bump version to v3.1.2 for LVGL msgbox fix
    [user_config.h]
2026-08-28 Phase 5: Add Madgwick AHRS fusion and Geiger Counter Audio Mode
    [Cable_Color_Code.xlsx, Magnetic Wand.rev1.dwg]
2026-08-28 Fix compilation error: Update log_data prototype in data_logger.h
2026-08-28 Fix bug: Log actual battery voltage as float instead of hardcoded 3.0
    [Magnetic_Field_Scanner.ino, data_logger.cpp]
2026-08-28 Version bump to v3.2.1: Fix Madgwick NaN bug
    [user_config.h]
2026-08-28 Fix data_logger: Add missing qw, qx, qy, qz arguments to snprintf
    [data_logger.cpp]
2026-08-28 Version bump to v3.2.2: Fix snprintf missing args bug
    [user_config.h]
2026-08-28 Phase 6: Implement Quaternion Sensor Fusion for Radar Dot stabilization
2026-08-28 Phase 7: Upgrade to 9-DOF Madgwick filter with Compass integration
2026-08-28 docs: Document sensor coordinate alignment discovered in Phase 7
2026-08-29 fix: Map all 9-DOF inputs to strict NED coordinate frame
    [Magnetic_Field_Scanner.ino, user_config.h]
2026-08-29 feat: Add magnetic declination and Videogame Minimap UI
2026-08-29 fix: Correctly parse mag_declination_deg from JSON
    [settings_manager.cpp]
2026-08-29 fix: Compass labels not animating due to missing loop insertion
    [lvgl_port.c, user_config.h]
2026-08-29 fix: Correct NED Y-axis mapping and append Yaw/Declination to CSV log
    [Magnetic_Field_Scanner.ino, data_logger.cpp, user_config.h]
2026-08-29 fix: Move Elevation readout to top-left of HUD
    [lvgl_port.c, user_config.h]
2026-08-29 fix: Bypass LVGL float formatting limitation using snprintf
    [lvgl_port.c, user_config.h]
2026-08-29 fix: Implemented Gyro FOC to solve wild compass spin; Fixed CSV payload
    [Magnetic_Field_Scanner.ino, data_logger.cpp, settings_manager.cpp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]
2026-08-29 feat: Mirror settings and calibration writes to FFat when SD is mounted
2026-08-29 fix: Correct indentation in Python calibration script
2026-08-29 chore: Update golden files and example logs with latest tests; add 3D visualizer script
    [2026-08-26_17-15-19.913-240_log.csv, 2026-08-26_17-23-10.873-240_calibration.csv, 2026-08-26_19-17-59.032-240_calibration.csv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]
2026-08-29 feat: Upgrade on-wand calibration to 64-bit double precision; Boost Madgwick Beta to 0.5 to suppress residual MEMS gyro drift
    [matrix_math.h, user_config.h]
2026-08-29 fix: Type mismatch in matrix multiplication due to 64-bit upgrade
    [data_logger.cpp, matrix_math.h]
2026-08-29 fix: Remove faulty IMU rotation math that scrambled the Gyro FOC; set default imu_rotation to 0.0
    [Magnetic_Field_Scanner.ino, user_config.h]
2026-08-29 fix: Restore proper imu_rotation_deg mapping for angled mechanical enclosure; ensure FOC is applied before rotation
    [Magnetic_Field_Scanner.ino, user_config.h]
2026-08-29 fix: Python script now preserves the physical imu_rotation_deg from existing calibration file
2026-08-29 feat: Implement Dynamic Auto-Zero to eliminate MEMS gyro drift and g-sensitivity in real-time
    [Magnetic_Field_Scanner.ino, user_config.h]
2026-08-29 fix: Silence Auto-Zero serial spam; only print message once per stationary event
    [Magnetic_Field_Scanner.ino, user_config.h]
2026-08-29 fix: Invert imu_rotation_deg mathematical sign to properly un-rotate the physical IMU enclosure tilt
    [Magnetic_Field_Scanner.ino, user_config.h]
2026-08-29 fix: Convert Gyro to Radians for Madgwick; Fix Madgwick sample frequency to 50Hz to eliminate 30-second initialization lag
    [user_config.h]
2026-08-29 fix: Correctly apply Gyro Radians/sec conversion for Madgwick (previous patch failed)
    [Magnetic_Field_Scanner.ino, user_config.h]
2026-08-29 docs: Perform high-fidelity context update capturing deep learnings on IMU math, Madgwick fusion, and Dynamic Auto-Zero
2026-08-29 fix: Rotate sensor vectors in pure hardware frame before mapping to NED to prevent mirrored-axis geometric reflection
    [Magnetic_Field_Scanner.ino, user_config.h]
2026-08-29 fix: Rewrite standard 3D rotation matrix for Y-axis (Pitch) to correct sign inversion error
    [Magnetic_Field_Scanner.ino, user_config.h]
2026-08-29 fix: Remove all axis inversions for NED mapping. BMI270 is natively perfectly Right-Handed NED aligned.
    [Magnetic_Field_Scanner.ino, user_config.h]
2026-08-29 fix: Enable the physical Gyroscope MEMS oscillator in QMI8658 CTRL7 register (was previously turned off)
    [imu_bsp.c, user_config.h]
2026-08-29 fix: Reduce Madgwick Beta to 0.05. Gyro is now alive, so high Beta is no longer needed and causes Magnetic distortion to bleed into Pitch/Roll.
    [user_config.h]
2026-08-29 fix: Actually change sampleFreq to 50Hz (previous agent hallucinated the fix in handoff notes but left it at 400Hz). Gyro was integrating at 1/8th speed.
    [user_config.h]
2026-08-29 v3.6.15: Fix Magnetometer NED mapping, update Python tools to v1.1.1, and sync docs
    [Magnetic_Field_Scanner.ino, settings_manager.cpp, user_config.h]
2026-08-29 v3.6.17: Fix on-wand calibration column parsing and ellipsoid denominator bug
    [data_logger.cpp, matrix_math.h, user_config.h]
2026-08-29 v3.6.18: LVGL UI Redesign (Main Screen Tare & Embedded Calibration)
    [Magnetic_Field_Scanner.ino, data_logger.cpp, lvgl_port.c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]
2026-08-29 v3.6.19: Fix compile errors (lvgl.h header include, ui_data scope)
    [Magnetic_Field_Scanner.ino]
2026-08-29 v3.6.19: Fix compile error (is_calibrating scope in lvgl_port.c)
    [lvgl_port.c]
2026-08-29 v3.6.20: Fix Kabsch alignment (rotate Tip instead of Ref) & Add JSON tags
    [data_logger.cpp, settings_manager.cpp, user_config.h]
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2026-08-29 v3.6.22: Fix variable shadowing error in JSON generation
    [settings_manager.cpp, user_config.h]
2026-08-29 v3.6.23: Fix calibration screen UI layout and clipping
    [lvgl_port.c, user_config.h]
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2026-08-29 v3.6.26: Add timer to reset calibration labels
    [lvgl_port.c, user_config.h]
2026-08-30 docs: Add Property Pin detection depth use-case to README
2026-08-30 scripts: Invert Z axis for pure NED plotting
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2026-08-30 refactor: Extract SensorFusion class from main loop
    Moves all matrix math, AHRS, and true-Z geometry into a dedicated class to resolve the monolithic sensorTask design.
    [Magnetic_Field_Scanner.ino]
2026-08-30 v3.6.27: Update documentation for SensorFusion refactor
    Bumps firmware version and documents the extraction of mathematical processes into the new SensorFusion class to adhere to SRP.
2026-08-30 fix: Correct include paths for SensorFusion
    The Arduino builder requires 'src/' prefix for headers not in the sketch root.
    [Magnetic_Field_Scanner.ino]
2026-08-30 fix: Resolve compilation errors from SensorFusion refactor
    1. Fixes missing #include guards in settings_manager.h. 2. Adds SensorFusion::scaleTare() to handle dynamic cycle count baseline scaling. 3. Removes duplicated macros in SensorFusion.h. 4. Fixes undeclared raw_acc and raw_gyr arrays in the .ino file.
    [Magnetic_Field_Scanner.ino]
2026-08-30 fix: Resolve PMIC latch delay causing power button to require 4-second hold
    Moves I2C and IO Expander initialization to the absolute beginning of setup() so that MFS_EXIO_PIN_SYS_EN is asserted HIGH immediately, latching the battery PMIC on instantly. Also updates project_overview.md and session_handoff.md with these hardware quirks.
    [Magnetic_Field_Scanner.ino]
2026-08-30 docs: Correct 400Hz myth and document true hardware/software polling rates
    At 800 cycle count, the hardware updates at 9Hz. The software caps at 50Hz via a vTaskDelay. Removes all false references to 400Hz polling.
2026-08-31 v4.0.0: Refactor firmware to true zero-latency ISR architecture
    Migrated from a 50Hz software-throttled polling loop to a zero-latency ISR architecture using FreeRTOS EventGroups. Added dynamic Madgwick dt calculation to neutralize time-dilation distortion. Inserted SD logging decimation at high cycle counts to prevent SPI blocking. Updated cycle count depth UI palette.
    [Magnetic_Field_Scanner.ino, data_logger.cpp, lvgl_port.c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]
2026-08-31 docs: add characterization benchmark dataset, analysis reports, and v5.0.0 implementation plan
    [cal_1_calibration_2026-08-29_17-11-49-240.csv, cal_2_calibration_2026-08-30_09-19-37-240.csv, cal_3_calibration_2026-08-30_09-24-25-240.csv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]
2026-09-02 v5.0.0: Unified nT Architecture Refactor, I2C 200kHz, DRDY lapping fix
    [Magnetic_Field_Scanner.ino, data_logger.cpp]
2026-09-02 v5.0.0: Regenerate calibration.json in nT scale using v2.0.0 script
2026-09-02 v5.0.0: Fix Vector3Float cast compilation error
    [Magnetic_Field_Scanner.ino]
2026-09-02 v5.0.0: Fix remaining compilation syntax errors
    [lvgl_port.c]
2026-09-02 v5.0.0: Fix trailing closing brace in lvgl_port.c
    [lvgl_port.c]
2026-09-02 v5.0.0: Fix LVGL float formatting string and remove RAW prefix
    [lvgl_port.c]
2026-09-02 v5.0.1: Fix UI raw magnitude data feed
    [Magnetic_Field_Scanner.ino]
2026-09-02 v5.0.3: Remove text suffixes from UI to fit on screen
    [cal_1_calibration_2026-08-29_17-11-49-240.csv, cal_2_calibration_2026-08-30_09-19-37-240.csv, cal_3_calibration_2026-08-30_09-24-25-240.csv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]
2026-09-02 v5.0.4: Fix I2C hardware lockups and watchdog panics during cycle count changes
    [Magnetic_Field_Scanner.ino, i2c_bsp.c, user_config.h]
2026-09-02 v5.0.5: Fix CC=3200 sensor truncation by lowering TMRC to 0x99 (4.5Hz)
    [Magnetic_Field_Scanner.ino, user_config.h]
2026-09-02 v5.0.6: Fix CC=3200 lockup by setting TMRC to max (600Hz) and fix blind I2C recovery reads
    [Magnetic_Field_Scanner.ino, user_config.h]
2026-09-02 v5.0.8: Fix CC=3200 screen freeze caused by Absolute EMI Glitch Filter rejecting valid data
    [user_config.h]
2026-09-02 v5.0.9: Fix idle watchdog triggers by using safe TMRC mappings and refining consecutive read checks
    [Magnetic_Field_Scanner.ino, user_config.h]
2026-09-03 docs: Update README, project_overview, hyper-context-anchor, and session_handoff for v5.0.9 architecture
    [cal_1_calibration_2026-08-29_17-11-49-240.csv, cal_2_calibration_2026-08-30_09-19-37-240.csv, cal_3_calibration_2026-08-30_09-24-25-240.csv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]
2026-09-03 v5.1.0: Migrate from CMM to Single Measurement Polling (POLL) to eliminate sensor phase drift and I2C collisions
    [Magnetic_Field_Scanner.ino, user_config.h]
2026-09-03 v5.1.1: Fix RM3100 Tip initialization failure by enforcing IDLE mode before cycle count updates; align UI color bands and gauge range for RAW vs TARE
    [Magnetic_Field_Scanner.ino, lvgl_port.c, user_config.h]
2026-09-03 docs: Restore Measurement Precision title and explicitly define X/Y/Z axis testing
2026-09-03 docs: Completely overhaul README.md to reflect v5.1.x POLL architecture, universal calibration, dynamic UI scaling, and characterization sweeps
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2026-09-04 docs: Rename MID to NEAR, rewrite architecture docs for v5.1.x, create BOM and CDR
    [Board_Holder_REF&NEAR_Part1_(1.75).stl, Board_Holder_REF&NEAR_Part2_(0.75).stl]
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2026-09-04 refactor: rename FIRMWARE_VERSION to MFS_FIRMWARE_VERSION across the codebase to prevent namespace collisions
    [Magnetic_Field_Scanner.ino, data_logger.cpp, lvgl_port.c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]
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2026-09-04 docs: append imu_temp and Euler angles to log output format in user_manual
2026-09-09 v5.1.3: fix(audio): remove legacy CC scaling from I2S task since magnitude is already in nT
    [Magnetic_Field_Scanner.ino, user_config.h]
2026-09-10 docs: save preliminary v5.1.2 characterization logs and analysis artifacts
    [log_arhs_200_log_2026-09-09_15-24-14-240.csv, log_arhs_400_log_2026-09-09_15-24-43-240.csv, log_noise_1600_log_2026-09-09_15-18-28-240.csv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]
2026-09-11 docs: generate official v5.1.3 characterization datasheet and pdf
    [cal_1_calibration_2026-09-11_08-25-06-240.csv, cal_2_calibration_2026-09-11_08-26-52-240.csv, cal_3_calibration_2026-09-11_08-28-29-240.csv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]
2026-09-11 docs: correct hardware calibration processing time logic based on field observations
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2026-09-11 docs: regenerate v5.1.3 datasheet with 800, 1600, and new 3200 CC sweeps
    [log_rebar_1600_log_2026-09-11_17-38-58-240.csv, log_rebar_3200_log_2026-09-11_09-12-26-240.csv, log_rebar_3200_log_2026-09-11_17-41-13-240.csv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]
2026-09-14 docs: sync all documentation to v5.1.4 and regenerate PDFs
    [Cable_Color_Code.xlsx]
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2026-09-14 docs: deprecate legacy example_logs folder in favor of characterization folder
    [calibration_2026-08-29_06-25-38-240.csv, sensor_orientation_dance_log_2026-08-29_06-24-04-240.csv, sensor_orientation_dance_log_2026-08-29_07-36-27-240.csv]
2026-09-14 docs: deprecate obsolete golden-files folder
    [golden-calibration_2026-08-29_07-39-34-240.csv]
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2026-09-14 docs: explicitly highlight Kabsch and Madgwick 9-axis sensor fusion algorithms in README for SEO
2026-09-14 docs: insert new hero images to README and optimize pdf scaling script
2026-09-14 docs: update folder overview to correctly acknowledge existence of BOM and wiring diagram
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2026-09-17 docs: rename v5.1.3 characterization folder to reflect v5.1.4 compatibility and add new logs
    [Saturation Data Detail on Sensor Core Saturation.xlsx, cal_1_calibration_2026-09-11_08-25-06-240.csv, cal_2_calibration_2026-09-11_08-26-52-240.csv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]
2026-09-18 docs: add case study and comparative plots proving single-axis core saturation and 45-degree mechanical solution
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2026-09-18 docs: recreate core saturation case study focusing on cc=3200 flatline and 45-45 restoration
2026-09-18 docs: embed photo of the cardboard 45-degree testing jig into the saturation case study
2026-09-18 docs: demystify the math tax and explicitly analyze rtos sd card timestamp jitter
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2026-09-19 docs: add real world field validation and gradiometer penalty section
    [log_real_pin_direct_1600_log_2026-09-19_09-30-14-240.csv, log_real_pin_direct_200_log_2026-09-19_09-22-46-240.csv, log_real_pin_direct_3200__log_2026-09-19_09-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]
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2026-10-06 v5.1.9: replace strength arc coloring with pure polarity tracking
    [lvgl_port.c, user_config.h]
2026-10-06 v5.1.11: prevent font wrapping by reducing font size and widening container; add commas to nT sub-label
    [lvgl_port.c, user_config.h]
2026-10-06 v5.1.12: revert label width to 172 to respect physical screen bounds of waveshare 3.49
    [lvgl_port.c, user_config.h]
2026-10-06 v5.1.14: revert V_RES back to 640 (screen is actually a 3.49-inch 172x640 bar LCD)
    [user_config.h]
